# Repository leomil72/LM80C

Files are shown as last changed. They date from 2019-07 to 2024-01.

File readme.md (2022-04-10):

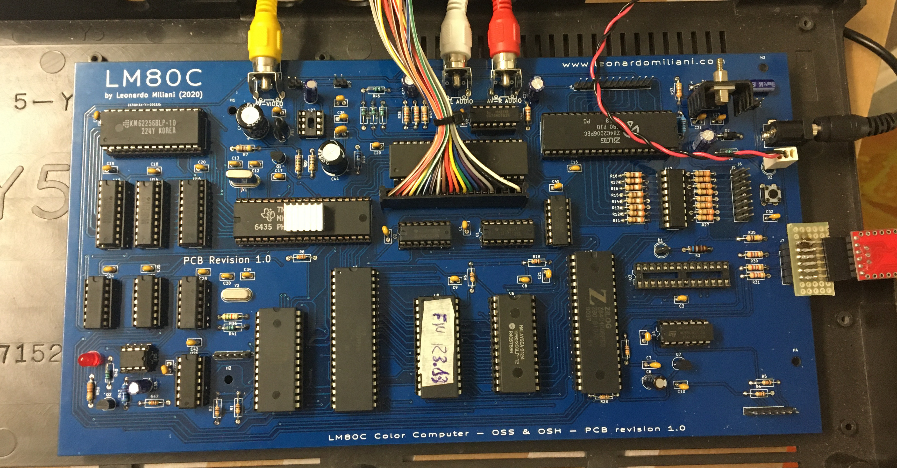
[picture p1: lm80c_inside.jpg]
LM80C, a Z80 -based computer LM80C, a Z80-based computer


# LM80C Color Computer - A Z80-based homebrew computer

> This is the official repo of the **LM80C Color Computer**, an 8-bit home computer based on the Z80 CPU entirely developed since 2019 by **Leonardo Miliani**. Here you can find schematics, code and other stuff that you can use to replicate this project and build your own homebrew computer as a sort of "back to the old, good, days of 8-bit systems".
>
> Project main page: [LM80C](https://www.leonardomiliani.com/?page_id=1534&lang=en)
>
> Tags: z80, zilog, homebrew, 8-bits, computer, lm80c, ctc, pio, sio, tms9918a, ay-3-8910, ym2149f

---

## Getting started

- [Overview](#overview)
- [What you need](#what-you-need)
- [Folder organization](#folder-organization)
- [Compilation](#compilation)
- [Emulation](#emulation)
- [Z88DK Support](#Z88DK-Support)
- [FAQ](#faq)
- [Support](#support)
- [Donations](#donations)
- [License](#license)

---

## Overview

The **LM80C** is an 8-bit home-computer built around the Zilog Z80 CPU with video and audio capabilities. It's a stand-alone system thanks to its integrated keyboard that permits to use it without the necessity of host computers, usually used as input/output devices in other similar projects. With the LM80C BASIC you can write your own games, programs, and much more.

### Models
Actually, there is only one model of the computer: the **LM80C 64K Color Computer**. Originally, there was also the **LM80C Color Computer** but it has been considered as DEPRECATED and its developmente and/or supporto has been cheased. There were a couple of differences between the two: the former only had 32KB of SRAM and an interface to SD cards based on an Atmega328P as a mass storage (never developed, my fault), while the latter has 64KB of SRAM and a new mass storage interface based on Compat Flash cards, perfectly supported.

### Main features

  **LM80C 64K Color Computer**

- CPU: Zilog Z80B@3.68 MHz
- Memory:
  - ROM: 32KB (with built-in firmware & BASIC)
  - RAM: 64KB SRAM
- Video:
  - TMS9918A with 32KB of dedicated VRAM (2x 16K banks)
  - composite output
  - 256x192 pixels, 15 colors, 32 sprites
- Audio:
  - Yamaha YM2149F (or GI AY-3-8910)
  - 3 analog channels with tone&noise generation
  - envelope control
  - 2x8-bit I/O ports
- I/O capabilities:
  - Z80 PIO:
    - parallel input/output periphery
    - 2x8-bit ports
    - 4 operatin modes
  - Z80 SIO:
    - serial input/output periphery
    - 2 serial ports
    - higly configurable
    - software-adjustable baude rates
  - Z80 CTC:
    - timer/counter with 4 channels
   - generate system ticks and baud rates
- Keyboard:
  - external keyboard with 64 keys (I used a Commodore 16 keyboard, that has 66 keys but only 64 unique keys due to double connections for SHIFT and SHIFT/LOCK)
- Mass storage:
  - support for Compact Flash memory cards
    - disk formatting/renaming
    - load/save/erase of BASIC, binary, and sequential files;

Thanks to the bank switching mechanism implemented into the computer, the machine can use the whole amount of 64KB of SRAM. The same mechanism is used to provide 2x 16K banks of VRAM to the VDP so that 2 entire video framebuffers can be loaded and stored into the VRAM.

**LM80C Color Computer** (DEPRECATED)

- CPU: Zilog Z80B@3.68 MHz
- Memory:
  - ROM: 32KB (with built-in firmware & BASIC)
  - RAM: 32KB SRAM
- Video:
  - TMS9918A with 16KB of dedicated VRAM
  - composite output
  - 256x192 pixels, 15 colors, 32 sprites
- Audio:
  - Yamaha YM2149F (or GI AY-3-8910)
  - 3 analog channels with tone&noise generation
  - envelope control
  - 2x8-bit I/O ports
- I/O capabilities:
  - Z80 PIO:
    - parallel input/output periphery
    - 2x8-bit ports
    - 4 operatin modes
  - Z80 SIO:
    - serial input/output periphery
    - 2 serial ports
    - higly configurable
    - software-adjustable baude rates
  - Z80 CTC:
    - timer/counter with 4 channels
   - generate system ticks and baud rates
- Keyboard:
  - external keyboard with 64 keys (I used a Commodore 16 keyboard, that has 66 keys but only 64 unique keys due to double connections for SHIFT and SHIFT/LOCK)
- More to come:
  - support for SD memory cards

*IMPORTANT NOTE*: due to the release of the LM80C 64K model, the development of the LM80C has been halted. At the moment, only software improvements for the LM80C BASIC are still developed and ported from the bigger brother. Since this downgrade to a minor model, the support for SD cards is not developed anymore. The PCB is basically still printable but please don't populate the SD interface portion with any of the components since none of them will be used.

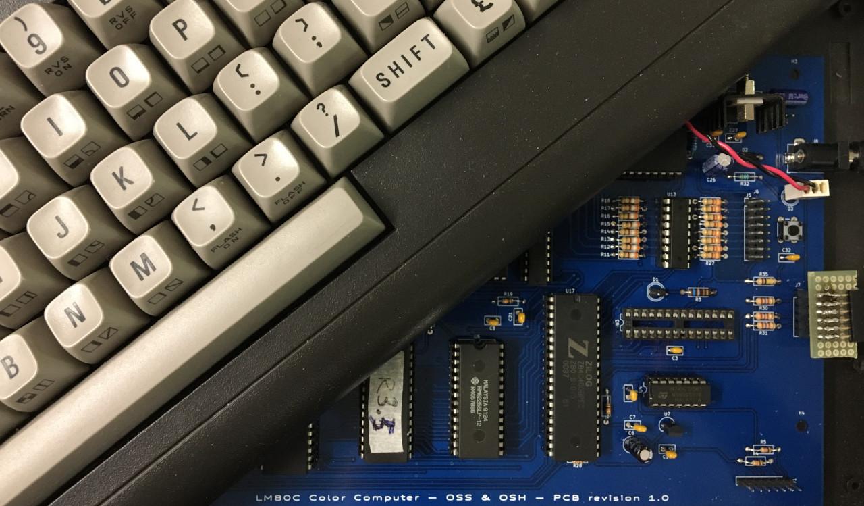
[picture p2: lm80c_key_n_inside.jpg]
LM80C motherboard inside its case


### BASIC

The **LM80C BASIC** is a dialect of the BASIC, a versatile and user-friendly programming language, the de-facto standard of the '80s since it was integrated into almost every 8-bit home computer. It derives from Nascom BASIC, that in turn derives from Microsoft Z80 BASIC 4.7. The LM80C BASIC is more than just a derivative language: in fact, it has its own set of commands and functions to take advantage of the specific LM80C hardware, like statements to draw point, lines, and circles, change foreground and background colors, move the cursor, play a tone or a noise, open/close the serial port, etc. It lets you to write good BASIC games, like "Lunar Lander", see below:
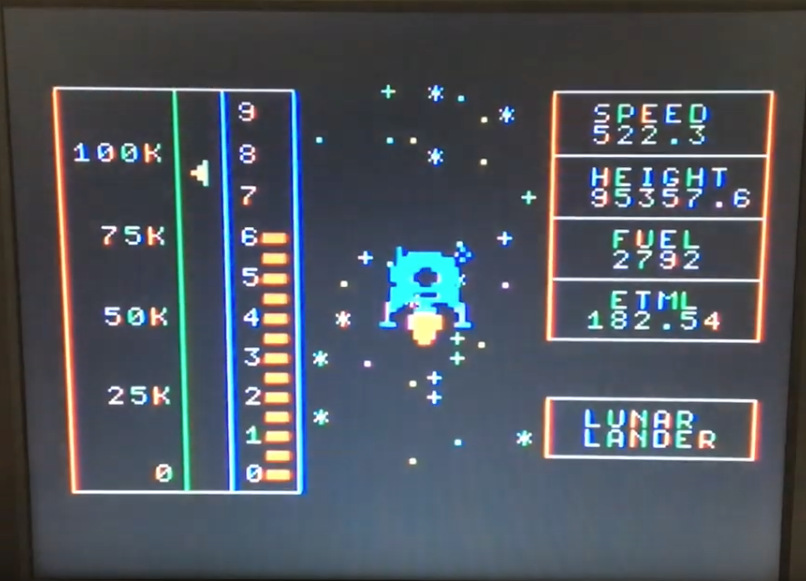
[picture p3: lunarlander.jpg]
Lunar Lander on LM80C


---

## What you need

Before to start building your own LM80C computer you need several things:
- of course, you need some hardware (electronic components, solder, breadboards, chips, etc.);
- some software (code editor & assembler);
- a CAD (to open schematics files and to generate Gerber files to make the PCB).
- some skills (you may be able to assemble a prototype, program it, burn a ROM file, etc.).

### Electronic parts
Passive electronic components can be grabbed anywhere: there are a lot of difference sources, like auction sites, big resellers, and local shops, too. The main chips, the Z80 family chips, are also widely available since the manufacturer, Zilogs, still continue to produce and commercialize them. More effort is needed to find the video and audio chips. The VDP and PSG are still available from China but, while the video chip is very common (in the past there has been over-production so a lot of spare components are still available), the audio chip is more rare and it is easy to find counterfit parts that doesn't work.

### Software
Personally I'm using [Visual Studio Code](https://code.visualstudio.com/) to write the ASM files: it's free, based on an open source project, and multi-platform (do not confuse with Visual Studio IDE). The extension to highlight the assembly code is [Z80 ASM](https://github.com/Imanolea/z80asm-vscode). Visual Code is a very complete editor and you can use for every language you use. Another good editor is [ATOM editor](https://atom.io) to edit the code, with [Language-assembler-SJASMPLUS](https://atom.io/packages/language-assembler-sjasmplus) package to highlight the Z80 assembly code. I prefer the former because it's lighter. 

To compile binaries I actually use [SJASMPlus](https://github.com/z00m128/sjasmplus), because it's multi-platform (MacOS/Linux/Windows) and has a lot of features, like macros, support for in-source LUA scripting, and much more. But you may use the assembler you want. However, for your commodity, the latest precompiled binary file, ready to be burned into an EEPROM, is always available.

To open/modify schematics you need a CAD: I use [KiCad](https://www.kicad.org/), that (IMHO) is the best choice, since it's free and doesn't have the limitations of the freeware version of [EagleCAD](https://www.autodesk.com/products/eagle/overview), that can't let you create a board bigger than 80 square cms., and the LM80C PCB is much bigger. However, I've also added PDF files if you just want to look at the schematics but don't want/need any additional software to open the schematics.

### Hardware
To burn the binaries on the (E)EPROM chips I used a modified version of [TommyPROM](https://github.com/leomil72/TommyPROM) so that I can use 74HCT595 shift registers, but you can use any (E)EPROM programmer you have. If you want to replicate my programmer, you need an [Arduino/Genuino Uno](https://www.arduino.cc) board. Please buy a *genuine board*, not a counterfit one, to help the open-source project. 

### Prototyping
I strongly recommend you to assemble a prototype on breadboards to be sure that everything is working right. The pictures below represent the LM80C during its development:
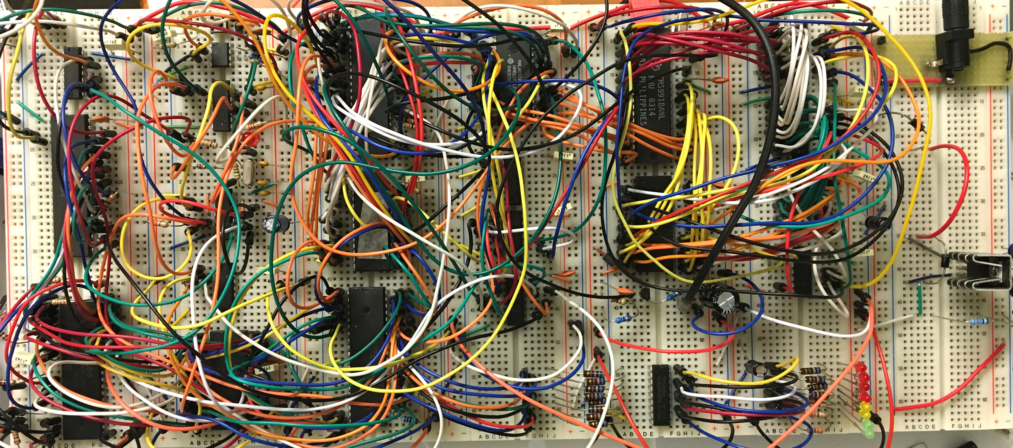
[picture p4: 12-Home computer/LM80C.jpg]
LM80C prototype, built upon breadboards


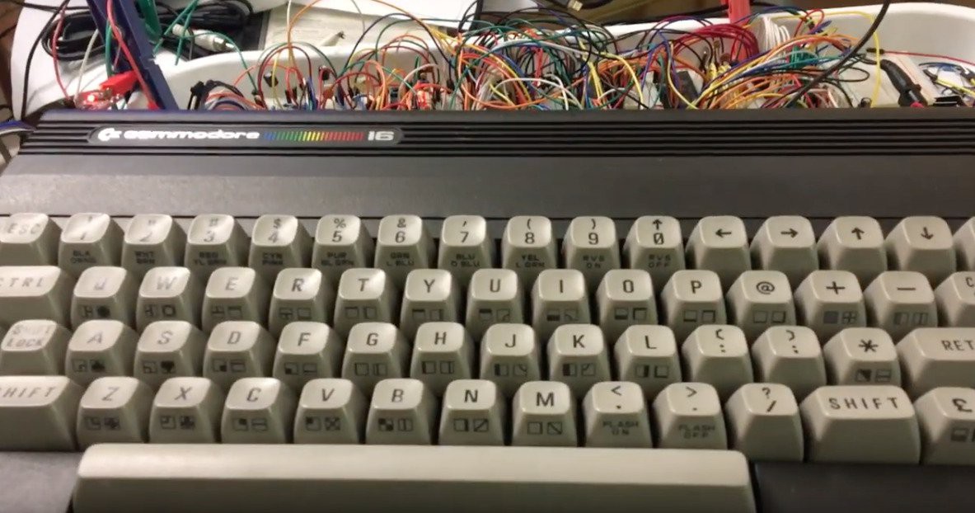
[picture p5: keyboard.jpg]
LM80C keyboard over the breaboards


---

## Folder organization
The files in this repo are organized in folders:
- "12-Home Computer": this folder contains the main ASM file to compile the latest firmwares of the LM80C/LM80C 64K Color Computer.
- "BASIC examples": this folder contains BASIC programs that can be loaded and executed with the integrated LM80C BASIC interpreter. If the name contains a release version (i.e. R20), it means it's the minimum firmware release required to run such program, because it makes use of some statements not present in previous releases.
-  "Legacy": old firmware are stored into this folder. Folders whose names start with "01-" through "09-" contain the first tests I made with the computer without the video section, that you can replicate to work solely through the serial line. Folders whose names start with "10-" and "11-" contain the releases that had preliminary support for video output. "Legacy cores" contains the old firmwares of the latest hardware version of the computer. Every release adds some functionality to the original BASIC. The greater the release number is, the newer the firmware is.
- "Rom": this folder contains pre-compiled binary files, ready to be burned into the EEPROM chip, and ".lst" files.
- "Schematics": this folder contains the KiCad files of the current hardware revision of the computer, plus some PDF files including the complete schematics of the computer.
- "include": this folder contains the sub-folders with the files needed to compile the firmware. They are: "basic", "bootloader","psg", and "vdp". Each sub-folder contains the file of the corresponding module.
- "manuals": this folder contains useful manuals for the CPU, the peripheral chips, the video and audio chips, and a couple of  files that illustrate the main features of the LM80C and the reference manual of the LM80C BASIC language.

---

## Compilation
To compile the firmware, first download or clone the repo on your computer, than go into the "12-Home computer" folder, copy inside it the executable of SJAsmPlus specific for your OS, open a terminal in it, then give this command:
`./sjasmplus --lst --lstlab LM80-firmware-rx.yy.asm`

`./sjasmplus --lst --lstlab LM80C_64K-firmware-rx.yy.asm`

where "X.YY" is the release you want to compile. After the compilation has finished, you'll find a file with extension `.bin` that you can burn into the EEPROM. Another file with extension `.lst` is created: this is useful to get addresses of entry point functions and memory registers.

---

## Emulation
There is an [LM80C online emulator](https://github.com/nippur72/lm80c-emu), written in Javascript by Antonino Porcino, that can be used to see how the real machine acts and works: you can test directly in your browser by opening [this link](https://nippur72.github.io/lm80c-emu/). 
These are the latest releases that can be launched:

[LM80C with Z88DK support](https://nippur72.github.io/lm80c-emu/?rom=314)

[LM80C 3.19 (latest firmware for 32K model)](https://nippur72.github.io/lm80c-emu/?rom=319)

[LM80C 64K (with integrated DOS)](https://nippur72.github.io/lm80c-emu/?rom=64K119)

---

## Z88DK Support
The latest releases of [Z88DK](https://github.com/z88dk/z88dk) support the compilation of C programs for LM80C Color Computer. You need to grab one of the nightly build. After the compilation, a file with extesion `.prg` is basically a big file composed by a BASIC file that is just a simple loader that start the execution of a bigger machine language program. At the moment the compiled files only support the version R3.14 of the LM80C Color Computer and can be launched in the emulator by simply draggind them into the emulator window once launched it and then by typing RUN.

## FAQ

- **How can I clone this repo?**
  - On your desktop computer, by using a GUI frontend like SmartGit, or via a terminal by typing the following command ```git clone https://github.com/leomil72/LM80C```
  - Online, by clicking on the "Fork" button
- **How can I download the files?**
  - By clicking the green top-right "Clone or Download" and then by clicking on "Download ZIP"
- **How do I write and compile an ASM source file?**
  - You need an editor to write the source code and then an 'assembler' to compile the binary file. Please look at the "Software" section above.
- **How do I burn the binary file into the EEPROM?**
  - You need an (E)EPROM programmer, a device that can be connected to your computer and that can write the data into the memory chip. You can buy a programmer from internet or build your own device like me.
- **Where can I find the chips you're using in the LM80C computer?**
  - Zilog still manufactures the Z80 family chips, so you can get them from almost any good reseller, or, alternatively, new/used parts can be catched from online auctions sites. The 74HCTxx integrated are very common, so you shouldn't have any problem to grab them. The VDP and PSG chips are only available as used parts from several eastern resellers. Pay attention that you can easily buy a counterfit chip so if it won't work, before to think that your computer is badly assembled, try another part.
- **The software seems not to be working/the hardware I built following your schematics doesn't work: where can I find help? Can I write to you?**
  - The project is released "as is", without any warranty/responsability: despite I've tested it and I'm currently using it, I can not guarantee that it is completely error-free, nor that it can run with no issues for a relitively long time, nor that there are no errors in the code/schematic files that are online. So, please do NOT write me to complain about something's not working. Open an "issue" or a "pull request". Thank you.

---

## Support

You can find more about me on my website at <a href="https://www.leonardomiliani.com/?lang=en" target="_blank">www.leonardomiliani.com</a>.

---

## Donations

- If you want to help me maintain my site, my projects, and keep me rolling on, you may consider to make a small donation with <a href="https://www.paypal.me/LeonardoMiliani" target="_blank">Paypal</a>.

---

## License

- Some portions of code are copyright <a href="http://searle.hostei.com/grant/" target="_blank">Grant Searle</a>
- Some portions of code are copyright <a href="http://www.train­z.de" target="_blank">Mario Blunk</a>
- BASIC code is copyright <a href="http://www.microsoft.com" target="_blank">Microsoft</a>
- Some commercial names (like KiCAD, EagleCAD, Visual Studio Code) lead to the corresponding owners.
- The rest of the stuff is my own work and is distribuited under the [Gnu GPL Licence 3.0](https://opensource.org/licenses/GPL-3.0).

The names "LM80C", "LM80C 64K", "LM80C Color Computer", "LM80C 64K Color Computer", and "LM80C BASIC", the "rainbow LM80C" logo, the LM80C schematics, the LM80C sources, and this work belong to Leonardo Miliani. 

The "rainbow LM80C" logo and the "LM80C/LM80C Color Computer/LM80C 64K/LM80C 64K Color Computer" names can not be used in any work without my explicit permission. You are allowed to use the "LM80C" and "LM80C 64K" names only in reference to or to describe the LM80C/LM80C 64K Color Computers.

The LM80C/LM80C 64K schematics and source codes are released under the GNU GPL License 3.0 and in the form of "as is", without any kind of warranty: you can use them at your own risk. You are free to use them for any non-commercial use: you are only asked to maintain the copyright notices, to include this advice and, if you intend to re-distribute them, the note to the attribution of the original works to Leonardo Miliani. For any other use, please contact me by opening an issue.

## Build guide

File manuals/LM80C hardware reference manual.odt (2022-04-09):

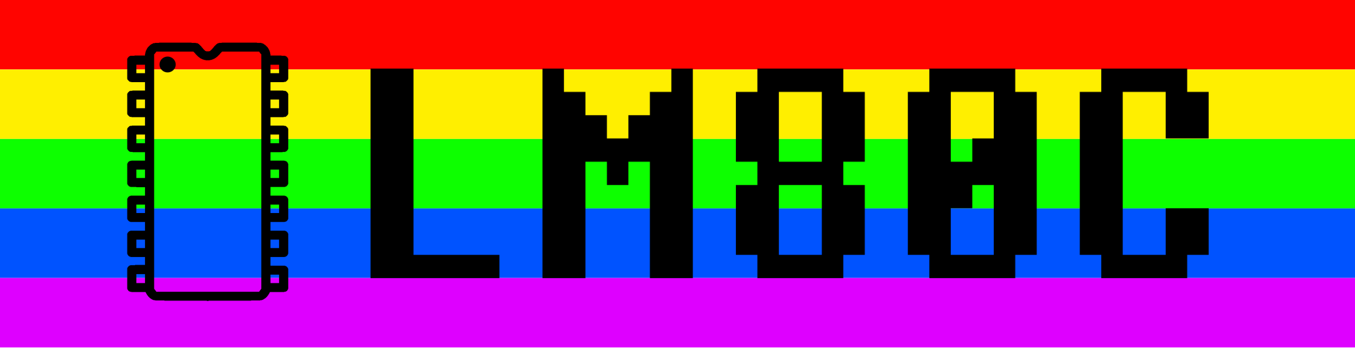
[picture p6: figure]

HARDWARE

REFERENCE MANUAL

LM80C COLOR COMPUTER &

LM80C 64K COLOR COMPUTER

HARDWARE REFERENCE MANUAL

This release covers the

LM80C Color Computer

and

LM80C 64K Color Computer

Latest revision on 09/04/2022

### Copyright notices:

The names “LM80C”, “LM80C Color Computer”, “LM80C BASIC”, and “LM80C DOS”, the “rainbow LM80C” logo, the LM80C schematics, the LM80C sources, and this work belong to Leonardo Miliani, from here on the “owner”.

The “rainbow LM80C” logo and the “LM80C/LM80C Color Computer/LM80C 64K Color Computer” names can not be used in any work without explicit permission of the owner. You are allowed to use the “LM80C” name only in reference to or to describe the LM80C/LM80C 64K Color Computer.

The LM80C and LM80C 64K schematics and source codes are released under the GNU GPL License 3.0 and in the form of "as is", without any kind of warranty: you can use them at your own risk. You are free to use them for any non-commercial use: you are only asked to maintain the copyright notices, to include this advice and the note to the attribution of the original works to Leonardo Miliani, if you intend to re-distribute them. For any other use, please contact the owner.

# 1. THE LM80C COLOR COMPUTER

## 1.1 Why this computer

The LM80C Color Computer is an home-brew computer designed and programmed by me, Leonardo Miliani, an Italian retro-computer enthusiast, in an effort to have my own, old-stile, 80s' computer. It is built upon the Z80, an 8-bit CPU developed in the '70s by Zilog. The name LM80C stands for "L"eonardo "M"iliani (Z)"80" "C"olor. The “80” has the double meaning of “Z80”, to recall the CPU it is built on, and “80s”, to recall the years of my youth, when the 8-bit computers dominated the home computer market.

## 1.2 LM80C: main features

The LM80C might have been a good computer at that time. In fact, its features are as follow:

- CPU: Zilog Z80B@3.68 MHz
- RAM: 32 KB SRAM
- ROM: 32 KB EEPROM with built-in LM80C BASIC
- Video: TMS9918A with 16 KB VRAM, 256×192 pixels, 15 colors, and 32 sprites
- Audio: Yamaha YM2149F (or General Instruments AY-3-8910) with 3 analog channels, 2×8-bit I/O ports (used to read the external keyboard)
- Serial I/O: 1×Z80 SIO, with serial line up to 57,600 bps
- Parallel I/O: 1×Z80 PIO
- Timer: 1×Z80 CTC
- Compact Flash adapter for CF cards

IMPORTANT NOTE: due to the better technical specifications & performances of the LM80C 64K, the LM80C Color Computer has been DISCONTINUED and it won’t be developed anymore. New users should start using the LM80C 64K model while for current users of LM80C it is recommended to switch to the bigger model to get advantage of its features.

## 1.3 LM80C 64K: main features

The LM80C 64K Color Computer is almost identical to its little brother. The main difference, as its name reveals, is the amount of RAM, expanded to 64 KB. Another difference is the ability to use 2x 16K banks for VRAM, allowing the VDP to keep 2 different video pages into memory:

- CPU: Zilog Z80B@3.68 MHz
- RAM: 64 KB SRAM
- ROM: 32 KB EEPROM with built-in LM80C BASIC
- Video: TMS9918A with 32 KB VRAM (splitted into 2×16 KB banks), 256×192 pixels, 15 colors and 32 sprites
- Audio: Yamaha YM2149F (or General Instrument AY-3-8910) with 3 analog channels, 2×8-bit I/O ports (used to read the external keyboard)
- Serial I/O: 1×Z80 SIO, with serial line up to 57,600 bps
- Parallel I/O: 1×Z80 PIO
- Timer: 1×Z80 CTC
- Compact Flash adapter for CF cards

## 1.4 The 64K version: bank switching

The LM80C 64K Color Computer has 64 KB of RAM and 32 KB of (EEP)ROM. Due to the 16-bit address bus limitations of the CPU, only 64 KB can be directly addressed. To go around this limit a sort of bank switching has been implemented.

ROM occupies the first 32 KB of the address space, from $0000 to $7FFF. The RAM is formed by 2×16 KB banks, lower and upper bank, or simply bank #0 and bank #1: bank #1 occupies the address space from $8000 to $FFFF while bank #0 occupies the same address space of the non-volatile memory but it’s not enabled by default. When you power up the system or after a reset, the Z80 jumps to address $0000, so the CPU have to find ROM memory at bank #0. Now comes in action the bank switching technique implemented: after the start, the CPU executes a little portion of code called the “switcher”, that copies the whole firmware from ROM bank #0 to RAM bank #1. Then, it disables the ROM in bank #0 and enables the underlying RAM chip, switching to a real 64 KB RAM memory. After this, it copies back the BASIC firmware from RAM bank #1 to RAM bank #0, so that the firmware goes back to occupy its original location. Only the DOS remains in the higher portion of RAM, because it can be enabled/disabled at startup (see ch. 1.5).

Obviously, the entire RAM is available for user programs since he/she can overwrite the built-in firmware since it runs in a re-writeble memory.

## 1.5 System start-up

At startup the Z80 loads the address $0000 into the PC (Program Counter) and start initializing the HW of the computer. After each peripheral has been set up, the control passes to the bank switcher, which moves the BASIC interpreter and the whole firmware from RAM to ROM, After this, the BASIC interpreter checks if this is a cold start (i.e. after a power-up): if this isn't such case, it asks the user if he/she wants to perform a cold or warm start: the first one initializes the working space like at boot, deleting every possible program still resident in RAM and clearing every variable, while the latter preserves both these data.

If, while the logo has been showed at video, the user presses the RUN/STOP key, the firmware re-boot the system again and re-copy the firmware from the ROM into the RAM. This is useful if, some reason (“playing” with some POKEs around the system memory), the computer has began unstable.

Another key that can be pressed while the logo is on video is CTRL: by pressing it, the LM80C DOS will be disabled and the RAM occupied by its buffers will be freed up, recovering about 4.5 KB of memory. Pay attention that when disabled, the DOS will remain disabled until a hard-reset or a power off will take place.

At the end of the startup process, the control is passed to the BASIC interpreter in direct mode: this means that the computer is able to execute commands as soon as they are entered.

## 1.6 Hard reset, mild reset, and soft reset

The computer is provided with 2 different reset systems. The hard reset is called by pressing the reset button: this corresponds to a complete reset of any of the integrated circuits on the mother board of the computer since all of them receive the reset signal on their reset pins: this signal forces them to revert to their initial state. The BASIC environment is reset to its default status, too.

The mild reset is called by executing the RESET statement. This command forces the CPU to jump to execute the firmware code from its initial location. This doesn’t correspond to a hard reset because the integrated circuits don’t receive the reset signal on their corresponding pins: instead, it completely resets the BASIC environment to its default state.

The soft reset is called by pressing the C= and CTRL keys together. This shortcut is intercepted by the firmware and forces the system to: reset the BASIC environment, clear the variables and the system stack, set the screen to graphic mode 1, re-initialize the PSG, close any seq. file still opened, reset the serial lines, and return to the BASIC prompt. Furthermore, the program into memory is NOT deleted.

# 2. I/O PORTS

Peripheral I/O chips have their I/O channels mapped at the following logical ports:

PIO:

- PIO data channel A: $00
- PIO data channel B: $01
- PIO control channel A: $02
- PIO control channel B: $03

CTC:

- CTC channel 0: $10
- CTC channel 1: $11
- CTC channel 2: $12
- CTC channel 3: $13

SIO:

- SIO data channel A: $20
- SIO data channel B: $21
- SIO control channel A: $22
- SIO control channel B: $23

VDP:

- VDP data port: $30
- VDP control port:
  - 32K version: $32
  - 64K version: $31

PSG:

- PSG register port: $40
- PSG data port: $41

CF card:

- CF data (reg. #0): $50 (R/W)
- CF error (reg. #1): $51 (R)
- CF features (reg. #1): $51 (W)
- CF sector count reg. (reg. #2): $52 (R/W)
- CF LBA reg. 0 (reg. #3): $53 (bits 0-7) (R/W)
- CF LBA reg. 1 (reg. #4): $54 (bits 8-15) (R/W)
- CF LBA reg. 2 (reg. #5): $55 (bits 16-23) (R/W)
- CF LBA reg. 3 (reg. #6): $56 (bits 24-27) (R/W)
- CF status (reg. #7): $57 (R)
- CF command (reg. #7): $57 (W)

The user can control these chips directly by reading/writing from/to the ports listed above.

# 3. INTERRUPTS & JUMP VECTORS

Several interrupt & jump vectors are stored into ROM:

- $0000 RESET: Z80 jumps here after a reset or at power-up
- $0004 INT vector for SIO RX_CHB_AVAILABLE interrupt signal
- $0006 INT vector for SPEC_RXA_CONDITION (special receive condition) interrupt signal
- $0008 RST8: this restart calls a function that sends a char via serial
- $000C INT vector for SIO RX_CHA_AVAILABLE interrupt signal
- $000E INT vector for SIO SPEC_RX_CONDITION (special receive condition) interrupt signal
- $0010 RST10: this restart jumps to a function that receives a char from the input buffer (serial and/or keyboard)
- $0018 RST18: jumps to function that checks if a char is available in the input buffer
- $0040 CTC CH0: jumps to CTC0IV (see below) - unused
- $0042 CTC CH1: jumps to CTC1IV (see below) - unused
- $0044 CTC CH2: jumps to CTC2IV (see below) - unused
- $0046 CTC CH3: jumps to CTC3IV (see below) - used by system
- $0066 NMI IRQ: jumps to NMIUSR (see below) - unused

# 4. RAM REGISTERS

The LM80C uses some RAM cells to store important information and data.⁽¹⁾ By manually writing into these locations the user can alter the functioning of the system, sometimes leading to crashes and/or non-predictable behaviors.

## 4.1 REGISTERS FOR LM80C AS PER FIRMWARE REVISION 3.23

805E WRKSPC (3) BASIC Work space

8061 NMIUSR (3) NMI exit point routine

8064 USR (3) "USR (x)" jump

8067 OUTSUB (1) "out p,n"

8068 OTPORT (2) Port (p)

806A DIVSUP (1) Division support routine

806B DIV1 (4) <- Values

806F DIV2 (4) <- to

8073 DIV3 (3) <- be

8076 DIV4 (2) <-inserted

8078 SEED (35) Random number seed

809B LSTRND (4) Last random number

809F INPSUB (1) INP A,(x) Routine

80A0 INPORT (2) PORT (x)

80A2 LWIDTH (1) Terminal width

80A3 COMMAN (1) Width for commas

80A4 NULFLG (1) Null after input byte flag

80A5 CTLOFG (1) Control "O" flag

80A6 CHKSUM (2) Array load/save check sum

80A8 NMIFLG (1) Flag for NMI break routine

80A9 BRKFLG (1) Break flag

80AA RINPUT (3) Input reflection

80AD STRSPC (2) Pointer to bottom (start) of string space

80AF LINEAT (2) Current line number

80B1 HLPLN (2) Current line with errors

80B3 KEYDEL (1) delay before key auto-repeat starts

80B4 AUTOKE (1) Delay for key auto-repeat

80B5 FNKEYS (128) default text of FN keys

8135 BASTXT (3) Pointer to start of BASIC program in memory

8138 BUFFER (5) Input buffer

813D STACK (85) Initial stack

8192 CURPOS (1) Character position on line

8193 LCRFLG (1) Locate/Create flag for DIM statement

8194 TYPE (1) Data type flag

8195 DATFLG (1) Literal statement flag

8196 LSTRAM (2) Last available RAM location usable by BASIC

8198 DOSBFR (2) Pointer to start of temp. DOS buffer

819A IOBUFF (2) Pointer to start of I/O buffer used by DOS

819C DOSER (1) DOS error

819D TMPDBF (36) Secondary buffer for DOS

81C0 TMSTPT (2) Temporary string pointer

81C2 TMSTPL (12) Temporary string pool

81CE TMPSTR (4) Temporary string

81D2 STRBOT (2) Bottom of string space

81D4 CUROPR (2) Current operator in EVAL

81D6 LOOPST (2) First statement of loop

81D8 DATLIN (2) Line of current DATA item

81DA FORFLG (1) "FOR" loop flag

81DB LSTBIN (1) Last byte entered

81DC READFG (1) Read/Input flag

81DD BRKLIN (2) Line of break

81DF NXTOPR (2) Next operator in EVAL

81E1 ERRLIN (2) Line of error

81E3 CONTAD (2) Where to CONTinue

81E5 TMRCNT (4) TMR counter for 1/100 seconds

81E9 CTC0IV (3) CTC0 interrupt vector

81EC CTC1IV (3) CTC1 interrupt vector

81EF CTC2IV (3) CTC2 interrupt vector

81F2 CTC3IV (3) CTC3 interrupt vector

81F5 SCR_SIZE_W (1) screen width

81F6 SCR_SIZE_H (1) screen height

81F7 SCR_MODE (1) screen mode

81F8 SCR_NAM_TB (2) video name table address

81FA SCR_CURS_X (1) cursor X

81FB SCR_CURS_Y (1) cursor Y

81FC SCR_CUR_NX (1) new cursor X position

81FD SCR_CUR_NY (1) new cursor Y position

81FE SCR_ORG_CHR(1) original char positioned under the cursor

81FF CRSR_STATE (1) state of cursor

8200 LSTCSRSTA (1) last cursor state

8201 PRNTVIDEO (1) print on video buffer

8202 CHR4VID (1) char for video buffer

8203 FRGNDCLR (1) foreground color

8204 BKGNDCLR (1) background color

8205 TMPBFR1 (2) word for general purposes use

8207 TMPBFR2 (2) word for general purposes use

8209 TMPBFR3 (2) word for general purposes use

820B TMPBFR4 (2) word for general purposes use

820D VIDEOBUFF (40) temp. video buffer

8235 VIDTMP1 (2) additional temp. video buffer

8237 VIDTMP2 (2) additional temp. video buffer

8239 CHASNDDTN (2) sound Ch.A duration

823B CHBSNDDTN (2) sound Ch.B duration

823D CHCSNDDTN (2) sound Ch.C duration

823F KBDNPT (1) temp. location for keyboard inputs

8240 KBTMP (1) temp. location used by keyboard scanner

8241 TMPKEYBFR (1) temp. location used for last key pressed

8242 LASTKEYPRSD(1) code of last key pressed

8243 STATUSKEY (1) status key, used for auto-repeat

8244 KEYTMR (2) timer used for auto-repeat key

8246 CONTROLKEYS(1) flags for control keys

8247 SERIALS_EN (1) serial ports status

8248 SERABITS (1) serial port A data bits

8249 SERBBITS (1) serial port B data bits

824A DOS_EN (1) DOS enable/disable (1/0)

824B PROGND (2) End of program

824D VAREND (2) End of variables

824F ARREND (2) End of arrays

8251 NXTDAT (2) Next data item

8253 FNRGNM (2) Name of FN argument

8255 FNARG (4) FN argument value

8259 FPREG (3) Floating point register

825C FPEXP (1) Floating point exponent

825D SGNRES (1) Sign of result

825E PBUFF (13) Number print buffer

826B MULVAL (3) Multiplier

826E PROGST (100) Start of program text area

82D2 STLOOK Start of memory test

## 4.2 REGISTERS FOR LM80C 64K AS PER FIRMWARE REVISION 1.19

5401 | WRKSPC | (3) BASIC Work space
5404 | NMIUSR | (3) NMI exit point routine
5407 | USR | (3) "USR (x)" jump
540A | OUTSUB | (1) "out p,n"
540B | OTPORT | (2) Port (p)
540D | DIVSUP | (1) Division support routine
540E | DIV1 | (4) <- Values
5412 | DIV2 | (4) <- to
5416 | DIV3 | (3) <- be
5419 | DIV4 | (2) <-inserted
541B | SEED | (35) Random number seed
543E | LSTRND | (4) Last random number
5442 | INPSUB | (1) #INP (x)" Routine
5443 | INPORT | (2) PORT (x)
5445 | LWIDTH | (1) Terminal width
5446 | COMMAN | (1) Width for commas
5447 | NULFLG | (1) Null after input byte flag
5448 | CTLOFG | (1) Control "O" flag
5449 | CHKSUM | (2) Array load/save check sum
544B | NMIFLG | (1) Flag for NMI break routine
544C | BRKFLG | (1) Break flag
544D | RINPUT | (3) Input reflection
5450 | STRSPC | (2) Pointer to bottom (start) of string space
5452 | LINEAT | (2) Current line number
5454 | HLPLN | (2) Current line with errors
5456 | KEYDEL | (1) delay before key auto-repeat starts
5457 | AUTOKE | (1) Delay for key auto-repeat
5458 | FNKEYS | (128) default text of FN keys
54D8 | BASTXT | (3) Pointer to start of BASIC program in memory
54DB | BUFFER | (5) Input buffer
54E0 | STACK | (85) Initial stack
5535 | CURPOS | (1) Character position on line
5536 | LCRFLG | (1) Locate/Create flag for DIM statement
5537 | TYPE | (1) Data type flag
5538 | DATFLG | (1) Literal statement flag
5539 | LSTRAM | (2) Last available RAM location usable by BASIC
553B | DOSER | (1) DOS error
553C | TMPDBF | (36) Secondary buffer for DOS
5560 | TMSTPT | (2) Temporary string pointer
5562 | TMSTPL | (12) Temporary string pool
556E | TMPSTR | (4) Temporary string
5572 | STRBOT | (2) Bottom of string space
5574 | CUROPR | (2) Current operator in EVAL
5576 | LOOPST | (2) First statement of loop
5578 | DATLIN | (2) Line of current DATA item
557A | FORFLG | (1) "FOR" loop flag
557B | LSTBIN | (1) Last byte entered
557C | READFG | (1) Read/Input flag
557D | BRKLIN | (2) Line of break
557F | NXTOPR | (2) Next operator in EVAL
5581 | ERRLIN | (2) Line of error
5583 | CONTAD | (2) Where to CONTinue
5585 | TMRCNT | (4) TMR counter for 1/100 seconds
5589 | CTC0IV | (3) CTC0 interrupt vector
558C | CTC1IV | (3) CTC1 interrupt vector
558F | CTC2IV | (3) CTC2 interrupt vector
5592 | CTC3IV | (3) CTC3 interrupt vector
5595 | SCR_SIZE_W | (1) screen width
5596 | SCR_SIZE_H | (1) screen height
5597 | SCR_MODE | (1) screen mode
5598 | SCR_NAM_TB | (2) video name table address
559A | SCR_CURS_X | (1) cursor X
559B | SCR_CURS_Y | (1) cursor Y
559C | SCR_CUR_NX | (1) new cursor X position
559D | SCR_CUR_NY | (1) new cursor Y position
559E | SCR_ORG_CHR | (1) original char under the cursor
559F | CRSR_STATE | (1) state of cursor (1=on, 0=off)
55A0 | LSTCSRSTA | (1) last cursor state
55A1 | PRNTVIDEO | (1) print on video buffer
55A2 | CHR4VID | (1) char for video buffer
55A3 | FRGNDCLR | (1) foreground color
55A4 | BKGNDCLR | (1) background color
55A5 | TMPBFR1 | (2) word for general purposes use
55A7 | TMPBFR2 | (2) word for general purposes use
55A9 | TMPBFR3 | (2) word for general purposes use
55AB | TMPBFR4 | (2) word for general purposes use
55AD | VIDEOBUFF | (40) temp. video buffer
55D5 | VIDTMP1 | (2) temporary video word
55D7 | VIDTMP2 | (2) temporary video word
55D9 | CHASNDDTN | (2) sound Ch.A duration (in 1/100s)
55DB | CHBSNDDTN | (2) sound Ch.B duration (in 1/100s)
55DD | CHCSNDDTN | (2) sound Ch.C duration (in 1/100s)
55DF | KBDNPT | (1) temp. location for keyboard inputs
55E0 | KBTMP | (1) temp. location used by keyboard scanner
55E1 | TMPKEYBFR | (1) temp buffer for last key pressed
55E2 | LASTKEYPRSD | (1) last key code pressed
55E3 | STATUSKEY | (1) status key, used for auto-repeat
55E4 | KEYTMR | (2) timer used for auto-repeat key
55E6 | CONTROLKEYS | (1) flags for control keys
55E7 | SERIALS_EN | (1) serial ports status
55E8 | SERABITS | (1) serial port A data bits
55E9 | SERBBITS | (1) serial port B data bits
55EA | DOS_EN | (1) DOS enable/disable (1/0)
55EB | PROGND | (2) End of program
55ED | VAREND | (2) End of variables
55EF | ARREND | (2) End of arrays
55F1 | NXTDAT | (2) Next data item
55F3 | FNRGNM | (2) Name of FN argument
55F5 | FNARG | (4) FN argument value
55F9 | FPREG | (3) Floating point register
55FC | FPEXP | (1) Floating point exponent
55FD | SGNRES | (1) Sign of result
55FE | PBUFF | (13) Number print buffer
560B | MULVAL | (3) Multiplier
560E | PROGST | (100) Start of program text area
5672 | STLOOK | Start of memory test

WRKSPC: workspace. This is a jump to “Warm start” routine

USR: user-defined function USR(X). Before to call it, locations USR+$01 and USR+$02 must be filled up with the address of the user routine. At startup, the default is a call to an “Illegal function call” error.

OUTSUB: out sub-routine. Since the i8080 didn’t have the “OUT(c),r” instruction, this was a skeleton for such statement. Now it’s a sub-routine to write to a specific output port.

OTPORT: output port “c” for the above routine.

DIVSUP: skeleton routine used for division. Since there aren’t enough register to store dividend, divisor and quotient, the divisor is loaded into this routine, to leave registers free for dividend and quotient.

SEED: seed for random number generator and table for floating point values used by RND function.

LSTRND: last random number is stored (available by RND(0)).

INPSUB: input sub-routine. Since the i8080 didn’t have the “IN r,(c)” instruction, this was a routine that read from an input port. Actually, just a sub-routine for “IN” statement.

INPORT: input port “c” for the above routine.

NULLS: nulls. Number of null chars printed after a carriage return. The original NASCOM BASIC had the command “NULL” to change this value, but now it can only be changed with a “POKE”.

LWIDTH: terminal width, set by “WIDTH”.

COMMAN: width of terminal for printing with commas. Since “WIDTH” does set LWIDTH but does NOT set COMMAN, the only way to get commas spacing work correctly is just using a POKE.

NULFLG: null after input flag. Reminiscence of old terminal computers, where this command was used to set the number of null chars to send to teletype before printing any char.

CTLOFH: flag for Control+”O”. When this flag is set, no output will be sent to the terminal.

LINESC: lines counter. Initially loaded with the value of LINESM, it is decremented after every line. When it reaches zero, the BASIC interpreter stops waiting for a char from the keyboard.

LINESN: lines number. Used for LINESC. It can be changed with a POKE.

CHKSUM: checksum used for array load/save (NASCOM BASIC legacy).

NMIFLG: Non-Maskable Interrupt flag. This is used to inform the BASIC that is has been interrupted by an NMI.

BRKFLG: break flag, to let BASIC know that the break key was pressed.

RINPUT: Reflection for “INPUT” routine. When an “INPUT” instruction is encountered, BASIC jumps to the input routine pointed by this jump. Default is jump to “TTYLIN”, aka get a line by character. This can be changed to “CRLIN” (outpur CR/LF and get a line), or “GETLIN” (no CR/LF, get a line).

STRSPC: start of string space pointer, the area where BASIC stores strings. By default, it is set 100 bytes below the end of memory but this value can be changed by the “CLEAR n” statement.

LINEAT: current line number. This pair of bytes contains the value of the current line being executed. A value is -1 means that BASIC is executing a statement in direct mode. A value of -2 means that the computer has been reset and it’s executing the routine to calculate the memory size or, in case it can not determine the amount of RAM, the “Memory size?” routine. If the user doesn’t input a number, -2 instructs the error routine that an error has occurred and that a cold start must be executed.

HLPLN: help line. Current line that has raised an error during the execution of a BASIC program. This value is read by “HELP” statement, and reset after a program restart (“RUN”) or by another error in direct mode.

KEYDEL: delay before the key auto-repeat starts repeating the pressed key.

AUTOKE: Delay for key auto-repeat between two prints.

FNKEYS: function keys. This area stores the text of function keys. 8 function keys are present and can be individually programmed with user defined statements, whose length can be up to 16 chars. Please refer to LM80C BASIC Reference Manaul” to know the pre-configured texts.

BASTXT: BASIC program text. Pointer to where the BASIC is stored in memory. Usually this reflects the contents of PROGST and both point to the BASIC program area, but it can be changed by the user is a program is loaded elsewhere into RAM.

BUFFER: input buffer. 88 char buffer where the system stores all the input from the keyboard or the serial line.

STACK: temporary stack used during boot of system.

CURPOS: cursor position. This value keeps the cursor position through the current line and ir is incremented every time a new char has been inserted. It is the value returned by “POS(x)” statement . A press on the “RETURN” key resets this value.

LCRFLG: Locate/Create flag. Value used by the variable search routine to see if it’s in a “DIM” statement or not, so that it can determine if it has to locate or create the specified array.

TYPE: type of data of the current expression. A zero value stands for a numeric type, while a non-zero value for a string.

DATFLG: literal statement flag. It’s used by the BASIC to know if it’s pointing at a literal statement such as a quoted string, a “REM” or a “DATA” statement.

LSTRAM: last available RAM pointer. Address of last location available to BASIC. It can be changed by “CLEAR n” statement.

DOSBFR: pointer to beginning of a 32-byte temporary buffer used by DOS in disk input/output operations. The DOS buffer is stored just below the I/O buffer.

IOBUFF: pointer to beginning of a 512-byte buffer used by DOS to store a sector loaded by disk or to assemble data to save into a sector. The I/O is stored in the highest portion of RAM (from $FFFF downwards).

DOSER: error returned by DOS functions.

TMPDBF: secondary 36-byte buffer used by DOS to execute statements.

TMSTPT: temporary string pointer used to point a string into the temporary string pool.

TMSTPL: temporary string pool. This pool contains 4 temporary strings that are created by string statements like “LEFT$” and others.

TMPSTR: temporary string. This is a temporary area where BASIC stores blocks of bytes that reference to the strings being constructed. Every string block consists of 4 bytes: the first byte stores the length of string; the second byte is not used; the last two bytes form the pointer to the location in memory where the string is stored.

STRBOT: bottom of string space. This value points to the bottom of the string being used. Each time a new string is being formed, it is moved into the string area below this pointer that the pointer is decremented and moved below the new string. If there is not enough space for the new string, than a “garbage collector” is called to remove unused strings from the string space. If, after this cleaning, there is still not enough room, then an “Out of string space error” is raised.

CUROPR: current operator address. Pointer to the current operator being evaluated in EVAL. This pointer is used to free the CPU register used to point to the current operator being analyzed and to avoid to store it into the stack, so that both can be used to simplify the evaluation of the operator.

LOOPST: loop start address. Pointer to the first statement in the FOR loop being constructed. This address is later moved into the FOR block on the stack .

DATLIN: data statement line number. This register contains the line number of the current DATA statement pointer. It’s used by DATSNR to report to the user the line where a DATA error has occurred.

FORFLG: “FOR”/”FN” flag. Flag to tell what GETVAR is expected to find:

$00: a variable or array element

$01: an array name

$64: a variable only

$80: an FN function

LSTBIN: last byte entered. Flag being set whenever any input is made into the BUFFER. The RETURN routine first checks this byte to see if a GOSUB was entered into direct mode, and if so checks this flag. If the flag is set, then this means that an INPUT statement has been encountered, and so after RETURN is executed, BUFFER contains garbage and the system returns into direct mode.

READFG: read/input flag. This flag tells the READ/INPUT routine what’s the source of the data being read. If the flag is zero, then an INPUT is being executed, otherwise it’s a READ reading from a DATA statement.

BRKLIN: break line pointer. Address of the line where a break occurred. This value is used by CONT to know where to continue the execution of the program.

NXTOPR: next operator address. Pointer into the expression being evaluated by EVAL to know where the execution is in the string.

ERRLIN: line number of break. This register contains the line number where a break occurred. Used by CONT to know the line number where to continue from.

CONTAD: continue address. Address of the statement where CONT will continue.

TMRCNT: timer counter. This is a 32-bit hundredths of a second counter used as a sys-tick timer to temporize events such as sound duration, pauses and other. Its value is incremented every 1/100 s and can be read by the TMR statement.

CTCxIV: CTC interrupt vectors. Interrupt vectors that can be changed to point the CTC interrupts to specifics interrupt service routines. CTC3IV is used be the kernel of the computer to temporize some jobs (see TMRCNT above).

SCR_SIZE_W: screen width. This register stores the screen width of the current screen mode. See chap. 8 for more details.

SCR_SIZE_H: screen height. This register stores the screen height of the current screen mode. See chap. 8 for more details.

SCR_MODE: screen mode. Current screen mode. This value reflects the mode set by SCREEN statement.

SCR_NAM_TB: screen name table address. VRAM address of the name table being used by the current screen mode. See chap. 8 for more details.

SCR_CURS_X: current cursor X coordinate. Keeps the current horizontal coordinate of the cursor in a text mode (screen 0, 1, & 4).

SCR_CURS_Y: current cursor Y coordinate. Keeps the current vertical coordinate of the cursor in a text mode (screen 0, 1, & 4).

SCR_CUR_NX: new cursor X coordinate. Keeps the horizontal coordinate of the video cell that the cursor is going to occupy when being moved.

SCR_CUR_NY: new cursor Y coordinate. Keeps the vertical coordinate of the video cell that the cursor is going to occupy when being moved.

SCR_ORG_CHR: original char under the cursor. Register used to store the original char present in the video cell currently occupied by the cursor. It is used to restore the char during cursor flashing or when the cursor is moved into another location.

CRSR_STATE: cursor state. Flag used to tell BASIC is the cursor is visible (1) or not (0).

LSTCSRSTA: last cursor state. Flag used to store the current cursor state, i.e. when executing PRINT statements or when the cursor is moved around the screen.

PRNTVIDEO: print on video buffer flag. Used to tell the BASIC if keys being pressed can be echoed on the screen or not. Usually, printing on video is off when in indirect mode (i.e. when a program is being executed).

CHR4VID: char for video buffer. Temporary buffer that stores a char that must be printed on the screen.

FRGNDCLR: foreground color. Foreground color set by SCREEN statement. The default value can also be changed with COLOR statement. Used to print chars on screen or to draw/plot figures/pixels on the graphic screen when no color is being specified.

BKGNDCLR: background color. Background color set by SCREEN statement. The default value can also be changed with COLOR statement. Used for the background of the chars being printed on screen or to color the empty area of the graphic screen

TMPBFRx: temporary buffer. 4 words used by the kernel and BASIC as temporary buffers.

VIDEOBUFF: temporary video buffer. 40 RAM cells used by the kernel and BASIC for video scrolling in text modes and as temporary buffer.

VIDTMPx: temporary video buffer. 2 additional buffers used by the firmware and BASIC.

CHASNDDTN: channel A sound duration. Duration of the sound being generated by ch. A of the PSG, in hundredths of a second. This value is set by the SOUND statement and decremented by the kernel.

CHBSNDDTN: channel B sound duration. Same as above, but for ch. B.

CHCSNDDTN: channel C sound duration. Same as above, but for ch. C.

KBDNPT: keyboard input. Temporary buffer to store the char being input through the keyboard.

KBTMP: temporary keyboard scanner. Register used by the keyboard scanner routine to store the key row of the key matrix when a key is being pressed.

TMPKEYBFR: last key pressed buffer. Temporary buffer used to store the code of the last key being pressed.

LASTKEYPRSD: code of the last key pressed. Code of the last key being pressed.

STATUSKEY: used by the key auto-repeat function. Stores the current state of the repeating (0 if no key is pressed, 1 if a key is being pressed for the first time, 2 if the key still continues to be pressed)

KEYTMR: timer used by the key auto-repeat function to activate the auto-repeat function and the delay between 2 key prints.

CONTROLKEYS: flag for control keys. Flag used by the keyboard scanner to keep track of the control keys being pressed.

SERIALS_EN: serial lines enabled. Status of the serial lines. Bit 0 reflects the status of serial line 0, while bit 1 reflects the status of serial line 1: 0 means line OFF, 1 means line ON.

SERABITS: serial port A data bits. Register used to store the data configuration bits used to set the serial port A, used by the kernel.

SERBBITS: serial port B data bits. Register used to store the data configuration bits used to set the serial port B, used by the kernel.

DOS_EN: I/O DOS enabled/disabled (1/0). When the computer’s logo is shown at boot, by pressing the SHIFT key the user can disable the I/O buffer used for DOS operations, to recover 512 bytes of free RAM.

PROGND: program end. Address of the byte after the end of the BASIC program text stored in RAM.

VAREND: variables end. Address of the byte after the last variable stored in RAM.

ARREND: arrays end. Address of the byte after the last array stored in RAM.

NXTDAT: next data item. Address of the next DATA item to be read by READ.

FNRGNM: FN argument name. Name of the argument of the current FN function. If an FN function calls another FN function, then this value is stored on the stack.

FNARG: FN function argument. Floating point value of the argument of the current FN function. If an FN function calls another FN function, then this value is stored on the stack together with its name.

FPREG: floating point register. Floating point value for the current value. These 3 bytes contains the mantissa.

FPEXP: floating point exponent. Floating point value for the current value. This byte contains the exponent. See chap. 5 for floating point representation in memory.

SGNRES: sign of the result. This register contains the sign of the result for multiplication. Both multiplicand and multiplier are tested and if their signs are different, then the product will be negative, otherwise il will be positive.

PBUFF: number print buffer. Temporary buffer used by NUMASC to store a floating point that has to be converted into ASCII for PRINT or STR$ statements

MULVAL: multiplier. This 24-bit register contains the multiplier of a multiplication because there are not enough registers to store the multipier, the multiplicand, and product at the same time.

PROGST: program start. This is the byte before the first line of a program and it MUST be zero to tell the execution driver that the next line is to be executed. See chap. 6 to see how a BASIC program is stored into RAM.

STLOOK: start of memory test. Address from which the memory test executed after a reset or when the system is powered up, start to look for the top of the RAM. This address is 100 bytes above the program text area so that the kernel can have at least some bytes to create the stack and store a very little program.

# 5. STORING DATA INTO MEMORY

## 5.1 FLOATING POINT REPRESENTATION

Floating point numbers are represented in memory using the Microsoft Binary Format (MBF), introduced by Microsoft in 1975 with its first Microsoft BASIC. It uses a 24-bit mantissa, of which 23 bits are used for the mantissa itself and 1 bit for its sign, and an 8-bit base-2 exponent, for a total of 32 bits (4 bytes). There is always a “1” bit implied to the left of the mantissa so that the exponent is encoded with a bias of 128, so that exponents from -127 to -1 are represented by values in the range $01~$7F (1~127), while exponents in the range 0~127 are represented by values in the range $80~$FF (128~255). Exponent set to zero is a special case, representing the whole number being zero.⁽¹⁾⁽²⁾

MBF representation:

m= mantissa bits

s=mantissa sign

x=exponent

Byte 1 Byte 2 Byte 3 Byte 4

smmmmmmm mmmmmmmm mmmmmmmm xxxxxxxx

Let’s try to represent the 35.25 in MBF. Firstly, the number must be converted in the binary format. To convert the integer part, we divide the number repeatedly by 2, writing the remainder to the right, until the quotient becomes 0:

Div. Quot. Rem.

35/2 = 17 1

17/2 = 8 1

8/2 = 4 0

4/2 = 2 0

2/2 = 1 0

1/2 = 0 1

Now we write the remainders from bottom to top. The results is the binary representation of the integer part of the number. So, 35 in base-2 representation is:

100011

To convert the fractional part, we multiply it repeatedly by 2 until it becomes 0, or we stop after a number of steps if the fractional part does not become zero. Each step we get the integer part as the result and the fractional part as the value for the next multiplication. Let’s see the case of 35.25. We have 0.25 to start with:

0.25 x 2 = 0.50 → 0

0.50 x 2 = 1.00 → 1 ← stop here, as the fractional part is now 0.

From top to bottom, we write the integer parts of the results to the fractional part of the base-2 number. So 0.2510 becomes 0.012. Finally, the complete number is:

35.25 → 100011.01

Just to understand this step, for a more complex case like 1.5708 we start with 0.5708:

0.5708 x 2 = 1.1416 → 1 & 0.1416

0.1416 x 2 = 0.2832 → 0 & 0.2832

0.2832 x 2 = 0.5664 → 0 & 0.5664

0.5664 x 2 = 1.1328 → 1 & 0.1328

0.1328 x 2 = 0.2656 → 0 & 0.2656

0.2656 x 2 = 0.5312 → 0 & 0.5312

0.5312 x 2 = 1.0624 → 1 ← we can stop here as we have enough digits

In this case, the results is 0.1001001, that gives a binary value of 1.10010010.

Now, let’s go back to our example, 35.25. We consider the base-2 exponent, so that the number we found in the previous step is the same as:

100011.01 * 2^00000000

The binary point has been moved to the leftmost position, so that it now precedes the first “1”.

This is the actual situation:

.10001101

Since the point has been moved to left 6 times, dividing the number by 2^6, we must add 6 to the exponent and re-multiply by 2^6:

.10001101 * 2^00000110

Since the bit to the right of the point is always 1, we can use this bit to store the sign of the number: 0 for a positive number, and 1 for a negative number. So +35.25 is stored as:

.00001101 * 2^00000110

Using 24 bits the above number is represented as follow:

.000011010000000000000000 * 2^00000110

Now, we add 128 to the exponent so that overflows and underflows can be detected easily. The number actually is stored as follow:

00001101 00000000 00000000 10000110 binary

0 D 0 0 0 0 8 6 hex

The bytes of the mantissa are stored in memory reverse order. So, this gives the following situation:

Hex. Values

Decimal Binary in memory

+35.25 00001101 00000000 00000000 10000110 00 00 0D 86

-32.25 10001101 00000000 00000000 10000110 00 00 8D 86

---M1--- ---M2--- ---M3--- ---EX--- M3 M2 M1 EX

Other examples:

Hex. Values

Decimal Binary in memory

0 00000000 00000000 00000000 00000000 00 00 00 00

1 00000000 00000000 00000000 10000001 00 00 00 81

10 00100000 00000000 00000000 10000100 00 00 20 84

PI/2 (1.5708) 01001001 00001111 11011011 10000001 DB 0F 49 81

---M1--- ---M2--- ---M3--- ---EX--- M3 M2 M1 EX

## 5.2 How variables and arrays are stored in memory

Variables such as AB, AB$, and FN AB are all stored in the variable area of memory. The start address of such area is held in ($PROGND) while the end address is held in ($VAREND).

Let make some examples. Let’s assume that AB=10, AB$=”HELLO”, and FN AB(XY) have been defined by the user. The memory would then look like this:

AB

$42 $41 Name of AB in reverse ($42 $41 = “B” “A”)

$00 $00 $20 $84 Floating point value for 10

AB$

$C2 $41 Name for AB$ in reverse ($C2 is “B” with bit 7 set)

$04 Length f string (4 chars)

?? This byte is unused fro strings

LL HH Address where “HELLO” is to be found (in Little Endian fomat)

FN AB

$42 $C1 Name of FN AB in reverse ($C1 is “A” with bit 7 set)

LL HH Address of function (the portion after “=”)

$59 $58 Argument name in reverse ($59 $58 = “Y” “X”)

Arrays such as AB(1,3) are stored in the array area. The start address of this area is held in ($VAREND) while the end address is held in ($ARREND). Arrays are stored by memorizing the size of the array itself and the number of dimensions. Apart this, numeric and string arrays are stored differently. For numeric arrays, values follow the geometry of the array, while for string arrays we find addresses of portion of memory where strings are stored. Let’s assume that DIM AB(1,3),AB$(3,1) had been encountered. Then, the numeric array looks like this in memory:

AB(1,3)

$42 $41 Name of array “AB” in reverse (see above)

$25 $00 Bytes used for array in Little Endian ($0025 = 37)

$02 2 dimensions

$04 $00 Size of 2nd dimension, including the zero element

$02 $00 Size of 1st dimension, including the zero element

$00 $00 $00 $00 value of AB(0,0)

$00 $00 $00 $00 value of AB(1,0)

$00 $00 $00 $00 value of AB(0,1)

$00 $00 $00 $00 value of AB(1,1)

$00 $00 $00 $00 value of AB(0,2)

$00 $00 $00 $00 value of AB(1,2)

$00 $00 $00 $00 value of AB(0,3)

$00 $00 $00 $00 value of AB(1,3)

This is the memory map of the string array (pointers are set to $0000 because no array cell has been initialized yet):

AB$(1,3)

$C2 $41 Name of FN AB in reverse ($C1 is “A” with bit 7 set)

$25 $00 Bytes used for array ($0025 = 37)

$02 2 dimensions

$04 $00 Size of 2nd dimension, including zero element

$02 $00 Size of 1st dimension, including zero element

$00 $00 $00 $00 pointer to contents of AB$(0,0)

$00 $00 $00 $00 pointer to contents of AB$(1,0)

$00 $00 $00 $00 pointer to contents of AB$(2,0)

$00 $00 $00 $00 pointer to contents of AB$(3,0)

$00 $00 $00 $00 pointer to contents of AB$(0,1)

$00 $00 $00 $00 pointer to contents of AB$(0,2)

$00 $00 $00 $00 pointer to contents of AB$(0,3)

$00 $00 $00 $00 pointer to contents of AB$(0,4)

## 5.3 GOSUB and RETURN usage of the stack

When a GOSUB statement is executed the BASIC interpreter push into the CPU stack the address of where to RETURN and the number of the line to RETURN as follows (from top of stack downwards):

LL HH Address of where to RETURN to

LL HH Line number to RETURN to

$8C GOSUB token as marker

This block remains into the stack until a RETURN is executed, at whichi point the BASIC looks back through the stack until it finds a GOSUB block. Then it sets the stack there, recovers the line number and the address of the statement after the GOSUB and continues the execution of the program from such point.

When a GOSUB block is stored into the stack, it deactivates all active FOR loops which were sut up inside the subroutine.

## 5.4 FOR and NEXT usage of the stack

Same behavior for a FOR statement. When it is executed, the address of the first statement of the loop, the line number of the loop statement, the TO value, the STEP value, and the sign of the STEP are stored into the stack as follows (from top of stack downwards):

LL HH Address of 1st statement in loop

LL HH Line number of loop statements

XX XX XX XX TO value in floating point (f.p.)

YY YY YY YY STEP value in f.p.

SS Signf of STEP

LL HH Address of index variable

$81 FOR token as marker

This FOR block remains into the stack until a matching NEXT is executed. When NEXT is executed, BASIC looks back through the stack to find the value of the index variable and the result is compared to the TO value. With the use of the TO value and the sign of the step, the interpreter knows if the loop has been completed or not. If it has not been completed, then the FOR block remains into the stack until the loop has been completed. The stack is set to point to this FOR block and effectively kills all FORs nested within this loop. When the completed, the FOR block is removed from the stack and the execution continues from after the NEXT instruction.

# 6. HOW A BASIC PROGRAM IS STORED IN MEMORY

A BASIC program is stored in memory following a specific scheme. The BASIC text area starts at the location $PROGST (in the actual firmware revision this corresponds to address $55E5). This location must contains $00. This is a special marker used by the interpreter to mark the beginning of the BASIC space. From the following 2 locations over, the BASIC program is stored line by line: each program line begins with a 2-byte address to the address of the next line in memory, followed by a word (2 bytes) containing the current line number, then the program line itself, and finally a zeros to mark the end of line. The text of the line is stored in a mixed format: BASIC statements are stored using their tokenized form (a particular form that uses a 1-byte code from $80 to $FF to represent each single statement) while the rest of the line is stored using ASCII codes. A couple of zeros used as pointers to the next line identify the end of the program.

An example is shown below. The following single line program:

10 FOR A=1 TO 10

it’s stored as:

ADRS TK NOTE

5346 00 Marker for beginning of BASIC space

5347 56 Pointer to...

5348 53 ...next line ($5356 in little endian format (LSB/MSB))

5349 0A Line...

534A 00 ...number ($000A = 10 in little endian format (LSB/MSB))

534B 81 Token for “FOR”

534C 20 ASCII code for “space” ($20 = 32)

534D 41 ASCII code for “A” ($41 = 65)

534E C8 Token for “=” (“=” is interpreted as a STATEMENT)

534F 31 ASCII code for “1” ($31 = 49)

5350 20 ASCII code for “space ($20 = 32)

5351 B7 Token for “TO”

5352 20 ASCII code for “space ($20 = 32)

5353 31 ASCII code for “1” ($31 = 49)

5354 30 ASCII code for “0” ($30 = 48)

5355 00 End of line

5356 00 Pointer to...

5357 00 ...next line ($0000 = end of program)

# 7. SERIAL CONFIGURATION

If you intend to connect the LM80C to a host computer through the serial port A, you have to use an FT232 module to adapt the RS232 serial lines of the LM80C to the USB port of moderm systems. Moreover, to avoid serial issues during sending data to the LM80C, please configure the terminal emulator you are using (i.e. CoolTerm or TeraTherm) with these params:

PORT: choose the port your system has mounted the FT232 module to

BAUDRATE: 19,200/38,400 bps

DATA BITS: 8

PARITY: none (0)

STOP BITS: 1

FLOW CONTROL: CTS (optional, combine with TX delay)

SOFTWARE SUPPORT FOR FLOW CONTROL: yes

RTS AT STARTUP: on

HANDLE BS AND DEL CHARS: yes

HANDLE FF (FormFeed) CHAR: yes

USE TX DELAY: min. 5ms (increment it if you experience issues)

# 8. VDP SETTINGS

The VDP, aka Video Display Processor, is the video chip of the LM80C computer. It is a TMS9918A from Texas Instruments. It can visualize a video image of 256x192 pixels with 15 colors and 32 sprites. It has several graphics modes, each of them configured to store video data in particular areas of the VRAM. These are the main settings for the modes supported by LM80C. Before to proceed, a little explanation of the meaning of different areas:

- pattern table: it's the area where the patterns that compose the chars are stored;
- name table: this is a sort of look-up table. This area maps what's is shown by the VDP in each cell of the video. The VDP reads the byte stored into a particular cell and then looks into the pattern table to find the data needed to draw the corresponding char;
- color table: some graphics modes store the color of a particular cell into this table.
- sprite pattern table: similarly to the pattern table, this area stores the data needed to draw the sprites;
- sprite attribute table: this area contains the info needed by the VDP to locate and color the sprites.

SCREEN MODE | SCREEN WIDTH | SCREEN HEIGHT | PATTERN TABLE | NAME TABLE | COLOR TABLE | SPRITE ATTRIBUTE TABLE | SPRITE PATTERN TABLE
Screen 0 | 40 cols. | 24 rows | $0000- $07FF | $0800- $0BBF | - - - - | - - - - | - - - -
Screen 1 | 32 cols. | 24 rows | $0000- $07FF | $1800- $1AFF | $2000- $201F | $1B00- $1B7F | $3800- $3FFF
Screen 2 | 256 px. | 192 px. | $0000- $17FF | $1800- $1AFF | $2000- $37FF | $1B00- $1B7F | $3800- $3FFF
Screen 3 | 64 blks. | 48 blks. | $0000- $07FF | $0800- $0AFF | - - - - | $1B00- $1B7F | $3800- $3FFF
Screen 4 | 32 cols. | 24 rows | $0000- $07FF | $1800- $1FFF | $3800- $3AFF | $1800- $1FFF | $3B00- $3B7F

N.B: the addresses above are referred to Video RAM, so you must use the VPOKE and VPEEK statements to access it.

# 9. Z80 DAISY CHAIN INTERRUPT PRIORITY

Since the LM80C is set up to work in interrupt mode 2 (IM2), the Z80 CPU serves the interrupt signals following a priority schematic that is hard-wired in the computer itself. In IM2 interrupt signals with higher priority are served before others with lower priority. In LM80C computer:

- the highest priority periphery is the Z80 SIO, since data incoming over the serial must be collected as soon as they are available;
- then the Z80 CTC, also used for the system tick counter;
- lastly, the Z80 PIO that, at the moment, it's just used as on output periphery.

# 10. STATUS LEDs

Status LEDs are used by the operating system to communicate special conditions to the users. Their meaning is as follow:

0: Bank 0 selector: 0=RAM, 1=ROM | 4: Serial 1 buffer overrun
1: VRAM bank # selector: 0=def., 1=alt. | 5: Serial 2 buffer overrun
2: N.C. | 7: Serial 1 line open
3: N.C. | 8: Serial 2 line open

Please remember that LEDs #1 and #2 drive the bank switching mechanisms to switch between ROM and RAM in bank #0 of the main memory and between the two VRAM banks for the VDP, respectively. So, consider that you could get some unwanted side effects if you change them unintentionally.

# 11. REFERENCES

1. NASCOM ROM BASIC DIS-ASSEMBLED – PART I – BY CARL LLOYD-PARKER
2. https://en.wikipedia.org/wiki/Microsoft_Binary_Format

# 12. USEFUL LINKS

Project home page:

https://www.leonardomiliani.com/en/lm80c/

Github repository for source codes and schematics:

https://github.com/leomil72/LM80C

Hackaday page:

https://hackaday.io/project/165246-lm80c-color-computer

LM80C

Color Computer

Enjoy home-brewing computers

Leonardo Miliani

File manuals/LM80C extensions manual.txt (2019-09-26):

************************************************************************
*                                                                      *
*                      N A S C O M     B A S I C                       *
*             Additional commands added to take advantage              *
*             of the features of the LM80C Color Computer              *
*           and changes made to the original Microsoft BASIC           *
*                                                                      *
************************************************************************
*                                                                      *
*                             Version  1.2                             *
*                             (2019/09/26)                             *
*              This release covers the LM80C BASIC R2.2                *                
*                                                                      *
************************************************************************

                        1. SIGNIFICANT CHANGES
                        ----------------------

1.1 Video VS Console
--------------------
The most significant difference between the original Microsoft BASIC
released for NASCOM computers is the usage of the screen instead of the
terminal or console devices. The main output device is the video:
the console output is at the moment left for compatibility reasons.
When writing a program of your own or running one such of those found
anywhere on internet, keep in mind that the LM80C computer will always
and primarily print output on the screen, so please adapt/modify the
source to take care of such behaviour.

1.2 Memory
----------
NASCOM Basic was originally released for machines that had a limited
amount of RAM, i.e. 4/8 KB. Surely, they could be expanded and several
users reached 16/24/32 KB of memory and more but this wasn't the
standard. The LM80C Color Computer actually comes with 32 KB od SRAM so
don't hesitate to use all of this room. Just keep in mind that the
original limit on the lenght of a inputted line is still fixed at 72
chars. But, apart from that, you can enter bigger programs.
------------------------------------------------------------------------

                       2. REMOVED STATEMENTS
                       ---------------------

Some statements have been removed from the interpreter due to the fact
that they laid over the original NASCOM machines. They are:
CLOAD/CSAVE: they loaded/stored data from/to an external mass storage
device
PSET: it set a video pixel on
POINT: it returned the state of a video pixel
------------------------------------------------------------------------

                3. STATEMENTS WITH DIFFERENT BEHAVIOUR
                --------------------------------------

Some statements have been changed from their original behaviour. They
are:
SCREEN: changes the video mode
RESET: resets the system
------------------------------------------------------------------------

                        4. NEW STATEMENTS
                        -----------------

There are a lot of new statements, used to take advantage of the
different (and much powerful) hardware of the LM80C.
But, firstly let's start with a big thanks to Grant Searle, from whose
BASIC comes the LM80C version, that added some useful statements (they
are marked with a "*GS*").

4.1 New number representations
------------------------------
The same number can be represented in several different bases. The
usual base is the decimal one, where every single can only be the
usual numerical digits from 0 to 9. LM80C BASIC supports other bases
for numbers:
&Hxxxx: hexadecimal base. *GS*
&Bnnnn: binary base. *GS*

4.2 New functions
-----------------
A function is a statement that gets an input paramether and returns
another data, that depends on the way it processed the input.
HEX$: returns the hexadecimal representation of a number. *GS*
BIN$: returns the binary representation of a number. *GS*
TMR: returns the value of the system timer
VPEEK: reads from VRAM
VSTAT: returns the value of status register of the VDP
SSTAT: reads the registers of the PSG

4.3 New commands
----------------
Commands are statements that tell the system to perfom a specific
operation. Commands can get some paramethers but usually don't return
any value. Here are the new commands:
VPOKE: writes into VRAM
LOCATE: position the cursor onto the screen
SOUND: plays a sound tone
VOLUME: sets the volume of the PSG audio channels
PAUSE: pauses the execution of the code for a certain bit of time
------------------------------------------------------------------------

                        5. LANGUAGE REFERENCE
                        ---------------------

&B
--
Format: &Bnnnn

Binary base. It interprets the "nnnn" value as a binary value (signed
int). "n" can be made only by "0" or "1" numbers.
- - - - - - - - - - - - - - - - - - - - - - - - - - - - - - - - - - - -

&H
--
Format: &Hxxxx

Hexadecimal base. It interprets the "xxxx" value as an hexadecimal value
(signed int). Each "x" can be any number between 0 and 9 and any char
between A (10) and F (15).
- - - - - - - - - - - - - - - - - - - - - - - - - - - - - - - - - - - -

ABS
------
Format: ABS(X)

Returns the absolute value (i.e. with no sign) of the expression "X".
Example:
ABS(12.4) => 12.4

ABS(-75) => 75
- - - - - - - - - - - - - - - - - - - - - - - - - - - - - - - - - - - -

AND
---
Format: A AND B

Logic operator used in boolean expressions. AND performs a logical
conjuntion. The interpreter supports 3 boolean operators: AND, OR, and
NOT, each of them work with 16-bit signed integers. They convert their
inputs in 16-bit integers and return a value in such format.
The result of an AND operation follows the truth table below (T=true,
F=false):
F AND F = F
F AND T = F
T AND F = F
T AND T = T
This means that the result is true only if both expressions A & B are
true.
Example:
1 AND 1 => 1
0 AND 1 => 0

A=0, B=1
A AND B = 0
- - - - - - - - - - - - - - - - - - - - - - - - - - - - - - - - - - - -

ASC
---
Format: ASC(X$)

Returns the ASCII code of the first character of the string "X".
Example:
ASC("A") => 65
ASC("AB") => 65
- - - - - - - - - - - - - - - - - - - - - - - - - - - - - - - - - - - -

ATN
---
Format: ATN(X)

Returns the arctangent of "X". The result is in RADIUS in range
-pi/2 to pi/2
- - - - - - - - - - - - - - - - - - - - - - - - - - - - - - - - - - - -

BIN$
----
Format: BIN$(X)
Converts an expression into a string containing the binary value.
Example:
BIN$(12) => "1010"
- - - - - - - - - - - - - - - - - - - - - - - - - - - - - - - - - - - -

CHR$
----
Format: CHR$(X)

Returns a string containing the character whose ASCII code is
represented by expression X.
Example:
CHR$(65) => "A"
- - - - - - - - - - - - - - - - - - - - - - - - - - - - - - - - - - - -

CLEAR
-----
Format: CLEAR
        CLEAR X

The call of CLEAR with no paramethers set the contents of all the
variables stored in memory to 0.
If called with a numeric expression, it sets the string space to the
value of expression X. At startup, the string space is set to 100 by
default. See the string chapter for more info.
Example:
CLEAR => clears every variable
CLEAR 200 => sets the string space to 200 chars
- - - - - - - - - - - - - - - - - - - - - - - - - - - - - - - - - - - -

CLS
---
Format: CLS

Clears the current screen, intializes the pattern cells. The filling
value is graphic mode dependant: in modes 0 & 1 the video buffer is
filled up with ASCII value 32 (the "space" character) while in modes
2 & 3 is filled up with 0s. Finally, moves the cursor at coordinates 0,0
(the top left corner).
- - - - - - - - - - - - - - - - - - - - - - - - - - - - - - - - - - - -

CONT
----
Format: CONT

Given after an error that halted the execution of a program, forces
the interpreter to continue with the line after the one that raised
the error.
- - - - - - - - - - - - - - - - - - - - - - - - - - - - - - - - - - - -

COS
---
Format: COS(X)

Returns the cosine of "X". The result is in RADIUS in range
-pi/2 to pi/2
- - - - - - - - - - - - - - - - - - - - - - - - - - - - - - - - - - - -

DATA
----
Format: DATA <list>

Introduces a list of informations used by the program itself. "list"
can be a list of numerical or strings separated by commas and read with
the READ statement. See also RESTORE.
Example:
10 DATA 20,30,40  => numericals
20 DATA "HELLO",LM80C => strings
- - - - - - - - - - - - - - - - - - - - - - - - - - - - - - - - - - - -

DEEK
----
Format: DEEK(X)

Reads a word from memory cells given by the expression X and X+1. A word
is a 16-bit value stored in 2 contiguos memory cells: X contains the
low byte while X+1 contains the high byte. 
Example:
A=DEEK(1000) => reads the word at 1000/1000+1 and stores it into A
- - - - - - - - - - - - - - - - - - - - - - - - - - - - - - - - - - - -

DEF
---
Format: DEF FNXXX(Y)=<expression>

Creates an user-defined function that expands the built-in functions of
the interpreter. XXX is the name of the new function and must follow
the FN statement and must be a valid variable name; Y is the paramether
passed, and it must be a valid variable name too; "expression" is the
newly defined function. Limits: everything must reside in 72 chars (the
lenght of a standard line); only one paramether is allowed. To call the
function just use the FNXXX name.
Example:
DEF FNRAD(DEG)=3.14159/180*DEG
FNRAD(100) => 1.74532
- - - - - - - - - - - - - - - - - - - - - - - - - - - - - - - - - - - -

DIM
---
Format DIM <V>(<I>,[J])[,....]

Allocates space for array variables. More than one array can be
dimensioned with one DIM statement. Array can have one ore two
dimensions. If an array is used without being dimensioned, it is
assumed to have a maimum subscript of 10 (i.e., eleven elements from 0
to 10). So, for example A(I,J) is assumed to have 121 elements, unless
otherwise dimensioned.
Example:
DIM A(10) => monodimensional array, elements numbered from 0 to 10
DIM B(5,5) => bidimensional array, indexes fro 0 to 5 (36 elements).
- - - - - - - - - - - - - - - - - - - - - - - - - - - - - - - - - - - -

DOKE
----
Format: DOKE X,Y

Writes a word value (a 16-bit number) into a couple of contiguos memory
cells. X and Y must be valid numericals, in any supported format. The
low byte of Y will be written into location X while the high byte of Y
will be written into location X+1.
Example:
DOKE &H8100,&HAABB => cell $8100 will contain $00, cell $8101 will
contain $81
- - - - - - - - - - - - - - - - - - - - - - - - - - - - - - - - - - - -

END
---
Format: END

Terminates the execution of a program. Any statements and/or program
lines after END will be ignored and control will return to the editor.
- - - - - - - - - - - - - - - - - - - - - - - - - - - - - - - - - - - -

EXP
---
Format: EXP(X)

Returns e to the power X. X must be lesser or equal to 87.3365.
Example:
EXP(2) => 7.38905
- - - - - - - - - - - - - - - - - - - - - - - - - - - - - - - - - - - -

FN
--

See "DEF"
- - - - - - - - - - - - - - - - - - - - - - - - - - - - - - - - - - - -

FOR
---
Format: FOR <var> = <X> TO <Y> [STEP <Z>] /instructions/ NEXT <X>[,...]

The FOR..NEXT statements are used to create loops, i.e. a sequence of
instructions that have to be repeated for a certain number of times.
<var> is a valid name of a variable that will contain the value
incremented during the loop and used for the ending test. X, Y, and Z
are expression. X is the starting value and it is assigned to <var> at
the beginning of the loop. Then, the instructions between FOR and NEXT
statements are executed. When the NEXT is reached, if X is lesser
than Y, the value of Z if present, is added to <var> and tested against
Y: if <var> is greater then Y the loop is terminated and the execution
continues from the first instruction after the NEXT statement; otherwise
the loop is repeated.
If Z is not present, the increment is assumed to be 1. If Z is negative,
the loop decrements the value of <var> from X to Y.
FOR..NEXT loops can be nested: the only limit is the amount of memory.

One or more loop variables can follow the NEXT statement, altough the
first variable must refer to the recent loop, the second of the most
recent one and so on. If no variable is present, the NEXT statement 
refers to the most recent FOR statement.
Example:
FOR I=1 to 10:PRINT I:NEXT I => repeats the loop 10 times (from 1 to 10)

FOR I=1 to 10
FOR J=1 TO 20
PRINT A(I,J)
NEXT J,I => repeat 2 loops, J is the first because is the most recent
- - - - - - - - - - - - - - - - - - - - - - - - - - - - - - - - - - - -

FRE
---
Format: FRE(X)

If X is a numerical expression, FRE returns the memory available for
BASIC environments. If the expression is a string, it returns the
available space in the string space. See CLEAR for more details. 
Example:
FRE(0) => returns the memory available for BASIC (programs and vars)
FRE("") => returns the free space in the string space
- - - - - - - - - - - - - - - - - - - - - - - - - - - - - - - - - - - -

GOSUB
-----
Format: GOSUB <line>

Jumps at <line> to execute a portion of code. When the interpreter
will encounter the RETURN statement, it will resume the execution at
the instruction following the GOSUB statement. See also RETURN.
Example:
10 GOSUB 30 => jumps to 30
20 END => resumes from here
30 PRINT "HELLO" 
40 RETURN => return to caller
- - - - - - - - - - - - - - - - - - - - - - - - - - - - - - - - - - - -

GOTO
----
Format: GOTO <line>

Makes an unconditional jump to another point of the program indicated
by <line>. 

10 GOTO 100
- - - - - - - - - - - - - - - - - - - - - - - - - - - - - - - - - - - -

HEX$
----
Format: HEX$(X)

Converts the numerical expression X into a string containing the
hexadecimal representation of the value of X. X must be a signed integer
with value in range -32,768/+32,767.
Example:
HEX$(1000) => "3E8"
- - - - - - - - - - - - - - - - - - - - - - - - - - - - - - - - - - - -

IF
--
Format: IF X THEN [...]
        IF X GOTO <line>

IF is a conditional branch. It serves to change the order of the
execution of the instructions of a programs instead of the ordinary
sequential flow. X can be any valid arithmetic, relational, or logical
expression: if it is evaulated true (i.e. non-zero), the statements
after IF are executed. There are some formats of the statement.
If the expression is true, anything that follows THEN will be executed:
10 IF A=1 THEN PRINT "A IS EQUAL TO 1":GOTO 100

If there is only a GOTO instruction after the expressio to be evaluated,
the THEN statement can be omitted:
10 IF A=1 GOTO 100
- - - - - - - - - - - - - - - - - - - - - - - - - - - - - - - - - - - -

INP
---
Format: INP(X)

Reads a byte (an 8-bit value) from the I/O port specified by the
expression X. X must be in range 0-255.
Example:
A=INP(1) => read a byte from port 1 and assign it to A
- - - - - - - - - - - - - - - - - - - - - - - - - - - - - - - - - - - -

INPUT
-----
Format: INPUT [<prompt text>;]<list of variables>

Reads one or more data from the standard input and assign it to the
same number of variables. The interpreter prompts the user with a 
question mark, then he/she must insert some data and press the ENTER
key. If more than one data is requested, each one must be separated
by a comma, and the user must be enter the exact amount of values with
the correct type, separated by commas. If the data is invalid, i.e. a
string when a number was expected, the interpreter will print a "REDO
FROM START?" error and the user will be asked to re-enter the data; if
more data was requested than entered, a "??" will be printed and the
interpreter will ask for the missing ones; if more data was entered
than requested, an "EXTRA IGNORED" advice will be printed and the
execution will continue discarding the extra values. If a prompt text
is passed, it will be printed on screen before the question mark. The
prompt text must be enclosed in double quotation marks and followed by a
semicolon. 
Example:
INPUT "WHAT'S YOUR NAME";NAME$ => waits for a string
INPUT "NAME,AGE";NAME$,AGE => waits for 2 data (a string and a number)
INPUT A => wait for a number with just a "?"
- - - - - - - - - - - - - - - - - - - - - - - - - - - - - - - - - - - -

INT
---
Format: INT(X)

Returns the integer part of X. X must be a numerical expression. The
result is obtainded by truncating X to the decimal point. If X is
negative, the round is made to the first integer greater than X.
Example:
INT(3.14) => 3
INT(-3.14) => -4
- - - - - - - - - - - - - - - - - - - - - - - - - - - - - - - - - - - -

LEFT$
-----
Format: LEFT$(X,I)

Returns a string that contains the I characters to the left of the
string X. See also RIGHT$ and MID$
Example:
LEFT$("HELLO",2) => "HE"
- - - - - - - - - - - - - - - - - - - - - - - - - - - - - - - - - - - -

LEN
---
Format: LEN(X)

Returns the lenght of the string X.
Example:
LEN("HELLO") => 5
- - - - - - - - - - - - - - - - - - - - - - - - - - - - - - - - - - - -

LET
---
Format: LET <var>=<val>

Assigns the value <val> to the variable with name <var>. The use of LET
is optional and this statement can be omitted.
Example:
LET A=10   is equal to     A=10
- - - - - - - - - - - - - - - - - - - - - - - - - - - - - - - - - - - -

LINES
-----
Format: LINES <num>

Sets the number of lines to print before to pause the listing of a
program made with LIST. See below.
- - - - - - - - - - - - - - - - - - - - - - - - - - - - - - - - - - - -

LIST
----
Format: LIST [start]

Lists a program stored in memory. If <start> is passed, the list will
start at the line set by <start>, otherwise from the first line of the
program. LIST will print the number of lines set with LINES (see above)
then will pausing, waiting for the pressing of a key.
Example:
LIST  => list the whole program
LIST 100  => list from 100 to the end of the program
- - - - - - - - - - - - - - - - - - - - - - - - - - - - - - - - - - - -

LOCATE
------
Format: LOCATE X,Y

Places the cursor on the screen at coordinates X,Y. LOCATE works only
in graphic modes 0 & 1. Y is in range 0~23 while X is in range 0~31/39,
depending on which mode is active at the moment: graphic 1 is 32 chars
wide while graphic 1 is 40 chars wide. Coordinates 0,0 point to the top
left corner. The usage of this command makes no sense in screen modes
2 & 3 since they don't have any cursor support.
Example:
LOCATE 0,0 => place the cursor in the top left corner
LOCATE 0,9 => place the cursor at the first cell of the 10th row
- - - - - - - - - - - - - - - - - - - - - - - - - - - - - - - - - - - -

LOG
---
Format: LOG(X)

Returns the natural logarithm of X. X must be greater than 0.
Example:
LOG(10) => 2.30259
- - - - - - - - - - - - - - - - - - - - - - - - - - - - - - - - - - - -

MID$
----
Format: MIDS$(X,I[,J])

Returns a portion of string X. If J is omitted, it returns the I right-
most characters of X; if J is passed, it returns the chars between the
Ith and the Jth.
Example:
MID$("HELLO",3) => "LLO"
MID$("HELLO",3,2 = > "LL"
- - - - - - - - - - - - - - - - - - - - - - - - - - - - - - - - - - - -

MONITOR
-------
Format: MONITOR

Used to activate the terminal of the Nascom computers, at the moment
it resets the system. It will be removed in future releases.
- - - - - - - - - - - - - - - - - - - - - - - - - - - - - - - - - - - -

NEW
---
Format: NEW

Deletes the current program in memory and clears every variable. Used
before to enter a new program without the need to reset the system.
Example:
NEW
- - - - - - - - - - - - - - - - - - - - - - - - - - - - - - - - - - - -

NEXT
----
Format: NEXT <list of variables>

Used in FOR loops. See FOR for details.
- - - - - - - - - - - - - - - - - - - - - - - - - - - - - - - - - - - -

NOT
---
Format: NOT X

Returns the bit complement of X. The truth table is below:
NOT 1 => 0
NOT 0 => 1
Since the interpreter works with 16-bit signed numbers, one could think
that it works in a strange manner:
NOT 1 => -2
NOT 0 => -1
Indeed, the results are OK. NOT 0 should return 1 but, since the two's
complement of sixteen zeros is sixteen ones, which is the two's
complement representation of -1. Similarly, NOT 1 should be 0 but since
the 16-bit value of 1 is the binary 0000000000000001, the bit complement
of it is 1111111111111110 that is the two's complement of -2.
Eventually, NOT X is equal to -(X+1).
See also AND for details.
- - - - - - - - - - - - - - - - - - - - - - - - - - - - - - - - - - - -

NULL
----
Format: NULL X

Sets the null characters to be printed at the end of a printed row.
The default value is 0. X must be a numeric expression.
NULL had a meaning when teletypes were used to print text but it is
obsolet at the moment and will be removed in future releases.
- - - - - - - - - - - - - - - - - - - - - - - - - - - - - - - - - - - -

ON
--
Format: ON X GOTO <list of lines>
        ON X GOSUB <list of lines>

Used in conjunction with GOTO and GOSUB to introduce a series of
unconditional jumps (GOTO) or calls to subroutines (GOSUB). X must be
a numerical expression: the jump is executed by calling the line whose
position corresponds to the value of X. The lines must be separated by
columns.
Example:
ON A GOTO 100,200,300
ON B GOSUB 1000,2000,3000
- - - - - - - - - - - - - - - - - - - - - - - - - - - - - - - - - - - -

OR
--
Format: X OR Y

Boolean operator used for logical disjunction operations. It returns a
true value when one or both the expressions are true.  Its truth
table is the following:
0 OR 0 = 0
0 OR 1 = 1
1 OR 0 = 1
1 OR 1 = 1
See also AND and NOT.
Example:
4 OR 2 => 6 (4 is 100b, 2 is 10b, so 100b or 010b is equal to 110b, 
that is 6 in decimal representation)
- - - - - - - - - - - - - - - - - - - - - - - - - - - - - - - - - - - -

OUT
---
Format: OUT X,Y

Sends Y to the peripherical device connected to output port X. X and Y
must be expressions with values in range 0~255.
Example:
OUT 1,100
- - - - - - - - - - - - - - - - - - - - - - - - - - - - - - - - - - - -

PAUSE
-----
Format: PAUSE X

Forces the system to halt and wait for a specific interval of time set
by X. X must be a numerical expression in range 0~65,535 that represents
the number of 100ths of a second to wait.
Example:
PAUSE 1000 => wait for 10 seconds (1,000 x 0.01s)
PAUSE 0 => no wait. this is similar to the assembly instruction NOP
- - - - - - - - - - - - - - - - - - - - - - - - - - - - - - - - - - - -

PEEK
----
Format: PEEK(X)

Returns the byte stored in RAM at location X. X must be a numerical
expression in range -32,768 to 32,767 (i.e. a 16-bit signed integer).
Example:
PRINT PEEK(8000) => prints the contents of address 8000.
- - - - - - - - - - - - - - - - - - - - - - - - - - - - - - - - - - - -

POKE
----
Format: POKE X,Y
Writes the byte Y into the location of RAM whose address is X. X must be
a numerical expression in range -32,768 to 32,767 (i.e. a 16-bit signed
integer), Y an expression whose value is in range 0~255.
Example:
POKE -28672,128 => writes 128 into memory cell located at 36,864 (just
remember that numbers are 16-bit signed so everything greater than 
32,767 must be provided in two's complement)
- - - - - - - - - - - - - - - - - - - - - - - - - - - - - - - - - - - -

POS
---
Format: POS(X)

Returns the current position of the terminal's printer head. Note:
obsolete, it will be removed in future releases.
- - - - - - - - - - - - - - - - - - - - - - - - - - - - - - - - - - - -

PRINT
-----
Format: PRINT [data|variables|text|operations]

The PRINT statement prints something on screen. It supports different
types of expressions: it can print the contents of variables, text
included between double quotation marks, the results of numerical
expressions, numerical literals. The interpreters considers the printing
line divided in zones of 14 spaces each: if expressions are separated by
commas the interpreter prints each expression at the beginning of such
spaces. If a semicolon is used (;) the expressions are printed one after
another. If neither of them are present, then the interpreter will
go to the next line after the ending of the print statement.
Example:
PRINT => just go to next line
PRINT "HELLO" => prints HELLO and then a carriage return is inserted
PRINT A => prints the value of variable A
PRINT "LENGHT:";LN;" METERS" => prints LENGHT followed by the contents
                                of LN and then by METERS
PRINT A,B => prints the contents of A and B with tabulation
- - - - - - - - - - - - - - - - - - - - - - - - - - - - - - - - - - - -

READ
----
Format: READ <list of variables>

Reads the informations stored into the program with DATA statement.
<list of variables> is a set of variables names separated by commas. The
The effect of READ statement is to read the value introduced by DATA and
store it into the variables following READ, from left to right. If the
informations to be read are less than the variables names an error will
be raised. If there are more values stored in DATA than are read from
a READ, the next READ will continue to read from the next unread data.
Types of variables and informations must be coherents (i.e. a string
can not be assigned to a numerical variable). See also RESTORE.
Example:
10 DATA 10,20,"HELLO"
20 READ A,B,C$ => 10 will be written into A, 20 into B, and "HELLO" in C
- - - - - - - - - - - - - - - - - - - - - - - - - - - - - - - - - - - -

REM
---
Format: REM <comment>

Used to enter a comment into the program. Everything that follow the REM
statement will be ignored.
Example:
10 X=10:REM SETS HERE THE STARTING VALUE
- - - - - - - - - - - - - - - - - - - - - - - - - - - - - - - - - - - -

RESET
-----
Format: RESET

Originally used to reset (set to off) a video pixel, now (without any
additional paramether) performs a system reset.
- - - - - - - - - - - - - - - - - - - - - - - - - - - - - - - - - - - -

RESTORE
-------
Format: RESTORE

After a RESTORE statement the next information read with a READ state-
ment will be the first value of the first DATA into the program. See
also DATA and READ.
Example:
10 DATA 10,20,30
20 READ A => A will contain 10
30 RESTORE: READ B => B will also contain 10
- - - - - - - - - - - - - - - - - - - - - - - - - - - - - - - - - - - -

RETURN
------
Format: RETURN

Used to leave a sub-routine called by GOSUB. After the RETURN statement,
the execution of the program will continue with the instruction
following the GOSUB statement.
Example:
10 GOSUB 100
20 PRINT "FINISH":END
100 PRINT "START"
110 RETURN  => the execution will continue from line 20
- - - - - - - - - - - - - - - - - - - - - - - - - - - - - - - - - - - -

RIGHT$
------
Format: RIGHT$(X,I)

Returns a string that contains the I characters to the right of the
string X. See also LEFT$ and MID$
Example:
RIGHT$("HELLO",2) => "LO"
- - - - - - - - - - - - - - - - - - - - - - - - - - - - - - - - - - - -

RND
---
Format: RND(I)

Returns a random number between 0 and 1. A negative value of I will
start a new sequence; if I is greater than zero the function will return
the next value in the random sequence; a vaue of zero will return the
last number returned. The same negative number will generate the same
random sequence. 
Example:
A=RND(1) => returns a random number
A=INT(RND(1)*6)+1 => rolls a dice: will return a number between 1 and 6.
- - - - - - - - - - - - - - - - - - - - - - - - - - - - - - - - - - - -

RUN
---
Format: RUN [numline]

Start the execution of the program currently stored in memory. If
[numline] is passed, the execution will start from such line, otherwise
it will start from the first line.
Example:
RUN
- - - - - - - - - - - - - - - - - - - - - - - - - - - - - - - - - - - -

SCREEN
------
Format: SCREEN mode

Originally, it positioned the cursor at a specific location into the
terminal screen. Now it changes the screen mode. "mode" is a number
between 0 and 3 and sets the screen as follow:
0: 40x24 chars text mode (no sprites support)
1: 32x24 chars text mode or 256x192 pixels graphic mode (sprites supp.)
2: 256x192 pixels graphic mode (sprites supported, bitmap mode)
3: 64x48 pixels multicolor graphic mode (sprites supported)

SCREEN initializes the screen with default settings. In modes 0 & 1 it
also loads and configures a charset since these two are also text modes:
the big difference is that mode 0 is a real text mode, with no support
for sprites and graphics. In every mode, SCREEN also performs a screen
clear.
- - - - - - - - - - - - - - - - - - - - - - - - - - - - - - - - - - - -

SGN
---
Format: SGN(X)

Returns the sign of X: it returns -1 if X is negative, 1 if it is 
positive, or 0 if it is zero.
Example:
10 ON SGN(X)+2 GOSUB 100,200,300 => calls 100 for X<0, 200 for X=0, and
                                    300 for X>0
- - - - - - - - - - - - - - - - - - - - - - - - - - - - - - - - - - - -

SIN
---
Format: SIN(X)

Returns the sine of "X". The result is in RADIUS in range -pi/2 to pi/2.
- - - - - - - - - - - - - - - - - - - - - - - - - - - - - - - - - - - -

SOUND
-----
Format: SOUND ch,tone,dur

This command instructs the PSG to emit a sound with a particular tone
for a specific duration on the selected channel. "ch" can be 1,2, or 3,
and corresponds to the same analog channel of the PSG."tone" can vary
between 0 and 4,095 and it is inversely related to the real frequency of
the emitted tone. The formula to get the frequency is below:

Freq = 1,843,200 / 16 / (4,096 - tone)
(where 1,843,200 Hz is the clock of the PSG while "16" is a fixed
internal prescaler)

I.e.: if tone is equal to 4,000, the frequency of the sound generated
by the PSG will be 1,200 Hz. In fact, 1,843,200 / 16 / 96 = 1,200.
The lower frequency will be 28 Hz while the higher frequency will be
115,200 Hz (115 KHz). Obviously, anything over 15/20 KHz won’t be
audible. "dur" is the duration in 100ths of a second and its range is
between 0 and 16,383 (0.0~163.8 seconds). By setting a tone of "tone" 0
we force the audio to quit immediately. By setting a tone with duration
equals to 0, the tone will last forever, unless you quit the volume off
or you set another tone on the same channel.
Example:
SOUND 1,3500,100 => plays a tone of freq. 193 Hz for 1 second.
- - - - - - - - - - - - - - - - - - - - - - - - - - - - - - - - - - - -

SPC
---
Format: SPC(X)

Prints X spaces on video.
- - - - - - - - - - - - - - - - - - - - - - - - - - - - - - - - - - - -
 
SQR
---
Format: SQR(X)

Returns the square root of X X must be greater than zero.
Example:
SQR(9)  => 3
- - - - - - - - - - - - - - - - - - - - - - - - - - - - - - - - - - - -

SREG
----
Format: SREG X,Y

Writes the byte Y into the register X of the PSG. X must be in the range
0-15 while Y in the range 0-255. See SSTA for considerations about the
register numbering.
Example:
SREG 8,15 => set the volume of analog channel 0 to 15
- - - - - - - - - - - - - - - - - - - - - - - - - - - - - - - - - - - -

SSTAT
-----
Format: SSTAT(X)

Reads the PSG (Programmable Sound Generator) register set by X and
returns a byte. X must be in the range 0-15. Some words must be spent
about the register numbering. The PSG datasheet reports that registers
are divided into 2 sets of 8 elements each, numbered from 0 to 7 and
from 10 to 17, resepectively. Despite this, the chip is connected in a
way so that the registers appear consecutive, so the 9th register is
addressed as register 8 instead of 10.
Example:
SSTAT(8) => actually reading the register #10.
- - - - - - - - - - - - - - - - - - - - - - - - - - - - - - - - - - - -

STEP
----
Format: STEP <val>

Used in FOR..NEXT loops to set the increment of the index variable. See
FOR for more details.
- - - - - - - - - - - - - - - - - - - - - - - - - - - - - - - - - - - -

STOP
----
Format: STOP

Halts the execution of a program. See CONT on how to resume running.
- - - - - - - - - - - - - - - - - - - - - - - - - - - - - - - - - - - -

STR$
----
Format: STR$(X)

Converts the string representation of expression X.
Example:
STR$(12) => "12"
- - - - - - - - - - - - - - - - - - - - - - - - - - - - - - - - - - - -

TAB
---
Format: TAB(X)

Spaces the cursor to column X on the terminal. 0 is the leftmost space
while 71 is the rightmost space. X must be in the range 0~255.
- - - - - - - - - - - - - - - - - - - - - - - - - - - - - - - - - - - -

TAN
---
Format: TAN(X)

Returns the tangent of X. The result is in radians.
Example:
TAN(1) => 0.0003
- - - - - - - - - - - - - - - - - - - - - - - - - - - - - - - - - - - -

THEN
----
Format: THEN

Used with IF statement. See IF for more details.
- - - - - - - - - - - - - - - - - - - - - - - - - - - - - - - - - - - -

TMR
---
Format: TMR(X)

Returns the value of the system tick timer. The system timer is a 32-bit
counter that is incremented every hundredth of a second. Since the
BASIC interpreter that only manage 16-bit values, the system timer can
be read by considering it divided into 2 halves: if X is 0 than the
function will return the first two less significant bytes of the
counter. If X is 1, than the two most significant bytes will
be returned instead. The system counter can be used to measure the
passing of time: if you divide by 100 the value returned by TMR(0) you
get the number of seconds since the computer has been powered on.
Example:
TMR(0) => 3456
- - - - - - - - - - - - - - - - - - - - - - - - - - - - - - - - - - - -

TO
--
Format: TO

Used in FOR..NEXT loops to set the range of the index variable. See FOR
for more informations.
- - - - - - - - - - - - - - - - - - - - - - - - - - - - - - - - - - - -

USR
---
Format: USR(X)

Calls an user-defined machine language subroutine with argument X.
The call of the subroutine is made through an entry point in RAM that
must be initialized with the address of the first cell where the
user code is stored in RAM. The entry point is located at locations 
$8049 and 804A: the address must be set using the little-endian order,
meaning that the first byte must be filled up with the less significant
byte while the second one by the most significant byte. Suppose that
a subroutine has been stored in RAM from address $B0A0. Then the byte
$A0 will be stored at $8049 while byte $B0 will be stored at $804A.
Example:
A=USR(0) => call a subrouting with argument 0.
- - - - - - - - - - - - - - - - - - - - - - - - - - - - - - - - - - - -

VAL
---
Format: VAL(X$)

Returns the numerical value of string X$. If the first character of X$
isn't a +,&, or a digit then the result will be 0.
Example:
VAL("12") => 12
A$="a":VAL(A$) => 0, because A$ can not be represented as a number
- - - - - - - - - - - - - - - - - - - - - - - - - - - - - - - - - - - -

VOLUME
------
Format: VOLUME X,Y

Sets the volume of the selected channel X to volue Y. X must be in the
range 0~3: 1,2, and 3 works on the corresponding analog channel,
resepectively. If X is 0, the statement will apply to all the channels.
Y must be a numerical value between 0 (no audio) and 15 (max volume).
Example:
VOLUME 0,0 => quits the volume of all the channels.
- - - - - - - - - - - - - - - - - - - - - - - - - - - - - - - - - - - -

VPEEK
-----
Format: VPEEK(X)

Reads a value from the VRAM (or Video-RAM), the memory that is at
exclusive use of the VDP (Video Dislay Processor). X is a value between
0 ($0000) and 16,383 ($3FFF), since the VRAM is 16 KB wide. It returns
a byte value (0-255).
Example:
VPEEK(0)
- - - - - - - - - - - - - - - - - - - - - - - - - - - - - - - - - - - -

VPOKE
-----
Format: VPOKE X,Y

Like its RAM counterpart, VPOKE writes Y into the cell of VRAM whose
address is X. X must be in the range 0~16,383, while Y is a byte value
(0-255).
Example:
VPOKE 1000,100
- - - - - - - - - - - - - - - - - - - - - - - - - - - - - - - - - - - -

VREG
----
Format: VREG X,Y

Writes Y into the VDP register X. X must be a number in the range 0~7,
while Y is a byte.
Example:
VREG 7,15 = writes 15 into register #7
- - - - - - - - - - - - - - - - - - - - - - - - - - - - - - - - - - - -

VSTAT
-----
Format: VSTAT(X)

Reads the status register of the VDP. X is ignored and it can be any
signed integer (between -32,768 and +32,767). It returns a byte value
(0-255).
Example:
VSTAT(0)
- - - - - - - - - - - - - - - - - - - - - - - - - - - - - - - - - - - -

WAIT
----
Format: WAIT X,Y[,Z]

Reads the I/O port X and performs and OR between the read byte and Y.
If Z is passed, the result of the OR operation is ANDed with Z. The
excution continues with a non-zero result.
Example:
WAIT 0,0,128 => the execution continues only if port 0 returns 128
                because 128 OR 0 = 128 and 128 AND 128 = 128.
- - - - - - - - - - - - - - - - - - - - - - - - - - - - - - - - - - - -

WIDTH
-----
Format: WIDTH X

Sets the lenght of a lines for inputs or outputs. X must be in the range
0~255. Default is 255. 
------------------------------------------------------------------------

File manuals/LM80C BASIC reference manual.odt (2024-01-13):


L M 8 0 C B A S I C

Language Reference Manual

LM80C BASIC

LM80C 64K BASIC

BASIC interpreter derived by NASCOM BASIC

(based on Microsoft BASIC 4.7)

with additional statements to take advantage

of the features of the LM80C Color Computer

and LM80C 64K Color Computers

This release covers the

LM80C BASIC 3.26 (18/04/2021)

and

LM80C DOS 1.07 (12/01/2024)

Latest revision on 13/01/2024

### Copyright notices:

Microsoft BASIC is © 1978 Microsoft Corp.

NASCOM BASIC and the trademark NASCOM are © Lucas Logic, Ltd.

Modifications and additions made for LM80C Color Computer by Leonardo Miliani

The names “LM80C”, “LM80C Color Computer”, “LM80C BASIC”, and “LM80C DOS”, the “rainbow LM80C” logo, the LM80C schematics, the LM80C sources, and this work belong to Leonardo Miliani, from here on the “owner”.

The “rainbow LM80C” logo and the “LM80C/LM80C Color Computer/LM80C 64K/LM80C 64K Color Computer” names can not be used in any work without explicit permission of the owner. You are allowed to use the “LM80C” name only in reference to or to describe the LM80C Color Computer.

The LM80C and LM80C 64K schematics and source codes are released under the GNU GPL License 3.0 and in the form of "as is", without any kind of warranty: you can use them at your own risk. You are free to use them for any non-commercial use: you are only asked to maintain the copyright notices, to include this advice and the note to the attribution of the original works to Leonardo Miliani, if you intend to re-distribute them. For any other use, please contact the owner.

# 1. OVERVIEW

## 1.1 Preface

This manual is the language reference for the LM80C BASIC, a BASIC dialect built into the LM80C Color Computer and LM80C 64K Color Computer (from now on, only LM80C) a couple of home-brew computers designed by Leonardo Miliani. This manual is not intended as a BASIC guide to learn the language: we assume that the reader has already a... basic (sorry for the pun..) knowledge of his/her own of the language so that he/she may be able to read and understand what’s discussed here. This book is just a reference manual to the LM80C BASIC, useful to learn how to use the peculiar statements of the LM80C.

A note on the decimal separator. In this manual we decided to adopt the pratice to use the decimal metric system, so in the text the period is used in digit grouping to group the thousands, while the comma is used to separate the decimals. However, in the code examples the period is used as a decimal separator, because this is the syntax of the BASIC language. So, 1.000 means “one thousand” and 1,000 means “one followed by 3 decimal digits”.

## 1.2 Video VS terminal

The LM80C BASIC derives from the NASCOM BASIC, derived, in turn, from the Microsoft Z80 BASIC: the NASCOM BASIC was developed for the NASCOM terminals. The most significant difference between the original Microsoft Z80 BASIC released for NASCOM computers and the LM80C BASIC is the usage of the screen instead of the terminal or console devices as main output. Everything you digit on the keyboard or it’s printed out by the computer is echoed on the screen: you can open a serial line to communicate with a host computer but the primary device will always be the video screen. When writing a program of your own or running one such of those found anywhere on internet, keep in mind that the LM80C Color Computers basically is like a home-computer of the 8-bit era, so it will always and primarily get input from keyboard and print output on the screen: please adapt/modify the source you are inserting to take care of such behavior.

## 1.3 Memory

NASCOM Basic was originally released for machines that had a limited amount of RAM, commonly 4/8 KB. Surely, they could be expanded and several users did it, reaching 16/24/32 KB of memory and more, but this wasn't the standard. The LM80C 64K actually comes with 64 KB of SRAM, so don't hesitate to use all of this room. Just keep in mind that the original limit on the length of an input line has been changed from 72 to 88 chars, so this facilitates the input of big programs.

## 1.4 System overview

The LM80C 64K is a powerful computer made around the Z80 CPU from Zilog. It runs at 3.68 MHz and it is able to generate a video image of 256×192 pixels at 15 colors with 3 audio channels and serial&parallel I/O. Here are the main technical characteristics:

- CPU: Zilog Z80B at 3.68 MHz
- 64 KB of SRAM
- 32 KB of EEPROM with:
  - firmware to drive video/audio/serial/parallel peripheral chips
  - integrated LM80C BASIC interpreter
  - LM80C DOS to access an external disk (Compact Flash)
- Video: TMS9918A at 10.7 MHz
  - dedicated 16/32 KB of VRAM
  - screen resolution: 256×192 pixel
  - 15 colors + transparent
  - 32 monochrome sprites from 8×8 to 32×32 pixels
  - NTSC output signal ad 60 Hz (can be seen on any modern TV set, even PAL)
  - text mode: 40×24 chars (6×8 pixels per char)
  - text/graphic mode: 32×24 chars (8×8 pixels per char) with tile graphics and sprite support
  - graphics mode: 256×192 pixels with bitmap graphic and sprite support
  - multicolor mode: 64×48 pixels
- Audio: YM2149F (or AY-3-8910):
  - 3 analog outputs
  - 8 octaves
  - white noise on any audio channel
  - envelope support
  - 2×8 bit I/O ports
- Peripherals:
  - Z80 SIO:
    - 2x serial ports with a/synchronous support
    - up to 57600 bps
    - 5/6/7/8/9 pixels per char
    - parity and stop bits supported
  - Z80 PIO:
    - 2×8 bit parallel ports
    - port B is connected to a 8×LEDs matrix for status messages
  - Z80 CTC:
    - 4x channels timer/counter
    - used to generate the 1/100th of a second system tick signal that is used to temporize some internal operations
    - also used to generate the software-select serial clock for the Z80 SIO
- Mass storage:
  - Compact Flash cards, supported as “floppy disks” by LM80C DOS

IMPORTANT NOTE: due to the better tech. Specifications & performances of the LM80C 64K, the LM80C Color Computer has been DISCONTINUED and it won’t be developed anymore. New users should start using the LM80C 64K model while for current users of LM80C it is recommended to switch to the bigger model to get advantage of its features.

## 1.5 Boot

At boot the LM80C visualizes a colorful logo with a little beep: during this short time, the user can interact with the firmware by pressing some keys. If CTRL is being kept pressed, then the computer will disable the DOS, freeing up the memory occupied by the file routines and giving back to the user about 4.4KB of memory. Pay attention that when the DOS is being disabled, this condition will be maintained until an hard-reset or a power-off/power-on will take place: this is to preserve the environment, in case a big program would be present in memory that could occupy the area normally used by DOS.

Instead, pressing RUN STOP will force the firmware to reload the firmware from ROM to RAM (“hard reset”), deleting any change to the firmware code being made by the user.

Finally, the current version of the firmware is shown with the copyright messages of the Z80 BASIC from Microsoft (©1978) and the amount of free RAM for BASIC programs (this value may vary from release to release). The text below is printed by LM80C 64K firmware R1.19:

LM80C 64K Color Computer

by Leonardo Miliani * FW R1.19

LM80C BASIC 3.26 ©2021 L.Miliani

Z80 BASIC 4.7 ©1978 Microsoft

LM80C DOS 1.06 Loaded

38807 Bytes Free

Ok

After a reset the user is asked to choose between a “cold” or a “warm” start. A cold start is just like a power off/power on of the system: every register in memory is re-initialized and the previous contents of the RAM are cleaned, including the current BASIC program. Instead, a warm start preserves the BASIC program in RAM. The choose is made by pressing the C or W keys when prompted for:

<C>old or <W>arm start?

If the cold start is chosen, the system will print the copyright notices with the available free memory; if the warm start is chosen, then only the prompt Ok will be printed.

## 1.6 Version numbering

There are several version numbers for the firmware, the LM80C BASIC, the LM80C DOS, and the source files.

Actually, the version numbering adopts the following scheme:

RX.YY

where “R” stands for “Release” and introduces every software release. “X” is the major number of the release, while “Y” is the minor number, i.e.: R1.03 stands for the third minor release (03) of software version R1; R3.16 stands for the 16th minor release of software version R3.

Firmware and BASIC versions were identical until the release of the LM80C 64K model. From then on, the BASIC version differs from the one of the firmware. Furthermore, since the release of firmware R1.10, there is also the LM80C DOS. So, firmware R1.19 for the LM80C 64K includes the BASIC V3.26 and LM80C DOS 1.06.

# 2. LM80C BASIC

## 2.1 Differences with NASCOM BASIC

The LM80C BASIC is a complete BASIC interpreter written to take advantage of the hardware features of the LM80C Color Computer. Due to the differences between the original NASCOM systems and the LM80C hardware, some statements have been removed from the interpreter because they laid over the original NASCOM machines. They are:

CLOAD/CSAVE: loaded/stored data from/to an external mass storage device

LINES: set number of lines to be printed simultaneously

MONITOR: it launched the MONITOR program

NULL: set the null chars to be printed at the end of a line

PSET: set a video pixel on

Some statements now have a different behavior:

POINT: returns the state of a video pixel

RESET: resets the system

SCREEN: changes the video mode

There are a lot of new statements, used to take advantage of the much powerful hardware of the LM80C. But, firstly let's start with a big thanks to Grant Searle, from whose BASIC comes the LM80C version, that added some useful statements (they are marked with a "*GS*"). The complete list of the statements available in LM80C BASIC is available in chapter 3.

## 2.2 Modes of operation

The LM80C BASIC operates in two different modes. In direct mode it executes the commands as they are entered at the prompt and prints the results of the statements directly on the screen. This mode is useful if you intend to use the computer as a “calculator” but the instructions are lost as soon as they are executed.

In indirect mode the computer executes the instructions from a program stored into the main memory.

Not all the statements can be executed in direct and indirect mode. As an example, the INPUT statement can only be executed inside a program (indirect mode), while the CLS command, that clears the screen, can be executed in both direct and indirect modes.

## 2.3 New numeral systems

The same number can be represented in several different numeral systems. The usual one is the decimal numeral system, where every single digit can only be the usual numerical digits from 0 to 9. LM80C BASIC supports other systems for numbers: binary and hexadecimal numeral systems. The first one uses only 0 & 1 digits and it’s the “language” of the digital signals used inside the computers, while the hexadecimal is a representation used in assembly language which uses a base of 16, so that every digit can be any number from 0 to 9 plus the letters from A to F to represent the values from 10 to 15. A base-2 number is preceded by the prefix &B while a hexadecimal number is introduced by the prefix &H:

&Hxxxx: hexadecimal base. *GS*

&Bnnnn: binary base. *GS*

There is also another way to manage hexadecimal and binary numbers: by using the VAL function, that returns the value of a string expression, you can use the trailing “$” char for hexadecimal values and “%” for the binary values. See VAL for more information.

## 2.4 Functions

A function is a statement that gets an input parameter and returns another data, that depends on the way it processes the input. A function can not be used in direct mode, i.e. this statement is not valid:

INPUT A

and will return an error.

The followings are some of the new functions that weren’t present on the original NASCOM BASIC:

BIN$: return the binary representation of a number. *GS*

HEX$: return the hexadecimal representation of a number. *GS*

INKEY: return the ASCII code of the key being pressed

INSTR: return the position of a string inside another one

SSTAT: read the registers of the PSG

TMR: return the value of the system timer

VPEEK: read from VRAM

VSTAT: return the value of status register of the VDP

## 2.5 Commands

Commands are statements that tell the system to perform a specific operation. Commands can get some parameters but usually don't return any value. Commands can be used in direct or indirect mode. Here are some of the new commands added to manage the features of the hardware of LM80C:

CIRCLE: draws a circle

COLOR: set the foreground, background, and border colors

CLS: clearsthe screen

DISK: format/rename a disk

DRAW: draw a line

ESARE: delete a file on the disk

FILES: list the files stored into a disk

HELP: print the line where an error has occurred

LOAD: load a file from a disk

LOCATE: position the cursor onto the screen

PAUSE: pause the execution of the code for a certain bit of time

PLOT: draw a pixel point

RESET: reset the system

SAVE: save a file on a disk

SCREEN:change the display mode

SERIAL:open a serial communication line

SOUND: plays a sound tone

SREG: writes into a PSG register

SYS: executes an assembly routine

VOLUME:sets the volume of the PSG audio channels

VPOKE: writes into VRAM

VREG: writes into a VDP register

XOR: make a XOR between operators

## 2.6 Line input

Any line starting with a number and followed by one or more statements introduces a program line. Line numbers must be in the range from 0 to 65.529.

Examples:

10 PRINT "HELLO"

When RETURN is pressed, the line is stored into memory. If a line with the same number is already present in memory, then the new one will overwrite the current line into memory. If we digit the following line with the same number of the previous one:

10 PRINT "WORLD"

Then, when running this program, we will get the following result:

WORLD

When a number is typed in with anything following but a RETURN, it will be interpreted as a direction to the BASIC to remove from the program the line number whose number is being entered. The example below will remove the line 10:

10

If such line is not present in memory, then an “Undefined Line Error” will be raised.

## 2.7 Numbers

LM80C BASIC accepts any integer or floating point number as constants. Allowed formats are with or without exponent notation, i.e.:

123

0.456

1.25E+06

They are all acceptable numeric constants. Any number of numerical digits can be input up the maximum allowed number of chars per single line, however only the first 7 digits of a number are significant and the seventh digit is rounded up. So the following instruction:

PRINT 1.234567890123

will produce the following output:

1.23457

A printed number is preceded by the sign “-” if it is negative:

PRINT -1.2

-1.2

If the number is positive, then an empty cell will be printed as leading char:

PRINT 1.2

1.2

LM80C BASIC integers are 16-bit signed integers. When printing integer values, i.e. numbers that can be represented using 16 bits, keep in mind that the most significant bit is used for the sign: this means that they can only go from -32.768 to +32.767. Also, consider that when managing such numbers, if you want to use values bigger than 32.767 you have to subtract the number from 65.536. In the example below we try to write a 16-bit unsigned value into RAM:

DOKE 45056,45056

?Illegal Function Call Error

We get an error because 16-bit integers are managed as signed integers and 45.056 is bigger than the biggest positive signed integer allowed (+32.767).

So, to do such operation we can go through 2 different ways. The first one is to use hex numbers:

DOKE &HB000,&HB000

Ok

The second one is to use 16-bit signed integers, and to do this we must subtract 65.536 from our value and use the results:

?45056-65536

-20480

DOKE -20480,-20480

Ok

To get back the word from memory cells 45.056 & 45.057 we must do something similar and get similar results:

?DEEK(45056)

?Illegal Function Call Error

?DEEK(-20480)

-20480

?DEEK(&HB000)

-20480

In the same manner, to get back the results in 16-bit unsigned integer we must subtract the value from 65.536:

?65536-20480

45056

Pay great attention that this is not an issue since the BASIC interpreter manages numbers correctly when operating arithmetical operations. You should only consider that numbers that can be stored into 16 bits are represented as signed numbers during input/output, so consider this when interact with the user.

If the absolute value of a number is in the range from 0 to 999.999, the number will be printed as an integer:

PRINT 123567

123567

If the absolute value of a number is greater than or equal to 0,01 and less than or equal to 999.999, it will be printed in fixed point notation with no exponent:

PRINT 99000.1

99000.1

If a number doesn’t fall into the previous two categories, it will be printed using the scientific notation, whose format is as follow:

sX.XXXXXEsTT

Where <s> stands for the sign of the mantissa (the part to the left of the decimal point) and the exponent (the part to the right of the decimal point), <X> for the digits of the mantissa and <T> for the digits of the exponent. Non-significant zeroes in the mantissa are suppressed while two digits are always printed in the exponent. The convention rules for the sign seen above are also followed for the mantissa. The exponent is in range from -38 to +38. The largest number that may be represented is 1,70141E+38 while the smallest positive number is 2,9387E-38.

The followings are output examples of how the LM80C BASIC prints some numbers:

+1 1

-1 -1

1000000 1E+06

-12.34567E-10 -1.23456E-09

.01 .01

.000123 1.23E-04

In all formats, an empty char is printed after the last digit.

## 2.8 Variables

A variable is a kind of pointer: it’s a label that refers to a certain portion of the memory of the computer where a specific value is stored. A variable can lead any value, assigned explicitly by the programmer or assigned as the result of some calculations. To assign a value to a variable, an equal sign = is placed between the name and the value being assigned. The name of a variable may be any length but the alphanumeric characters after the first two are ignored: this means that 2 different variable names that have the same two leading chars will refer to the same variable into memory:

WTS (interpreted as WT)

WTP (interpreted as WT, too)

They are interpreted as the same variable and so they will both refer to the same value into memory:

10 WTS=10

20 WTP=20

30 PRINT WTS

RUN

20

Also, the first character of the name must be a letter, and no reserved words may be used as a variable name or appear within a variable name. Here are some examples of valid names:

A

P1

CRO

Here are some names that are NOT valid:

%W first char must be a letter

ON reserved word

RGOTOX it contains a reserved word (GOTO)

### 2.8.1 Numeric variables

A numeric variable is a variable that stores numbers. A numeric variable is represented by a variable name that is assigned a numeric constant by the user or as the results of an expression that returns a numeric value:

A=10

B=A

You can assign both integers and floating-point numbers, although they are always stored in memory as floating point numbers. This means that 10 and 10.0 makes no difference for the BASIC interpreter. Before a value is assigned to a numeric variable, its value is assumed to be zero.

### 2.8.2 Strings

Despite numeric variables, that can only store numbers, a string is a sequence of alphanumeric characters like letters, numbers, punctuation, and other chars. A string must be included between double quotation marks, at the beginning and at the end of the chars that form the string itself. A trailing $ in the variable name identifies a string. The following is an example of a string definition:

A$="TEST"

Strings can be concatenated by using the + operator. The concatenation results in the second string being attached at the end of the first one (“appended”):

10 B$="WORLD"

20 A$="HELLO " : REM NOTE THE SPACE AT THE END OF THE WORD HELLO

30 C$=A$+B$:PRINT C$

Running the program above will result in this message being printed on the screen:

HELLO WORLD

Strings can be evaluated with relational operators. In this case the strings are taken into account of the ASCII value of their characters until a difference is found. So, for example, "a" > "A" is true because ASCII value of a is 97 while A is 65. Spaces are considered, too, so " a" > "a" is False: note the leading space in the first string.

A string can be up to 255 chars. However, at any time string characters must not exceed the space allocated by the system to store strings: the LM80C by default reserves 100 bytes. If the program tries to create a string that exceeds the string space an OUT OF STRING SPACE error will be raised. This amount can be changed with the CLEAR statement.

### 2.8.3 Array variables

An array variable is a series of several variables refered to by the same name. An array is created by using the DIM statement:

DIM VV(<subscript>[,<subscript>,…)

where <VV> is a valid name for a variable (see above) and <subscripts> are the dimensions of the array. An array may have as many dimensions as will fit on a single line and can be accommodated into the memory. A subscript must be an integer value: the smallest subscript is 0, zero. This means that an array always has as many items as the subscript plus 1. See the examples:

DIM A(10,10)

defines an array of 121 elements, because each dimension is formed by 11 elements, from 0 to 10.

DIM A(5)

defines a mono-dimensional array of 6 elements (whose indexes go from 0 to 5).

Each DIM statement can apply to more than 1 array:

DIM A(10,5),B(8,2)

Also, an array can be resized during program execution:

DIM A(I+2)

At runtime, the expression is evaluated and the results truncated to an integer.

If an array has not been dimensioned before it is used in a program, the LM80C BASIC assumes that is has default subscript of 10 (11 items) for each dimension. A SUBSCRIPT OUT OF RANGE error is raised if an attempt is made to access an item outside the limits fixed by a DIM statement:

10 DIM A(10,10)

20 B=A(5,5,5) => error: indexes are outside the assigned space

A REDIMENSIONED ARRAY error is raised if an attempt to re-dimension an array is made in the program:

10 DIM A(10,10)

20 DIM A(20,20) => error: array already dimensioned

A string array can be defined with the DIM statement: each element of the array is a string that may be up to 255 chars:

10 DIM A$(10)

20 A$(1)="HELLO":A$(2)="WORLD"

### 2.8.4 Variable names

Now that we've seen the different types of data that the interpreter can handle, it's important to go back to the variable names again. As said earlier, the name of a variable can only be 2 characters long. Despite this limit, the interpreter is able to recognize between variables with similar names but different types, so AA (a numeric variable) is different from AA$ (a string variable) and AA(..) (an array variable). In the example below, the 3 variables all point to different values:

10 AA=10:AA$=”HELLO”:DIM AA(10):AA(1)=0.56

20 PRINT AA,AA$,AA(1)

10 HELLO .56

The interpreter recognizes the different variables and retrieve the correct values from the corresponding memory cells.

## 2.9 Operators

Let’s get a more accurate overview on the operators supported by LM80C BASIC. Mathematical operators permit to make math calculations like additions, subtractions, and similar:

+ → “plus” operator

Make the sum of two numerical expressions. The results can be assigned to a variable or printed as is. Examples:

A=12+3

PRINT 12.6+7.8

The “plus” operator (+) can also be used to concatenate two strings (see chapter 2.9)

- → “minus” operator

Subtracts the value of the second expression from the first one. The results can be assigned to a variable or printed as is. Examples:

A=12-3

PRINT 12.6-7.8

* → “times” operator

Return the multiplication of two numerical expressions. Examples:

A=12*3

PRINT 12.6*7.8

/ → “division” operator

Return the division between two numerical expressions, the dividend and the divisor. Examples:

A=12/3

PRINT 12.6/7.8

The value of the expression representing the divisor can not be 0 otherwise a DIVISION BY ZERO ERROR will be raised:

PRINT 12/0

? Division by Zero Error

% → “modulo” operator

Return the modulus of a division, namely the remainder of an integer division. Let’s say that we have to compute 12 modulo 5. The result is 2:

12 % 5 = 2

because 12/5 has a quotient of 2 and a remainder of 2. In fact, 12-(5*2)→ 12-10=2

12 % 6 = 0

because 12/6 has a quotient of 2 and a remainder of 0. In fact, 12-(6*2) → 12-12=0

The two expressions must be integer values: if they are floating point numbers, they will be truncated and only their integer parts will be considered:

12.6 % 4.3 = 0

because

INT(12.6)=12

INT(4.3)=4

so the previous operation becomes

12 % 4 = 0

# → “integer division” operand

Return the integer part of the division of two numerical expressions. This is equivalent to call the INT function after a regular division:

12.6 / 2.7 = 4.66667

12.6 # 2.7 = 4

INT (12.6 / 2.7) = 4

^ → “exponent” operand

The exponentiation is a repeated multiplication of the base times the exponent:

3^3 = 27

that is equivalent to 3*3*3. Note: any number to the 0 power is 1; 0 to any power is 0; 0 to a negative power raises a Division by zero error.

123^0 = 1

0^5 = 0

0^-1 = Division by Zero Error

( ) → parentheses

In mathematical expressions the parentheses are used to clarify or change the precedence of operations set by the operands’ precedence. Let’s see the example below:

A = 12 + 3 / 4

By looking at the operators’ precedence table in chapter 2.11, it’s easy to understand that the division will be executed before the addition because it has a greater precedence, so the result will be 12,75. In fact, the formula is interpreted as follow:

A = 12 + (3 / 4)

Now, let’s take a look at this one:

A = 12 * 3 / 4

In the above formula, the precedence of the operators says us that when two or more operators have the same precedence they are executed in the order they appear in the code line, so the result is 9, because the expression is interpreted as follow:

A = (12 * 3 ) / 4 = 9

In fact, if we invert the operations:

A = 12 / 3 * 4

the result changes, and now it is 16, because the formula is seen as follow:

A = (12 / 3) * 4 = 16

If we want to change the order of the operations, we can use the parentheses:

A = 12 / (3 * 4 ) = 1

In the example above, we forced the interpreter to executed first the multiplication and then the division.

Parentheses can be nested, for more complex expressions:

A = 12 / (3 * 4 + (45 – 7) * (12 + (7 / 5 )) + 3) = 0.022892

= → “equal” operator

The equals sign is used to assign a value to a variable:

A = 12 + 4

A will get the results of the addition, 16.

It’s also used as a relational operator to check that 2 expressions have the same value:

10 IF A = B THEN PRINT “OK”

The program will print OK only if variables A and B have the same value.

<> < > <= >= → relational operands

These operands complete the family of relational operands used in boolean expressions to branch in different portion of code, depending the values assumed by expressions. Examples:

10 IF A <> B THEN 100: REM JUMP IF A AND B DIFFER

20 IF A < B THEN 200: REM JUMP IF A IS LESS THAN B

30 IF A > B THEN 300: REM JUMP IF A IS GREATER THEN B

40 IF A <= B THEN 400: REM JUMP IF A IS LESS THAN OR EQUAL TO B

50 IF A >= B THEN 500: REM JUMP IF A IS GREATER THAN OR EQUAL TO B

## 2.10 Operator precedence

LM80C BASIC provides a full range of mathematical and logical operators. The order of execution of the operations in an expression is done in accordance to their precedence, as shown below in decreasing order. Operators on the same line in the table below have the same precedence and are evaluated from left to right in an expression:

- ( ) → parentheses
- ^ → exponentiation
- - → Negation: this is the unary minus operator
- * / % # → multiplication, division, modulo, integer division
- + - → addition, subtraction
- relational operators:
  - = → equal
  - <> >< → not equal
  - < → less than
  - > → greater than
  - <= =< → less than or equal to
  - >= =< → greater than or equal to
- NOT logical, bitwise negation
- AND logical, bitwise disjunction
- XOR logical, bitwise exclusive disjunction
- OR logical, bitwise conjunction

Relational operators may be used in any expressions: relational expressions return a value of -1 (True) or 0 (False).

Logical operators may be used for bit manipulation and boolean algebraic expressions. AND, OR, XOR, and NOT convert their values into 16-bit signed two’s complement integers in the range from -32.768 to +32.767: if the parameters are not in this range an ILLEGAL FUNCTION CALL error is raised. See language references for truth tables of each operator.

## 2.11 Error management

Errors are managed by LM80C BASIC interpreter. In direct mode every time that the user press the RETURN key the interpreter parses the statements entered and execute them. If it finds a non valid statement it raises a message error telling the user what’s gone wrong, i.e.: if a sum between a numerical and a string variable is asked:

PRINT 1+"2"

A Type Mis-match Error will be printed out. Since in direct mode the interpreter doesn’t store the instructions that are being executed, the only way to rectify the error and get the correct result is to re-enter the instruction:

PRINT 1+2

3

If an error occurs while running a program, the interpreter will stop its execution and will print the message that identifies the error with the addition of the line where the error has occurred. For example, if the following program will be run:

10 A=0

20 PRONT A

The error will also report the number of line:

RUN

?Syntax Error in 20

To fix the error, the user must re-enter the line by typing it again or by listing it, move the cursor over the error, type the correct syntax of the statement and then press RETURN. It may help to use the HELP command that immediately lists the line containing the error:

RUN

?Syntax Error in 20

HELP

20 PRONT A

If the RUN STOP key is pressed while a program is being executed, the interpreter will print a message to show that the program has been halted by the user. Let’s consider the following code:

10 A=0

20 FOR I=0 TO 100

30 A=A+I

40 NEXT

If, after the RUN command has been entered, the RUN STOP key is pressed, then the interpreter will return to the prompt (direct mode) and print a message saying in which line the execution has been interrupted:

Break in 30

To resume the execution, the user can use the CONT command: the interpreter will continue from the line following the one where the program was interrupted. However, if a change is made in the program before the CONT, or another error is raised in direct mode, the interpreter won’t be able anymore to resume the execution of the program, raising a Can’t Continue Error.

If, after the program has been halted, the user enters the HELP command, the line of the break will be printed as it was a normal error:

HELP

30 A=A+I

# 3. LM80C BASIC INSTRUCTIONS

## 3.1 In alphabetical order

&B

&H

ABS

AND

ASC

ATN

BIN$

CHR$

CIRCLE

CLEAR

CLOSE

CLS

COLOR

CONT

COS

DATA

DEEK

DEF

DIM

DISK

DOKE

DRAW

END

ELSE

EOF

ERASE

EXIST

FILES

FN

FOR

FRE

GET

GOSUB

GOTO

HELP

HEX$

IF

INKEY

INP

INPUT

INSTR

INT

KEY

LEFT$

LEN

LET

LIST

LOAD

LOCATE

LOG

MID$

NEW

NEXT

NMI

NOT

ON

OPEN

OR

OUT

PAUSE

PEEK

PLOT

POINT

POKE

POS

PRINT

PUT

READ

REM

RESET

RESTORE

RETURN

RIGHT$

RND

RUN

SAVE

SCREEN

SERIAL

SGN

SIN

SOUND

SPC

SQR

SREG

SSTAT

STEP

STOP

STR$

SYS

TAB

TAN

THEN

TMR

TO

USR

VAL

VOLUME

VPEEK

VPOKE

VREG

VSTAT

WAIT

WIDTH

XOR

## 3.2 Per category

### 3.2.1 Arithmetical operators

- Subtraction

+ Addition

/ Division

% Modulo

# Integer Division

* Multiplication

^ Power

### 3.2.2 Call/Return, Jump and Loop

FOR..NEXT

GOSUB

GOTO

RETURN

### 3.2.3 Timing

TMR

PAUSE

### 3.2.4 Conditions

< Checks if the first parameter is less than the second

> Checks if the first parameter is greater than the second

= Checks if the first parameter is equal to the second

<= Checks if the first parameter is less than or equal to the second

>= Checks if the first parameter is greater than or equal to the second

<> Checks if the first parameter is different than the second

IF...GOTO

IF...THEN...ELSE

ON...GOSUB

ON...GOTO

### 3.2.5 Conversion Functions

&B

&H

ASC

BIN$

CHR$

HEX$

STR$

VAL

### 3.2.6 Code flow and programming

CONT

END

HELP

LIST

REM

RUN

STOP

### 3.2.7 Graphics statements

CIRCLE

COLOR

DRAW

GPRINT

PAINT

PLOT

POINT

VPEEK

VPOKE

VREG

VSTAT

### 3.2.8 Display

CLS

LOCATE

POS

PRINT

SCREEN

SPC

TAB

WIDTH

### 3.2.8 System & Input/Output

INP

OUT

RESET

SERIAL

WAIT

### 3.2.9 Keyboard

INKEY

INPUT

KEY

### 3.2.10 Logical operators

AND

NOT

OR

XOR

### 3.2.11 Mathematical functions

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
### 3.2.12 Machine Language Functions

SYS

USR

### 3.2.13 Memory management

CLEAR

DEEK

DOKE

FRE

NEW

PEEK

POKE

### 3.2.14 Sound

SOUND

SREG

SSTAT

VOLUME

### 3.2.15 String Handling

INSTR

LEFT$

LEN

MID$

RIGHT$

### 3.2.16 Variable settings, data management, & user defined functions

CLEAR

DATA

DEF FN

DIM

LET

READ

RESTORE

### 3.2.17 DOS commands

CLOSE

DISK

EOF

ERASE

EXIST

FILES

GET

LOAD

OPEN

PUT

SAVE

# 4. LANGUAGE REFERENCE

### &B

Syntax: &Bnnnn

Binary base. It interprets the parameter <nnnn> as a binary value (signed int.). <nnnn> can be made only by "0" and "1" digits.

Example:

?&B1000 => prints value 8

### &H

Syntax: &Hxxxx

Hexadecimal base. It interprets the parameter <xxxx> value as an hexadecimal value and returns a signed int. Each char of <xxxx> can only be any number between 0 and 9 and any letter between A (10) and F (15).

Example:

?&H0F => prints value 15

### ABS

Syntax: ABS(x)

Returns the absolute value (i.e. with no sign) of the expression <x>.

Examples:

ABS(12.4) => 12.4

ABS(-75) => 75

### AND

Syntax: arg1 AND arg2

Logic operator used in boolean expressions. AND performs a logical conjunction. The interpreter supports 4 boolean operators: AND, OR, XOR, and NOT, each of them work with 16-bit signed integers. They convert their inputs in 16-bit integers and return a value in such format. This means that the result is true only if both expressions <arg1> and <arg2> are true. The result of an AND operation follows the truth table below, where 1=T(rue) and 0=F(alse):

0 AND 0 = 0

0 AND 1 = 0

1 AND 0 = 0

1 AND 1 = 1

Examples:

10 AND 1 => 0 (because 10=1010b so 1010 AND 0001 = 0000)

11 AND 1 => 1 (because 11=1011b so 1011 AND 0001 = 0001)

See also: NOT, OR, and XOR.

### ASC

Syntax: ASC(X$)

Returns the ASCII code of the first character of the string <X$>.

Example:

ASC("A") => 65

ASC("AB") => 65

See the appendix 5.1 to look at the built-in ASCII table.

### ATN

Syntax: ATN(x)

Returns the arc-tangent of <x>. The result is in radius in the range from -pi/2 to pi/2, where “pi” is greek pi, 3,1415927.

Example:

ATN(2) => 1.10715

### BIN$

Syntax: BIN$(x)

Converts an expression into a string containing the binary representation of parameter <x>.

Example:

BIN$(12) => "1010"

### CHR$

Syntax: CHR$(x)

Returns a string containing the character whose ASCII code is represented by expression <x>.

Example:

CHR$(65) => "A"

See the appendix 5.1 to look at the built-in ASCII table.

### CIRCLE

Syntax: CIRCLE x,y,radius[,color]

Draws a circle whose center is at <x>,<y> coordinates. <x> can go from 0 to 255, while <y> can go from 0 to 191. The origin of coordinates (0,0) is set at the top left corner of the screen. <radius> can go from 0 to 255. Points of the circumference that come out of the screen won't be painted. If <color> is passed, the circle will be drawn with the color being specified, otherwise the foreground color set with COLOR will be used. <color> goes from 0 to 15: colors from 1 to 15 correspond to the system colors while 0 is a special value that instructs the BASIC to draw a circle using the background color set with COLOR, i.e. to reset the pixels that are on.

Example:

CIRCLE 128,96,25 => draws a circle centered in the middle of the screen with a diameter of 50 pixels (radius=25) using the predefined foreground color

CIRCLE 128,96,25,0 => erases the circle previously drawn using the background color

See also: COLOR for color codes and foreground/background colors.

### CLEAR

Syntax: CLEAR [xx][,yy]

Calling CLEAR with no parameters erases any variable in memory: this means that it sets the contents of all the numeric variables to 0 and the string variables to "" (empty string). CLEAR is automatically called when a RUN or NEW command is invoked.

If called with a numeric expression, it sets the string space to the value of argument <xx>. After a boot or a reset, the string space is by default set to 100. See the string chapter at 2.9 for more info.

If the second numeric parameter is also present, then CLEAR sets the top of the RAM available to BASIC programs to <yy>.

Both <xx> and <yy> must be capable of being evaluated as a signed integer (in the range from -32.768 to +32.767).

Examples:

CLEAR => clears every variable

?FRE(0) => check free RAM for BASIC

-21213 => 44343 - this value can change for different FW versions

?FRE("") => check string space

100 => default value

CLEAR 200 => sets the string space to 200 chars

?FRE("") => check string space

200

?FRE(0)

-21313 => 44223 - free RAM reduced by 100 bytes

CLEAR 300,-20000 => -20000 = 45536

?FRE("")

300

?FRE(0)

24124 => free RAM reduced by ca. 20,000 bytes

### CLOSE

Syntax: CLOSE x

It closes a sequential file that was opened with OPEN. When writing to a file, CLOSE saves the last data inserted into the buffer and align the info of the file entry into the directory. When reading from a file, CLOSE closes any pending reference to a sequential file so that the DOS can access to another file or to the disk for other operations. <x> must match the file number used to open the file with the OPEN command.

The example below closes the file whose number is 1:

CLOSE 1

See also: EOF, GET, OPEN, PUT.

### CLS

Syntax: CLS

Clears the current screen, initializing the pattern cells to a default value. The default fill value is always $00 but it takes on a different value depending on the graphics mode: in modes 0, 1, and 4 it represents the character $00 (the null character) while in modes 2 and 3 it resets the image pixels. Finally, in text modes, it also moves the cursor at coordinates 0,0 (the top left corner of the screen). CLS clears the screen by using the background color set with COLOR statement. Same behavior can be obtained in text modes by pressing together the SHIFT + CLEAR/HOME keys.

### COLOR

Syntax: COLOR foreground[,background][,border]

Sets the colors of the screen. It can have from 1 to 3 arguments, depending of the current video mode. <foreground> sets the color of the text or of the pixels being printed on screen; <background> sets the color of the background parts, while <border> sets the colors of the borders of the image (the parts over the top, right, bottom, and left of the image screen).

Values go from 1 to 15, as follow:

1: black | ______ | 6: dark red | ______ | 11: light yellow | ______
2: medium green | ______ | 7: cyan (aqua blue) | ______ | 12: dark green | ______
3: light green | ______ | 8: medium red | ______ | 13: magenta (purple) | ______
4: dark blue | ______ | 9: light red | ______ | 14: gray | ______
5: light blue | ______ | 10: dark yellow | ______ | 15: white

Pay attention that:

- in screen 0 (text mode), only the first 2 arguments are allowed since the background and border colors coincide;
- in screen 1 & 4 (text/graphics modes) all 3 arguments must be passed;
- in screen 2 (bitmap graphics mode) all 3 arguments must be passed. Remember that in screen 2 the color of the pixels painted by PLOT, DRAW, and CIRCLE, otherwise not specified, is the foreground color set by COLOR;
- in screen 3 (multicolor mode) only one parameter is accepted and refers to the border color.

Examples:

COLOR 1,15,5 => in SCREEN 1 it sets the text in black, the background in

white, and the border in light blue

COLOR 15,5 => in SCREEN 0 it sets the text to white on light blue

background (this is the default combination)

COLOR 3 => in SCREEN 3 sets the border color to light green

Statements PLOT, DRAW, and CIRCLE can use “0” as a color value. This doesn’t correspond to any of the system colors and it’s just a way to instruct the BASIC interpreter to draw pixels using the background color, i.e. to reset the pixels that are on. “0” can not be used as a value for COLOR, raising a Syntax Error.

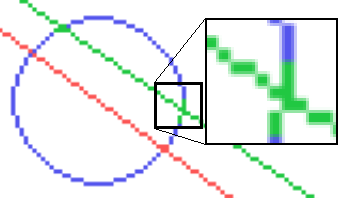
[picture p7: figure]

It is important to know how the VDP works in bitmap graphics mode. For every group of 8 horizontal pixels, corresponding to 8 bits in memory (or 1 byte), only 2 colors are allowed: the foreground and background colors. The former is used to color the pixels that are set (i.e. that are ON, corresponding to bits of value “1”) while the latter is uded to color the pixels that are reset (i.e. that are OFF, corresponding to bits of value “0”). If you try to draw a pixel with another color, i.e. you try to redefine the foreground color, this change will alter the color of all the pixels that are set in such byte. This means that if you draw a line in a part of the screen with a color and then you intersects such line with another one with a different color, the color of the last one will alter the colors of the pixels of the first one. This behavior is shown in the right image. By having a dark blue circle drawn over a white background, a third color may interfere with the pixel already present: in the box it is shown that the green line, by intersecting the blue circle, interfere with the pixels of the latter, changing their color. This artifact is commonly known as “color clash” and “attribute clash”, or “color spill”.

### CONT

Syntax: CONT

Typed after an error that halted the execution of a program, CONT forces the interpreter to continue from the line after the one that raised the error. When in direct mode, if another error occurs the continuation of the main program is not possible anymore.

### COS

Syntax: COS(x)

Returns the cosine of <x>. The result is in radius in the range from -pi/2 to pi/2.

Example:

COS(10) => -0.839072

### DATA

Syntax: DATA <list>

Introduces a list of data used by the program itself. <list> can be a list of numerical or string data, separated by commas and read with the READ statement. A string can be inserted without quotation marks, but, if the string contains any space, their use is mandatory.

Example:

10 DATA 20,30,40 => numerals

20 DATA " HELLO ",LM80C

Note at line 20 the usage of quotation marks to include the leading and trailing spaces in the first string, while in the second one the quotations marks can be omitted.

See also READ and RESTORE.

### DEEK

Syntax: DEEK(nnnn)

Reads a word from a pair of memory cells whose addresses are given by the expression <nnnn> and <nnnn>+1. <nnnn> must be a numerical expression whose value must be in the range from 0 to 65.535. A word is a 16-bit value stored in 2 contiguous memory cells: <xxxx> contains the low byte while <nnnn>+1 contains the high byte (little-endian system).

Example:

A=DEEK(1000) => reads the word at 1000/1000+1 and stores it into A

See also DOKE.

### DEF FN

Syntax: DEF FNname(arg)=<expression>

Creates an user-defined function that expands the built-in functions of the interpreter. <name> is the name of the new function: it must follow the FN statement and must be a valid name of variable; <arg> is the name of the parameter being passed that will be used by the function and it must be a valid name of variable (see chapter 2.8 for valid name of variables); <expression> is the newly defined function. Limits: everything must reside inside the length of a standard line, and only one parameter is allowed.

To call the function, just use FNname with the needed argument.

Example:

10 DEF FNRAD(DEG)=3.14159/180*DEG:REM DEFINE THE FUNCTION

20 PRINT FNRAD(100):REM FUNCTION CALL - PRINTS 1.74532

### DIM

Syntax DIM <name>(<dim1>,[dim2])[,....]

Allocates space for array variables. More than one array can be sized with one DIM statement. Arrays can have one ore more dimensions. If an array is used without being sized, it is assumed to have a maximum subscript of 10: this means that it will contain eleven elements, from 0 to 10. So, for example, the array A(I,J) is assumed to have 121 elements, unless otherwise sized.

Examples:

DIM A(10) => mono-dimensional array, elements numbered from 0 to 10

DIM B(5,5) => bi-dimensional array, indexes from 0 to 5 (36 elements).

See also array chapter at 2.10.

### DISK

Syntax: DISK "cmd"[,"diskname"]

This is the main command to pilot the disk interface. With DISK it is possible to execute several operations from which the user can choose via the argument <cmd>: format (initialize) a disk, creating a fresh new file system; rewrite the Master sector; rename the disk; undelete deleted files.

DISK FORMATTING

The argument F instructs DISK to format a disk, setting its name to “diskname”. Before to execute the job, a confirmation from the user is required: by pressing y or Y the operation will be executed, while any other key will abort it. When formatting a disk, a progress bar will show how far away is the end. After the job has been executed, a little recap will be printed on screen with the new name of the disk, the number of total sectors and the amount of allowed files. The available space is related to the size of the Compact Flash used.

The example below formats a new disk with name “DISK1”:

DISK "F","DISK1"

WARNING!! Format disk? (Y)

--------- ← progress bar

Operation completed
Disk name: DISK1

Sectors: 501760/0

Allowed files: 3920
Ok

MASTER SECTOR REWRITING

The argument W tells DISK that the LM80C DOS has to rewrite the Master Sector (sector #0) of the disk. This operation may be necessary if such sector has been altered for some reason, i.e. a routine that did a wrong writing operation over it. Keep in mind that to rewrite such sector, a new disk name is mandatory. Don’t worry, no other data will be altered, so the directory won’t be lost nor the files stored onto the disk. This example rewrites the Master Sector onto the disk:

DISK "W","DISK1"

Rewrite Master Sector? (N)

Aborted
Ok

DISK RENAMING

Sometimes changing the disk name may be needed: this operation is invoked with argument R. Unlike the previous operations, changing the disk name doesn’t alter any other data in the Master Sector nor other sections of the disk:

DISK "R","MYDISK"

Rename disk? (Y)

Ok

Pay attention that disk names can only contain char letters from “A” to “Z”, char numbers from “0” to “9”, a “space” or the “-” (minus symbol). Other chars are not allowed and raise an error. This is also valid for file names, too.

FILE UNDELETING

When a file has been deleted using the quick mode of the ERASE command, it is possible to recover it easily by using the undelete feature of the DISK command, invoked with argument U:

DISK "U"

XAC-MAN undeleted

The command above will scan the directory looking for deleted files and recover them by undeleting their entries. The entire directory will be scanned so more than one file may be recovered. Since the quick erase just marks the file as deleted by setting the 8th bit (the most significant bit) of the first char of the file name, it will easily recover the file name by resetting such bit. When a file is undeleted, a message with its new name is printed on screen. Keep in mind that it is possible to undelete a file if its entry hasn’t been re-used for another file. This is due to the fact that the LM80C DOS re-uses entries of deleted files when looking for a spot for a new file. So, it is recommended to perform this operation as soon as the file has been accidentally erased and, in any case, before writing back to the disk.

See also: ERASE, FILES, LOAD, SAVE.

### DOKE

Syntax: DOKE nnnn,val

Writes a word value (a 16-bit number) into a pair of contiguous memory cells. <nnnn> and <val> must be valid numerical values, in any supported format. The low byte of <val> will be written into location <nnnn> while the high byte of <val> will be written into location <nnnn>+1 (little-endian system). <nnnn> and <val> must be numerical expressions whose values must be into the range from 0 to 65.535.

Example:

DOKE &H8100,&HAABB => cell $8100 will contain $BB and

cell $8101 will contain $AA

See also DEEK.

### DRAW

Syntax: DRAW x1,y1,x2,y2[,color]

Draws a line starting from the point at coordinates <x1>,<y1> to the point at coordinates <x2>,<y2>. If <color> is specified, then the line will be drawn with that color, otherwise the foreground color will be used. <x1> and <x2> must be in the range from 0 to 255, while <y1> and <y2> must be in the range from 0 to 191. The origin of the coordinates (0,0) is set to the top-left corner while 255,191 is the bottom-right corner. Due to hardware limitations of the Video Display Processor (VDP), for every single byte of the memory screen (8x1 pixels) there can be only 1 primary color: if a line of one color intersects a line of another color, the pixels already present into the crossing byte will get the last color used. The direction of drawing is always from <x1>,<y1> to <x2>,<y2>, regardless the position on the screen of each pair of coordinates. <color> goes from 0 to 15: colors from 1 to 15 correspond to the system colors while 0 is a special value that instructs the BASIC to draw a line using the background color set with COLOR, i.e. to reset the pixels that are on.

Example:

DRAW0,0,255,191,7 => draw a diagonal line from top left to bottom right,

using the color "cyan"

See also: COLOR, for color codes and foreground/background colors.

### END

Syntax: END

Terminates the execution of a program. Any statement/s and/or program line/s following the END statement will be ignored and control will return to the editor. There is another instruction that halts the execution of the program, STOP: the difference is that the latter interrupts the code flow with a Break message (as if the RUN STOP key would have been pressed) while END behaves has the interpreter would have reached the last line of the program. Example:

10 A=1

20 PRINT A

30 END:A=A+1:REM THIS ADDITION WILL NEVER BE DONE

40 PRINT A:REM THIS LINE WILL NEVER BE EXECUTED, TOO

See also: STOP.

### EOF

Syntax: EOF(x)

EOF (End-Of-File) is a DOS function that returns a value depending of whether the end of a sequential file has been reached. <x> is the file number used with the OPEN statement to open a file for read/write operations. If <x> doesn’t match the file number currently opened, an error will be raised. The function returns 0 if the end of file has not been reached, 1 otherwise.

?EOF(1)

0

When <x> is set to 0, the function returns the size of the file currently opened:

?EOF(0)

510

The usage of this function is recommended in conjunction with the GET statement to avoid to read data over the end of the file and get an error:

10 OPEN "FILE",1,0

20 PRINT GET(1)

30 IF EOF(1)=0 THEN 20

40 CLOSE 1

See also: CLOSE, GET, OPEN, PUT.

### ERASE

Syntax: ERASE "filename"[,1]

Deletes a file. <filename> is the name of the file being deleted. If such file doesn’t exist into the directory, a File not found Error is returned. A confirmation is required to perform the action if the command is called in direct mode, while it isn’t if called by a program . If <1> is used as optional argument, then the DOS not only removes the entry from the directory but also erases (wipes out) the sectors that were used to store the data of files (secure deleting).

Example of file deleting with confirm:

ERASE "ADDEXAMPLE"

Delete file? (Y)

File deleted

Trying to delete a non-existing file:

ERASE "TEST"

Delete file? (Y)

File not found

Operation aborted by pressing a key different than Y:

ERASE "TEST1"

Delete file? (N)

Aborted

A little deepening on the erase process. ERASE operates in two different ways: a “quick erase” and a “full & secure erase”. When a file is being deleted, in realty it’s only marked as “deleted” unless a full erase is performed. The quick erase is done by setting the 8th bit (the most significant bit) of the first char of the file name: in this way, the user can make a try to recover it with DISK command (given the entry hasn’t been previously overwritten by another file). Data on its blocks will be left on disk until that space will be overwritten by saving another file. Instead, if a full erase is requested, not only the data will be wiped out but the entry in the directory will be entirely cleaned, avoiding any possibility of undeleting it.

See also: DISK, FILES, LOAD, SAVE.

### EXIST

Syntax: EXIST("filename")

This function returns 1 if the file named <filename> exists, 0 otherwise. <filename> must be an argument of type string.

Example:

?EXIST("MYPROG")

1

Note: this function can not be called when a sequential file is opened, since it uses the same buffers of other DOS statements.

See also: FILES.
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

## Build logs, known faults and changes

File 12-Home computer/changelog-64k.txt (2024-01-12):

---------------------------------------------------------------------------------------------

                                LM80C 64K - Changelog

---------------------------------------------------------------------------------------------

The following file reports the changelog of the firmware developed by Leonardo Miliani
for the LM80C 64K Color Computer. More info at www DOT leonardomiliani DOT com

P.S.: for the changelog of the LM80C Color Computer see the corresponding changelog file

---------------------------------------------------------------------------------------------
1.20    - 20240112

- Revised ERASE command: now, it recovers the original file name, by simply setting/unsetting
  the MSBit of the file name when deleting/undeleting the file.

---------------------------------------------------------------------------------------------
1.19    - 20210418

- New function EXIST() to check if a file is already present into the directory;
- introduction of GET(0) to roll back the internal pointer of a sequential file opened for
  reading;
- fixed a bug into the new keyboard shortcut CTRL+C=;
- fixed a bug into file undelete function.

---------------------------------------------------------------------------------------------
1.18    - 20210409

- New keyboard shortcut: when pressing "C=" (ALT) and "CTRL" keys together, the system resets
  the BASIC environment, clears the variables, clears the system stack, set the screen to
  graphic mode 1, re-initialize the PSG, close any seq. file still open, reset serial lines,
  and returns to the BASIC prompt; the program into memory is NOT deleted.

---------------------------------------------------------------------------------------------
1.17    - 20210408

- Fixed a bug into the code that [en|dis]ables the DOS code at boot: now the state being set
  is preserved over successive resets until a hard reset or a power-off takes place.

---------------------------------------------------------------------------------------------
1.16    - 20210327

- New DOS 1.05 with support for sequential files;
- new BASIC statements OPEN, CLOSE, PUT, GET, EOF to manage sequential files.

---------------------------------------------------------------------------------------------
1.15    - 20210319

- New boot mechanism to position DOS into the high-RAM of the system;
- when disabling the DOS at boot, this frees up the RAM it occupied, too.

---------------------------------------------------------------------------------------------
1.14    - 20210317

- Now LOAD & SAVE accept 4 arguments, to be able to load every sector in LBA mode;
- changed the behaviour of DISK command: new option "W" to rewrite the Master Sector.

---------------------------------------------------------------------------------------------
1.13    - 20210316

- SAVE now can be used to change the name to a file, too;
- disk access speeded up by using OTIR & INIR statements;
- code size optimization.

---------------------------------------------------------------------------------------------
1.12    - 20210310

- New LM80C DOS 1.02: code size optimization; new "undelete file" feature for DISK

---------------------------------------------------------------------------------------------
1.11    - 20210309

- New LM80C DOS 1.01;
- Better error managemenet for LM80C DOS routines;
- new behaviour of ERASE command (now in full erase, il also wipes out the file entry);
- code cleaning and optimization for LM80C DOS;
- code cleaning and optimization for some LM80C DOS commands.

---------------------------------------------------------------------------------------------
1.10    - 20210307

- New LM80C DOS 1.0 introduced, with new BASIC commands DISK, FILES, LOAD, SAVE, ERASE.
- New cold reset: by pressing the RUN/STOP key during the boot sequence, the computer
  restarts again and re-copy the firmware from ROM to RAM, to restore the original code
  and fix FW modifications made with POKEs w/o the need to power off the computer;

---------------------------------------------------------------------------------------------
1.05    - 20210119

- Better serial management with RTS-driven chars receiveing
- Fixed a bug introduced in the previous releases that lead to chars that disappearing 
  during text printing/scrolling

---------------------------------------------------------------------------------------------
1.04    - 20210105

- New behaviour for backspace (DEL) key: now chars that follow the cursor are moved 1 position
  to the left while deleting the char immediately before the current cursor position
- New behaviour for INSERT key: now it inserts a SPACE char (ASCII 32) so that the space 
  inserted is seen as part of the current line (in the past, the NULL char [ASCII 0] was used)

---------------------------------------------------------------------------------------------
1.03    - 20210104

- >> Important HW modification <<: MODE pin of VDP is now connected to A0, to simplify the
  coding for the video chip (just a "DEC reg" to change the VDP port)
- The change above also lead to a size reduction of the binary file
- Fixed again the cursor management routine so that the cursor is visible when being moved
- Changed the special key to disable the I/O DOS buffer, now it's CTRL
- Unified the source files between 32K and 64K versions thanks to the support for compiler's
  directives of the SJASMPlus assembler

---------------------------------------------------------------------------------------------
1.02    - 20201231

- Fixed a bug into the serial code: the incoming chars were print on screen even if the
  cursor was off (i.e., in indirect mode)

---------------------------------------------------------------------------------------------
1.01    - 20201231

- Code revision to comply with the assembler SJASMPLUS
- Moved equates for BASIC workspace area into a separated file

---------------------------------------------------------------------------------------------
1.00    - 20201229 - The 64K edition

- Hardware revision for memory expansion to 64K of RAM and bank switching mechanism to
  start in ROM, then switch to full 64K of RAM with copy of BASIC into the volatile memory
- Hardware revision to get the same bank switching mechanism for the VRAM to let the use
  of 2 portions of 16K each
- Serial buffer overrun revision
- Added key auto-repeat
- Added support for INSERT key to insert a space between text by moving the chars after the
  cursor position
- LIST now manage ending line number correctly, so that it won't list the line after the
  one passed as argument anymore
- BASIC support for serial channel B
- Code revision to comply with Z88DK assembler requirements
- Preliminary support for external mass storage (stubs for ERASE, FILES, LOAD, SAVE commands)
- Mechanism to enable/disable the 512-byte buffer for mass storage I/O operations (by
  pressing SHIFT while logo is shown on startup)

---------------------------------------------------------------------------------------------

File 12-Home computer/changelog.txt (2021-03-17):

---------------------------------------------------------------------------------------------

                                    LM80C - Changelog

---------------------------------------------------------------------------------------------

The following file reports the changelog of the LM80C firmware developed by Leonardo Miliani
for the LM80C Color Computer. More info at www DOT leonardomiliani DOT com

P.S.: for the changelog of the LM80C 64K Color Computer see the corresponding changelog file

---------------------------------------------------------------------------------------------
3.24    - 20210317

- Now LOAD & SAVE accept 4 arguments, to be able to load every sector in LBA mode;
- changed the behaviour of DISK command: new option "W" to rewrite the Master Sector.
---------------------------------------------------------------------------------------------
3.23    - 20210316

- New LM80C DOS 1.03;
- SAVE now can be used to change the name to a file, too;
- disk access speeded up by using OTIR & INIR statements;
- code size optimization.

---------------------------------------------------------------------------------------------
3.22    - 20210310

- New LM80C DOS 1.02: code size optimization; new "undelete file" feature for DISK

---------------------------------------------------------------------------------------------
3.21    - 20210309

- New LM80C DOS 1.01;
- Better error managemenet for LM80C DOS routines;
- new behaviour of ERASE command (now in full erase, il also wipes out the file entry);
- code cleaning and optimization for some LM80C DOS commands.

---------------------------------------------------------------------------------------------
3.20    - 20210307

- New cold reset: by pressing the RUN/STOP key during the boot sequence, the computer
  restarts again and re-copy the firmware from ROM to RAM, to restore the original code
  and fix FW modifications made with POKEs w/o the need to power off the computer;
- Added support for LM80C DOS 1.0 and new commands DISK, FILES, LOAD, SAVE, ERASE.

---------------------------------------------------------------------------------------------
3.19    - 20210119

- Better serial management with RTS-driven chars receiveing

---------------------------------------------------------------------------------------------
3.18    - 20210105

- New behaviour for backspace (DEL) key: now chars that follow the cursor are moved 1 position
  to the left while deleting the char immediately before the current cursor position
- New behaviour for INSERT key: now it inserts a SPACE char (ASCII 32) so that the space 
  inserted is seen as part of the current line (in the past, the NULL char [ASCII 0] was used)

---------------------------------------------------------------------------------------------
3.17    - 20210104

- Changed the special key to disable the I/O DOS buffer, now it's CTRL - AT THE MOMENT,
  DISABLED BY DEFAULT INTO CODE
- Unified the source files between 32K and 64K versions thanks to the support for compiler's
  directives of the SJASMPlus assembler

---------------------------------------------------------------------------------------------
3.16    - 20210101

- Code revision to comply with the assembler SJASMPLUS
- Moved equates for BASIC workspace area into a separated file
- Serial buffer overrun revision
- Fixed a bug into the serial code: the incoming chars were print on screen even if the
  cursor was off (i.e., in indirect mode)
- Added key auto-repeat
- Added support for INSERT key to insert a space between text by moving the chars after the
  cursor position
- LIST now manage ending line number correctly, so that it won't list the line after the
  one passed as argument anymore
- BASIC support for serial channel B
- Preliminary support for external mass storage (stubs for ERASE, FILES, LOAD, SAVE commands)
- Mechanism to enable/disable the 512-byte buffer for mass storage I/O operations (by
  pressing SHIFT while logo is shown on startup) - AT THE MOMENT, DISABLED BY DEFAULT INTO CODE

---------------------------------------------------------------------------------------------
3.15    - 20201121

- New title text;
- Added ELSE statement to expand IF..THEN evaluation instruction, to execute one or more
  statements if the condition is false;

---------------------------------------------------------------------------------------------
3.14    - 20201020

- New graphic command PAINT to fill connected areas of the screen with a specific color
- Now POINT returns the color of the pixel being tested

---------------------------------------------------------------------------------------------
3.13.8  - 20201001

- Fixed a little bug in COLOR statement: it didn't store the foreground color set by the
  user
- Now PLOT, CIRCLE, and DRAW statements accept color "0" to draw pixels with background
  color, i.e. reset pixels that are on
- Code cleaning

---------------------------------------------------------------------------------------------
3.13.7  - 20200911

- Fixed a bug into the new cursor management routine: now the cursor won't appear during
  PRINTing anymore
- Fixed a bug into the comma tabulation: now the max. allowed number of columns is 
  calculated dinamically, according to the screen width

---------------------------------------------------------------------------------------------
3.13.6  - 20200910

- Changed the cursor management routine: now the cursor is visible when being moved
- Now when the computer is software reset, the NMI is disabled before restart
- Tab printing with comma now reduced to 10 spaces

---------------------------------------------------------------------------------------------

3.13.5  - 20200829

- Minor code revisions into BASIC interpreter
- Fixed a bug into the comma-separated printing code that lead to wrong alignment of the text

---------------------------------------------------------------------------------------------
3.13.4  - 20200704

- Fixed a bug into the drawing line algorithm that crashed the system when there was a gap
  of 1 pixel between the starting and ending points;
- redefined chars 105,106, and 252 in 6x8

---------------------------------------------------------------------------------------------
3.13.3  - 20200613

- Fixed a bug with function keys that lead to get a syntax error or a non-function behaviour
  when pressed them while system was in direct mode and print-on-screen not active, i.e.
  in a graphics mode 2 & 3.

---------------------------------------------------------------------------------------------
3.13.2  - 20200611

- Revised code of GPRINT command to avoid an error that emerged when the statement was called
  with an arguments line too long.

---------------------------------------------------------------------------------------------
3.13.1  - 20200607

- Fixed a race condition that could lead the interrupt service routine access the PSG reg #7
  (mixer) together with some BASIC statements (i.e., SOUND), resulting in wrong values being
  stored into the mixer.

---------------------------------------------------------------------------------------------
3.13  - 20200530

- New style for "£" char;
- fixed a bug into the automatic shutting down manager of SOUND that didn't de-activate the
  audio channel into the PSG mixer after a tone had finished its period of reproduction;
- new INSTR statement, returning the position of the first occurrence of one string within
  another;
- changed the behavior of INKEY statement: now the minimum delay interval is set to 10
  hundredths of a second. If a shorter interval is being passed, it will be automatically
  set to 10 (this is because values under 10 could lead to faulty readings).

---------------------------------------------------------------------------------------------
3.12  - 20200523

- Fixed a severe bug originated by a wrong design error of the final PCB: ports A & B of the
  PSG were inverted into the schematic, same for the definition of the ports into the code.
- Fixed a bug into the SOUND statement that accepted the third argument when generating a
  noise, even the syntax shouldn't accept it.

---------------------------------------------------------------------------------------------
3.11  - 20200512

- Changed the way TMR() reads the real time counter so that now continue readings won't
  slow down the clock itself anymore;
- Changed the frequency of the keyboard reading. This task is now done every 1/50th of a second
  instead of each time the CTC channel 3 interrupt is raised: this lightens the "weight" of
  the interrupt service routine.

---------------------------------------------------------------------------------------------
3.10  - 20200508

- Added GPRINT command to print text and ASCII chars in screen 2 as they would in text modes;
- fixed a bug that lead to unpredictable behaviors when a line longer than 88 chars was
  received from the serial port: now the interpeter simply drops exceeding chars.

---------------------------------------------------------------------------------------------
3.9   - 20200502

- Added POINT function to get the status of a pixel in G2 mode (set or reset)
- Relocated CTC interrupt vectors to a jump table into RAM so that now the user can configure
  the CTC channel interrupts to jump to custom routines (included the routine attached to
  channel 3 that supervises several critical system routines);
- now SERIAL has default arguments for data, parity, and stop bits if not passed;
- changed FN key 5 function;

---------------------------------------------------------------------------------------------
3.8   - 20200430

- Fixed a bug in FN key codes that lead to the activation of the wrong FN keys;
- introduced support for NMI custom routines (suggested by nippur72) with NMI statement;
- fixed a bug that lead to un-wanted behaviors when graphic chars were parsed in direct mode;

---------------------------------------------------------------------------------------------
3.7   - 20200429

- Added HELP command to automatically list the line where a program error has occurred;
- added modulo operator '%' to make modulus operations between integers (returns the remainder
  of an integer division);
- added integer division operator '#' (return the integer part of a division);
- added support for function keys into firmware;
- added KEY command to manage function keys: it is now possible to print the current functions
  and assign new functions to the keys;
- revised PAUSE code: it is now possible to break the delay with the "RUN STOP" key;
- better error management when in graphic modes: now if an error occurs in G2 and G3
  modes, the BASIC interpreter returns into G1 mode; same behavior if an error occurs in
  direct mode while in graphic modes;
- pressing the "RUN STOP" key while in direct mode and in graphic modes leads the
  interpreter to return to G1 mode 

---------------------------------------------------------------------------------------------
3.6   - 20200419

- Minor improvement in LIST code (no more empty lines after a line that ends at the most right
  side of the video; listing a program from serial when the computer is in graphic 2 mode does
  not lead to a one-row-list anymore)
- fixed a bug in sound management (automatic cutting down of a sound wrongly altered the
  sound mixer);
- added management of noise by PSG;
- fixed some timing issues in VDP access that lead to graphic glitches in graphic mode 2;
- code improvements

---------------------------------------------------------------------------------------------
3.5   - 20200408

- Fixed a bug into the new code of LIST statement;
- serial & BASIC buffers expanded to 88 chars;
- fixed a little bug into editor (pressing RETURN over a multi-line text did not reposition
  the cursor after the end of it)

---------------------------------------------------------------------------------------------
3.4   - 20200329

- Removed POINT and SET statements and their legacies;
- changed default colors for screens 1 & 4;
- enhanced serial communication on port 1, fixed freezing bug and added new function to SERIAL
  statement;
- fixed TAB function

---------------------------------------------------------------------------------------------
3.3   - 20200315

- Code cleaning;
- improved LIST command

---------------------------------------------------------------------------------------------
3.2   - 20200309

- Added sprite size and sprite magnification settings to SCREEN statement;
- fixed a bug in warm/cold reset input routine

---------------------------------------------------------------------------------------------
3.1   - 20200304

- Added XOR statement;
- fixed a bug for SERIAL (chars sent over serial were $01);
- removed NULL statement;
- added compilation date & time into ROM file

---------------------------------------------------------------------------------------------
3.0   - 20200228

- Major changes to kernel, now the computer has a full-screen inline editor:
- it now acts as an old home computer of the '80s, getting statements from anywhere the cursor
  is;
- removed MONITOR statement;
- code cleaning & optimization;
- adopted usual hexadecimal & binary prefixes

---------------------------------------------------------------------------------------------
2.15  - 20200225

- Now the computer starts as a stand-alone system, with serial disabled;
- new SERIAL command

---------------------------------------------------------------------------------------------
2.14  - 20200203

- Better CLS code (no more color flashes in graphics modes);
- added SYS command

---------------------------------------------------------------------------------------------
2.13  - 20200127

- Implemented ALT & CTRL keys to print graphic chars with keyboard;
- code improvements;
- faster cursor flashing

---------------------------------------------------------------------------------------------
2.12  - 20200124

- Code optimizing;
- fixed a bug into the CIRCLE routine;
- new splash screen with a graphic logo

---------------------------------------------------------------------------------------------
2.11  - 20200110

- Set graphics 2 VRAM in a better way;
- fixed TAB() function;
- new SCREEN 4 mode;
- new PLOT, DRAW, and CIRCLE commands

---------------------------------------------------------------------------------------------
2.10  - 20191226

- SIO init code cleaning & improved support for serial RX;
- added extended char codes (128-255) for 6x8 fonts;
- removed double chars in 8x8 fonts

---------------------------------------------------------------------------------------------
2.9   - 20191222

- Code cleaning;
- improved SOUND statement;
- revision of PSG code;
- revision of release notes;
- add support for cursor keys & cursor movements

---------------------------------------------------------------------------------------------
2.8.2 - 20191215

- Fixed a bug introduced with 2.8 that lead to wrong functioning of several BASIC statements
  (system tick counter, Locate, etc..)

---------------------------------------------------------------------------------------------
2.8.1 - 20191208

- Introduced support for SHIFT key for uppercase letters & alternate chars

---------------------------------------------------------------------------------------------
2.8   - 20191207

- Minor bug fixes;
- added support for built-in keyboard;
- revision of some char codes;

---------------------------------------------------------------------------------------------
2.7   - 20191116

- Fixed a bug into the INKEY code

---------------------------------------------------------------------------------------------
2.6   - 20191102

- New function INKEY to read a key without a prompt;
- source code cleaning

---------------------------------------------------------------------------------------------
2.5   - 20191026
- Revision of init PSG code;
- revision of serial buffer exp. code;
- fixed a bug into the video buffer manager

---------------------------------------------------------------------------------------------
2.4a  - 20191015

- More graphic chars

---------------------------------------------------------------------------------------------
2.4   - 20191013

- Added new graphic chars and reorganized previous ones

---------------------------------------------------------------------------------------------
2.3   - 20190930

- Fixed bugs in SOUND command

---------------------------------------------------------------------------------------------
2.2   - 20190920

- Fixed cursor bug within SCREEN statement;
- new command PAUSE

---------------------------------------------------------------------------------------------
2.1a  - 20190908

- Cursor management improvements

---------------------------------------------------------------------------------------------
2.1   - 20190818

- Added SOUND command to play simple tones and VOLUME command

---------------------------------------------------------------------------------------------
2.0   - 20190714

- Added SREG & SSTAT to write to/read from PSG

---------------------------------------------------------------------------------------------
1.9   - 20190620

- Added functions to read/write VDP registers
- Aligned release numbering of module files with firmware version
- Default string space set to 100 bytes
- Added VREG, VSTAT, & LOCATE statements;
- 8x8 fonts completed

---------------------------------------------------------------------------------------------
1.8   - 20190615

- Better cursor integration;
- added VPOKE & VPEEK statements;
- 6x8 & 8x8 fonts

---------------------------------------------------------------------------------------------
1.7   - 20190606

- Show the computer name only at powerup
- Removed messages about wrong HW systems
- Added SCREEN command to change video mode

---------------------------------------------------------------------------------------------
1.6   - 20190601

- Fixed scrolling bugs
- Cursor management integrated into VDP module

---------------------------------------------------------------------------------------------
1.5   - 20190525

- Added backspace functionality
- Initial video management

---------------------------------------------------------------------------------------------
1.4   - 20190524

- Added scrolling capabilities

---------------------------------------------------------------------------------------------
1.3   - 20190521

- Video cursor management - preliminary

---------------------------------------------------------------------------------------------
1.2   - 20190515

---------------------------------------------------------------------------------------------
1.1   - 20190512

---------------------------------------------------------------------------------------------
1.0   - 20190511

- First firmware version

---------------------------------------------------------------------------------------------

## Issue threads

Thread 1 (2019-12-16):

The keyboard

Techokami, 2019-12-16:
This is an interesting project! My only concern is the keyboard module choice. While there were Commodore 16 keyboard modules sold via surplus back in the 80s and 90s, that was... back in the 80s and 90s, and the store that sold them is no longer around (RIP Radio Shack), so getting these modules is very unreliable and can get expensive on eBay. From what I've seen, it's just a matrix of switches, but it would be really nice to have the connector and the matrix documented in this repository, so that someone could develop a keyboard module with modern parts for it...

leomil72, 2019-12-22:
Hello. Since this is a sort of replica of an old 8-bit computer I've tried to used components of that era, like the keyboard. You could try some auction sites around the web, it wouldn't be difficult to find a non working computer from which cannibalize some parts, like the keyboard, for a modest amount of money. Or, if you're lucky, just the keyboard, as I got it.
BTW your suggestion is valid and I will add the keys' matrix so that anyone will be able to do a keyboard module.

Closed 2019-12-22.

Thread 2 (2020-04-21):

character tile crossover in screen 0

nippur72, 2020-04-21:
when in `SCREEN 0` sometimes the characters cross over to the adjacent tile, clearing a row or two of vertical pixels. The bug is evident if you go around with the cursor over a LISTing.

See the attached image:
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

nippur72, 2020-04-21:
this is an emulator issue, closing.

Closed 2020-04-21.

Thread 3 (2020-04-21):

how to read/write from serial in BASIC

nippur72, 2020-04-21:
once you open the `SERIAL` line communication, how do you send/receive data in BASIC ?

leomil72, 2020-04-23:
Despite the SIO supports 2 serial ports, at the moment only port A is supported by the kernel and configured to work as a stream device. In fact, it's been thinked to work with a terminal emulator running on a remote computer, and, when opened, it just sends chars being printed on video to the remote device and prints on video chars that are input on the terminal emulator. In a future release kernel will support port B, too, to act as a block device to exchange data with a mass storage device

Closed 2020-04-23.

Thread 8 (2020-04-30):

RUN STOP doesn't stop a program

nippur72, 2020-04-30:
the `RUN STOP` key doesn't stop a running BASIC program (but `ESC` does it).

It would be nice if you also supported `SHIFT` + `RUN STOP` for "RUN", moving it out of KEY #2.

leomil72, 2020-04-30:
Is it `RUN STOP` key or are you using the `CTRL+C` shortcut?
Because in the real machine, it does stop the program.

leomil72, 2020-04-30:
> It would be nice if you also supported `SHIFT` + `RUN STOP` for "RUN", moving it out of KEY #2.

It was a decision of my own: I prefer to look at that key as "RUN STOP" instead of "RUN/STOP", meaning that I just needed a key to halt the program. And it's like on the real C16, where "RUN" was also present between the FN keys.

nippur72, 2020-04-30:
ok, it was an emulator bug--actually a bug in the browser: I had mapped `RUN STOP` to `Pause` but on Chrome the event for keypress up is fired just after the "down" not giving time to the firmware to catch it. Remapped it to `Tab`.

leomil72, 2020-04-30:
Since I have no memory about the use of SHIFT+RUN/STOP to run a program on my C16, I checked the user's manual and found confirms of this. In fact, on the C16 the SHIFT+RUN/STOP shortcut loaded and ran the first program found on a disk inside the disk drive but since I never had this device I never used this shortcut :-)
I think it's a C64 legacy...

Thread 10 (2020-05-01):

daisy chain priority

nippur72, 2020-05-01:
I can't find any reference on the docs about the daisy chain interrupt priority. From the schematics I deduced `SIO` has the highest priority, then `CTC`, and lastly `PIO`. Is that so (or it's reversed?)

leomil72, 2020-05-01:
The priority is hard-wired. The periphery chip that has its IEI pin connected to +5V is the highest one, then CTC, then PIO, as you pointed out. I decided so because IMHO incoming data through serial must be served as soon as they are available. Then CTC, because it's the system tick counter. Theh the PIO, because at the moment it isn't very useful... just used to turn on some LEDs. I will add some reference in future releases of the docs.

Closed 2020-05-02.

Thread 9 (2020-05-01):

NMI interrupt can't use VDP ?

nippur72, 2020-05-01:
I finally managed to write a program that uses the NMI interrupt with the new firmware. I discovered the hard way that the VDP needs to be acknowledged of the end of the interrupt by the read of the status register; otherwise it won't trigger another interrupt.

Below you'll find the program I wrote, could you please execute it on the real LM80C and send me back a picture of the screen? I need it to verify the accuracy of the emulator.

Anyway there seems to be a big issue with the NMI in general. When I run the above program and scroll the video (e.g. `LIST`), the screen gets scrambled and after a while the LM80C behaves erratically.

I suspect this is due to the NMI interrupting just when the firmware is accessing the VDP; it doesn't matter that all the VDP ops are enclosed in `DI` and `EI`, it's a NMI and you can't stop it. Is that correct?

I tried to remove all VDP writes in the routine (except of course the INT ACK) and indeed it does work normally. So I deduce this means that only one routine can use the VDP: the NMI routine or the outside-NMI.

In this scenario I think that the NMI hook is still useful for games when an hypothetical game loop is all within the NMI routine.  For raster tricks, the NMI could be used as a reference for CTC and make all video updates in the CTC-triggered interrupt which is maskable.

What are your comments?

```
10 FOR T=&H9000 TO &H9037
20 READ B:POKE T,B
30 NEXT
40 SYS &H9000
50 END
1000 DATA 17,6,144,195,23,38,245,213
1010 DATA 229,30,246,62,7,205,19,6
1020 DATA 33,218,2,205,50,144,30,247
1030 DATA 62,7,205,19,6,33,0,5
1040 DATA 205,50,144,30,244,62,7,205
1050 DATA 19,6,205,30,6,225,209,241
1060 DATA 237,69,43,125,180,32,251,201
```

the source:
```
org $9000
INSTALL:
   LD DE, MYROUTINE
   JP $2617   ; NMI basic command

MYROUTINE:
   push af
   push de
   push hl

   ld   e, $F6
   ld   a, $07
   call WRITE_VREG

   ld   hl, $02da
   call wait

   ld   e, $F7
   ld   a, $07
   call WRITE_VREG

   ld   hl, $0500
   call wait

   ld   e, $F4
   ld   a, $07
   call WRITE_VREG

   call READ_VSTAT         ; ACK NMI by reading the VDP status register

   pop hl
   pop de
   pop af

   RETN

wait:
   dec  hl
   ld   a, l
   or   h
   jr   nz, wait
   ret
```

and what you should see:
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

leomil72, 2020-05-01:
Attached the required screenshot.
Let me say that:
1) there are more glitches than in yours, because the real TMS has very mandatory timings to access data that is to/from VRAM so it goes crazy very easily; system is responding very slowly, when I type some RETURNs the screen start going mad. BTW, the interpreter is still responding since I see correct messages from the BASIC over the serial port. If I give a NMI 0 to detouch the NMI, everything returns normal.
2) you're right when you say that NMI is not practical as you thinked about it because TMS is very particular in its way of communicating with the CPU. So, It needs that the double-byte transfer of the command must be done with no breaks: if, after the firts OUT, another operation is sent to the VDP, it losts the point of the previous one that was doing. So, when you point at the fact that during a READ/WRITE, even if operations are between EI/DI, something weird ahppens, you got the problem. LM80C has been developed in a way that didn't use the NMI signal to do its stuff beause I chose to use IM2, to be able to manage INTs from the peripheral chips in an easy way. The only way to change everything is to... change everything and write the interrupt service routine from scratch, a way I don't even want to keep in consideration...
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

nippur72, 2020-05-01:
Ok, thank you for the test image, I checked again the numbers and now I'm able to get a very similar picture as yours.

The actual numbers are:
VDP clock: 10,700,000 Hz (as per your schematic)
Number of dot pixel per image: 342 x 262 x 2 (as per TMS data sheet)
Resulting refresh rate: 59.7071559305 Hz
CPU speed = 7,700,000 / 2 = 3,685,000 Hz (as per your schematic)
CPU clock cycles per line = 235.5644859

Regarding the CPU clock, you once mentioned it to be 3686400, not 3685000, which number is correct?

The aligned image compared with your:
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

I'm also able to get the same glitches as you, which means that the emulation is pretty good :smile:
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

My thought on the NMI is that it can be useful under certain circumstances, we have just to keep in mind the VDP limitation. Perhaps I wouldn't keep the dedicated `NMI` BASIC command, but since it's already there...

A simple useful NMI routine is to have a counter that increments at every interrupt. A game loop then keeps watching the counter until it changes:
```
NMIROUTINE:
   PUSH HL
   LD HL, counter
   INC (HL)
   POP HL
   CALL READ_VSTAT
   RETN

GAME_LOOP:
   ....
   LD HL, counter
   LD A, (HL)
WAIT:
   XOR (HL)
   JR Z, WAIT
   ; screen updates here
   JP GAME_LOOP
```

leomil72, 2020-05-01:
The fact that the TMS emulator your're using is good is by far not in doubt! :-)
>A simple useful NMI routine is to have a counter that increments at every interrupt. A game loop then keeps watching the counter until it changes:

Keep in mind that this is already done by the sys tick counter: registers of TMR are incremented every 1/100th of a sec.

>Regarding the CPU clock, you once mentioned it to be 3686400, not 3685000, which number is correct?

The first one. I used a 7,372,800 Hz crystal, whose frequency is halved to 3,686,400 and used as system clock. Then this clock is halved again to get 1,843,200 Hz that is used as serial clock (and to clock the PSG sound chip, too).

As for the TMS, its clock is 10,738,635 Hz. This value is very mandatory, and referred into the VDP data sheet (because this value is 3 times the color burst clock  of an NTSC signal, 3.579545 MHz), with a very little tolerance.

Forget the roundings in the schematics and please give these values a try.

nippur72, 2020-05-01:
thanks for the correct numbers, the image didn't change much as the error is within a scanline or so.

>
> Keep in mind that this is already done by the sys tick counter: registers of TMR are incremented every 1/100th of a sec.
>

yes of course but the whole point here is to wait where the raster is off-screen to avoid flicker and tearing. A smiliar thing is done in VIC20/C64, you wait til the bottom of the screen by watching the raster line register of the VIC chip. Here we don't have the exact line, but what matters is to know easily when the screen is at the bottom. Hopefully in the future we'll write some game that exploits all that.

Closed 2020-05-02.

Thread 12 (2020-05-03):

implement SAVE and LOAD

nippur72, 2020-05-03:
currently the only way of loading programs is via terminal emulation over serial, this means you can't load or save true binary files, or even BASIC programs in its native tokenized form.

My proposal is to have the commands `SAVE` and `LOAD` to transfer programs over the existing serial line. The protocol could be like as this:
- sync byte (repeated n times)
- 4 bytes header
- 1 byte type of file (binary at fixed address or basic relocatable)
- filename + 0x00
- (word) number of bytes
- (word) address
- actual bytes
- (word) checksum

(note: the `LOAD` command have to set the `PROGND` pointer at the end of the loading).

If slower baudrates are allowed (e.g. 2400), it would be possible to SAVE and LOAD from a cassette tape (or any other audio source) like a real home computer of the '80s 😄. (In such case the header bytes at the start are mandatory to throw away the random characters).

leomil72, 2020-05-03:
The PCB I realized is a little bit different from the online schematics and it has an Atmega328 on the second serial line of the SIO that should act as a driver to read from/write to a micro SD. I chose this way since this isn't really a break of my proposal to not use components out of the Z80 family. In fact in the past many drives or other peripherals had their own CPU/OS on the device that got commands from the CPU and talked with the device

leomil72, 2020-05-03:
PS: I surely wanted to replicate an 8 bit system of the 80s but I also wanted to build something that could be usable with contemporary technology. Today analog music tapes are out of the market for a long time now, SD cards are widely available so I opted for them. Moreover I fly!d use the PIO to access the SD card but I realized that it would have been a very hard task, so I decided for another approach

nippur72, 2020-05-04:
curious to see what is the other approach. I have limited experience with SD cards so can't help much, sorry.

P.S. in case you need to to actually transfer binary files, the emulator has a function named `make_lm()` that automatically creates a BASIC program with DATA for you :-)

From the JavaScript console (F12):
```
> make_lm(0xA000,0xA00F)

10 FOR T=&Ha000 TO &Ha00f
20 READ B:POKE T,B
30 NEXT
40 SYS &Ha000
50 END
1000 DATA 0,0,0,0,0,0,0,0
1010 DATA 0,0,0,0,0,0,0,0
```

Closed 2020-05-04.

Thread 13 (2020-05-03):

implement printing in screen 2

nippur72, 2020-05-03:
BASIC should be able to print in `screen 2` mode, allowing to change foreground and background colors on per-character basis. This way programs could me more "colorful" without the limitations imposed by `screen 1`.

Best would be have the BASIC prompt in `screen 2` and allow full editing, in other words treating `screen 2` like a text mode (perhaps this could be the only text mode supported by the firmware--the others are not very useful).

Advantages:
- more colors!
- reverse characters possible (by inverting colors)
- cursor blinking with reverse or other effect (e.g. a colorful cursor)

Disvantages:
- needs to keep a separate buffer for screen map and color map 40 x 24 x 2 (could these buffers be placed in VRAM ?)
- slow to scroll and to print to

The Amstrad CPC does it this way: it has the prompt and the editing in graphic mode and has a non-blinking reversed cursor.

nippur72, 2020-05-03:
I wrote the assembly subroutine for printing a single character in `screen 2` mode. But I don't know how to connect it to the rest of the firmware.

If you want to merge it it's [here](https://github.com/nippur72/lm80c-emu/blob/master/software/screen2_putc/screen2_putc.asm), it's 62 bytes long.

Hello world:
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

Screen filled
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

leomil72, 2020-05-03:
Good improvement but... a text mode is a text mode and the LM80C was built over the TMS9918 with its limits and its disadvantages. In fact, each home computer of the 80s had its own hardware and acted in a different way. So did the ZX Spectrum, so did my C16 and so did the C64 and the MSX.
My C16 had a command to write characters on a graphic mode but it was just to add some text to a graphic, not just to use the graphics mode as a text screen. Consider that in screen 0, 1, or 4 you just use a single tile to print a char while in screen 2  your system should plot 64 pixels for each char. Not considering the buffers: 960 bytes for the chars and 960 bytes for the colors: I really don't know without looking at the data sheet if I could find 2 kb of empty space in Vram when in G2 but I don't think so.

BTW I can implement a sort of CHAR command to print in G2 , this could be useful for splash screens, static images or program-driven screens, but it could never become the default text mode , actually

nippur72, 2020-05-04:
yes a `CHAR` or `GPRINT` or something similar would be enough to let BASIC programs make use of screen 2. Or perhaps one could just use `SYS` to call a machine language routine as I did. On the Commodores the `SYS` command allowed to pass extra parameters -- not thanks to `SYS` itself, but calling the BASIC parser at the start of ML routine. I wonder if the same trick works on the LM80C as well.

leomil72, 2020-05-04:
I prefer a specific BASIC command instead of calling a ML routine since if the user is using the BASIC interpreter then this means that he/she isn't so skilled to work with LM.
Actually, SYS can get an argument and pass it to the called ML routine into the accumulator (reg. A).

leomil72, 2020-05-06:
It'll be implemented in next R3.10

nippur72, 2020-05-06:
talking of screen modes, can we have `SCREEN 4` as the default/boot mode instead of 1? My understanding is that there are no differences except that in `SCREEN 4` you can set the colors on a tile basis instead of group of tiles.

leomil72, 2020-05-06:
I added G4 after a lot of development in which G1 was the boot mode so at the moment this still continue to be the default mode.

PS: G4 has some little differences with G1. It has less sprites (8 instead of 32),it supports color on tile basis but if you change the color of a tile this change will be reflected to all the same tiles on the screen, because it isn't a real multicolor mode.

Closed 2020-05-08.

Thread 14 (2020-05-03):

emulate CAPS LOCK

nippur72, 2020-05-03:
sometimes BASIC programs require you to input uppercase letters but the LM80C is lowercase by default. Since the `SHIFT LOCK` in the C16 keyboard doesn't work as a true CAPS LOCK I suggest to implement a caps lock state in the firmware.

A simple bit that is toggled by some key combination, e.g. `CTRL`+`SHIFT` or `C=`+`SHIFT`.

leomil72, 2020-05-03:
Since the LM80C Basic didn't discriminate between loser and upper case, I didn't need a real caps lock. Your suggestion isn't bad. I will keep it into account in a future release

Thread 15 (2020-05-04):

question about timing the TMS9918

nippur72, 2020-05-04:
I have a question about the access timings for the VDP. I noticed in your firmware code you put three `NOP`s between VDP accesses. But checking the TMS9918 manual (see below) it talks about a 8μs delay which would be 8 nops.

I derived the number from this calculation:
- Z80 clock period is 1/3.6864 ≈ 0.271 μs
-  8μs / 0.271 ≈ 30 Z80 clock cycles.
- in `NOP` terms, 30 / 4 ≈ 8 nops

Since your code actually works, what am I missing ? :smile: It would be nice to emulate such strict timings in order to check if a program can run on a real LM80C.

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

leomil72, 2020-05-04:
I think you're missing the time required by the CPU to execute the rest of the instructions.
Let me explain you. Let us consider the "READ_VIDEO_LOC" sub into VDP.ASM. If you look at the code you see:
`                out     (C),L           ; low byte then...`
`                out     (C),B           ; high byte`
`                ld      C,VDP_DAT       ; VDP data mode`
`                nop                     ; wait...`
`                nop                     ; ...a while`
`                nop`
`                in      A,(C)           ; read byte at current VRAM location`
The count start after the execution of the second OUT instruction.
Then there are:
LD C + NOP + NOP + NOP + IN
7+4+4+4+12 = 31 T states
Yes, IN shouldn't be considered in its entirety since only in its first part (M1 cycle and maybe a part of M2) the CPU is setting up the address on the address bus and sending the signals to the VDP. BTW, this seems to be enough for the VDP.

nippur72, 2020-05-04:
oh great explanation, thanks! It makes sense now. 👍

Closed 2020-05-04.

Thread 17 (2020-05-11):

TMRCNT timer accuracy

nippur72, 2020-05-11:
I spent the whole morning debugging why `0 PRINT TMR(0)/100:GOTO 0` was not counting seconds as it was supposed to do. I checked almost everything in the emulator -- only many hours later I realized that the act of calling `TMR(0)` does affects the counting itself! That's because of the `DI` and `EI` instructions used in the `TMR` routine. So if you call it repeatedly, counting slows down considerably. Scrolling the video also slows it to a certain extent, I guess for the same reason (VDP accesses are in `DI` mode).

I don't think much can be done to fix this issue, perhaps the only thing would be reducing the 100Hz frequency of the CH3 timer, in order to mitigate the chance of missed increments. With prescaler set to `256` the next good value would be 60 Hz (constant value 240).

leomil72, 2020-05-11:
I introduced EI/DI instructions to atomize the reading of the timer registers, avoiding a race condition (both the interrupt and the user are accessing the same memory cells).
It is not intended to be read repeatedely or for long periods. 100 hz have been chosen to simplify counting, I dislike 50/60 Hz interrupts from old PAL/NTSC video chip interrupts.
Maybe there could be a way to get around the problem: I could change the code and change the double reading of two single bytes from RAM into a single reading of a word from RAM (i.e. LD HL,(nnnn)). In fact, the interrupt is acknowledged and managed at the end of any instruction

nippur72, 2020-05-11:
I agree 60 is an ugly number (unless you are an ancient babilonian 🤣).

When the cursor is idle (no input etc), I counted an average of 2320 T-states starting from the CTC interrupt request to the `RETI` instruction. That means the interrupt routine takes 6.29 % of the total CPU time (2320 x 100 / 3686400). At 60 Hz it would be 3.77% -- a little advantage of lowering the frequency.

BTW, looking at the CTC, I was surprised to discover it can only count up to 256. Or is there a way to make it count for longer periods?

leomil72, 2020-05-11:
> That means the interrupt routine takes 6.29 % of the total CPU time (2320 x 100 / 3686400). At 60 Hz it would be 3.77% -- a little advantage of lowering the frequency.

The heavier portion of code is the keyboard management, I think. I could reduce this % by simply doing a keyboard reading every 2 interrupt calls, getting a 50 Hz frequency without altering the time counting.

> BTW, looking at the CTC, I was surprised to discover it can only count up to 256. Or is there a way to make it count for longer periods?

Because it only has 8-bit registers, the only way is to play with prescalers and time constants (the values reloaded automatically when registers reach 0).

leomil72, 2020-05-11:
Or maybe you could try to daisy-chain the interrupt output pin of a timer with the input pin of a counter. So when the first one reaches zero it raises an interrupt, mirrored on the external pin: this signal will be counted by the counter and, when reached the desired value, this one in turn will raise an interrupt for the CPU. I don't see any other ways without using additional external components.

leomil72, 2020-05-11:
> >  That means the interrupt routine takes 6.29 % of the total CPU time (2320 x 100 / 3686400). At 60 Hz it would be 3.77% -- a little advantage of lowering the frequency.

> The heavier portion of code is the keyboard management, I think. I could reduce this % by simply doing a keyboard reading every 2 interrupt calls, getting a 50 Hz frequency without altering the time counting.

Ok, I did it. A simple check on bit#0 of the lowest byte of the 32-bit system timer at each interrupt call: the keyboard reading is done only if such bit is 0, meaning every 2 interrupt calls (50 Hz).

Closed 2020-05-11.

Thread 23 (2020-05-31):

sound generator occasionally not turned off in BRISCOLA

nippur72, 2020-05-31:
When playing `biscola.bas`, occasionally the sound generator is not turned off (in the emulator you can hear an high-pitched continuous tone that you won't hear on the real machine). The issue manifests once in two or three complete briscola matches.

As the issue occurs and the game goes on, I still can hear the "card shuffle" sound, but after it the voice is never turned off (which is very odd).

I stopped the program and dumped the state of the sound chip, you can see bit 0 of reg7 is 0 instead of 1:
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

Does this gives you a clue?

leomil72, 2020-05-31:
Is it related to the latest firmware releases, after the SOUND statement fixes, or was it already present before? I mean, could it be related to the latest changes in the SOUND management mods?

nippur72, 2020-05-31:
past firmware was buggy, the voices were always turned on, so I can't tell.

leomil72, 2020-05-31:
Wait a moment. Noise mixing is controlled by bits 3~5. Bits 0~2 set the normal analog channels.
So if you get 190 means that you had the channel 1 on, and SOUND 4 doesn't alter such bit.
There's something else earlier. For some reason you had the analog channel #1 on into the mixer. Did you play with SOUND before to execute the game?
PS: I tried several times doing SOUND4,30:PAUSE1:SOUND4,0 and always get 191 from reg #7

nippur72, 2020-05-31:
No, I didn't have any sound running before, I'm just starting fresh with a new instance of the emulator.

I am also unable to replicate the issue by running `SOUND4,30:PAUSE1:SOUND4,0` several times. It happens only in `briscola.bas`, I don't know why.

I've put a watchpoint at the address `0x2989` (sound routine below `NOS3` label) printing the `A` register.  Normally I get the values `183` and `191`, but when the issue occurs get in sequence:
```
a=246
a=254
a=182
a=190
a=182
a=190
a=182
a=190
(last two values repeated for the rest of the game)
```

Could it be that the interrupt keyboard routine is interfering with the read of register 7? E.g. interrupt occurring just in between the selection of reg 7 and the actual `IN A, (C)`. I'm guessing.

nippur72, 2020-05-31:
the debug code to paste in the JavaScript console is the following:
```js
   debugBefore = ()=>  {
      let state = cpu.getState();
      if(state.pc == 0x2982 && (state.a != 191 && state.a !=183)) console.log(`a=${state.a}`);
   }
```

leomil72, 2020-05-31:
There could be a race condition between the interrupt service routine and the SOUND code.
But this is strange since the keyboard routine happens with or without a program is running...
Moreover, I don't understand it's happening only in that game.
To be honest, I played Briscola several times on the real machine but never noticed this issue.

I could try to atomize the SOUND code in the part that reads & sets the PSG disabling interrupts before such point.

leomil72, 2020-06-02:
I played several games of Briscola and never experienced such issue. Unless more detailed info to replicate it on the real machine, I classify it as an emulator bug and, at the moment, close this issue.

nippur72, 2020-06-02:
I am now able to replicate it. If you run the following program, the value `183` will be printed once in a while.

```basic
10 volume 1,15
20 sound 4,10:sound 4,0
30 if sstat(7)<>191 then print sstat(7)
40 goto 20
```
I guess it's the keyboard interrupt routine, because if I decrease the `$90` CTC constant (at `0x031c`) the issue occurs more frequently.

leomil72, 2020-06-02:
I must apologize. You were right. When the firmware is executing the CH3 interrupt service routine, during the keyboard reading the code loads adn save the reg #7 (the mixer) for setting the keyboard lines for proper input/output states, in case the user would have "played" with regs #14 & #15. If the interrupt service routine is calling while the BASIC is executing the SOUND statement, with leads to unwanted behaviors since there is a real race condition between to points of the firmware that are accessing the same PSG register.
To solve it, I atomized the portions of code of the BASIC interpreter that could access the PSG registers (SOUND and SSTAT/SREG), and now I only get 191 when executing the test program above.

Closed 2020-06-07.

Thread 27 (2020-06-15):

set cursor ON after keystroke

nippur72, 2020-06-15:
When you navigate with the cursor keys across the screen, the cursor "vanishes" due to flashing; this makes it difficult to locate where the cursor is landing.

I suggest to set the cursor to "ON" just after a key has been typed (C64 and others does it this way).

I tried to implement this feature myself but I found it difficult due to flashing based on timer rather than a counter.

leomil72, 2020-06-16:
I discarded the usage of a separate counter for the cursor flashing because the interrupt routine is already doing a lot of stuff and it was easier to use a check on the system tick counter instead of overloading it with something more to do.
I agree that a flashing cursor while you're moving it isnt the best thing to see but it's simpler than other systems. Moreover, if you just set the cursor to ON after a key is being pressed, this does not mean that you'll have the cursor on for a long time since you could have pressed the key while the change of cursor status was about to happen.

nippur72, 2020-09-11:
closing as it improved with v3.13.6

Closed 2020-09-11.

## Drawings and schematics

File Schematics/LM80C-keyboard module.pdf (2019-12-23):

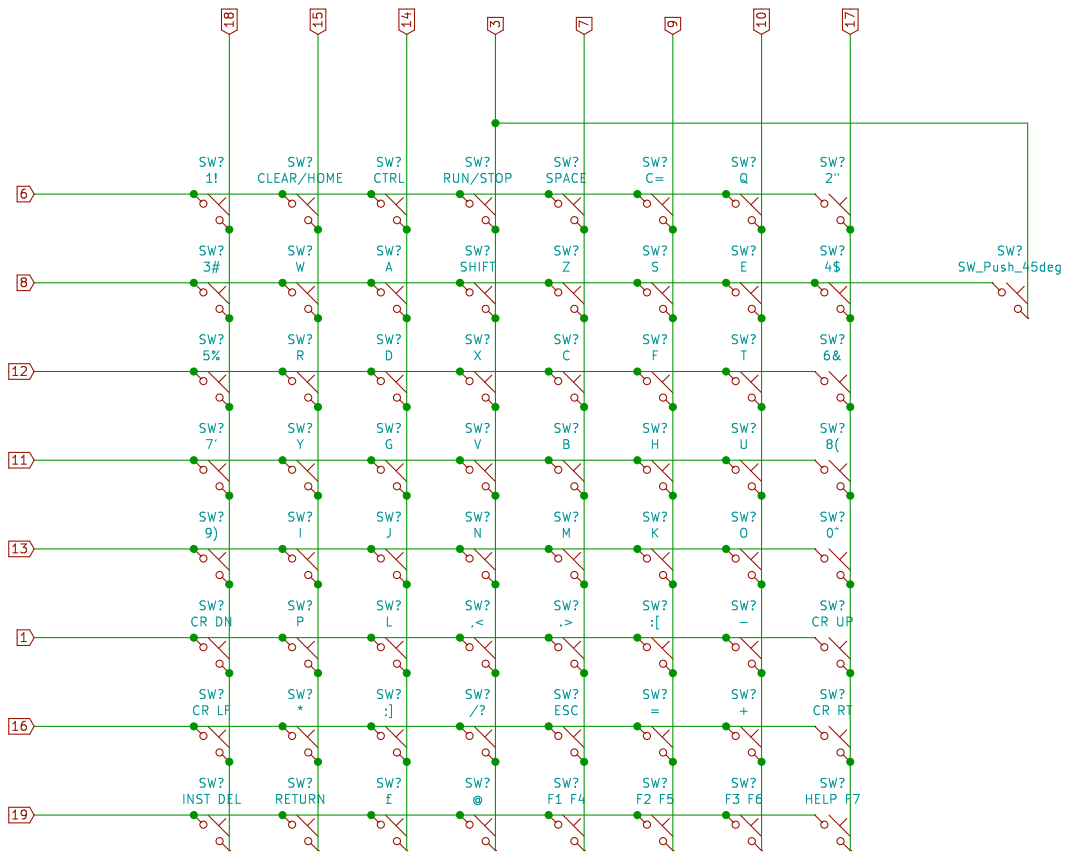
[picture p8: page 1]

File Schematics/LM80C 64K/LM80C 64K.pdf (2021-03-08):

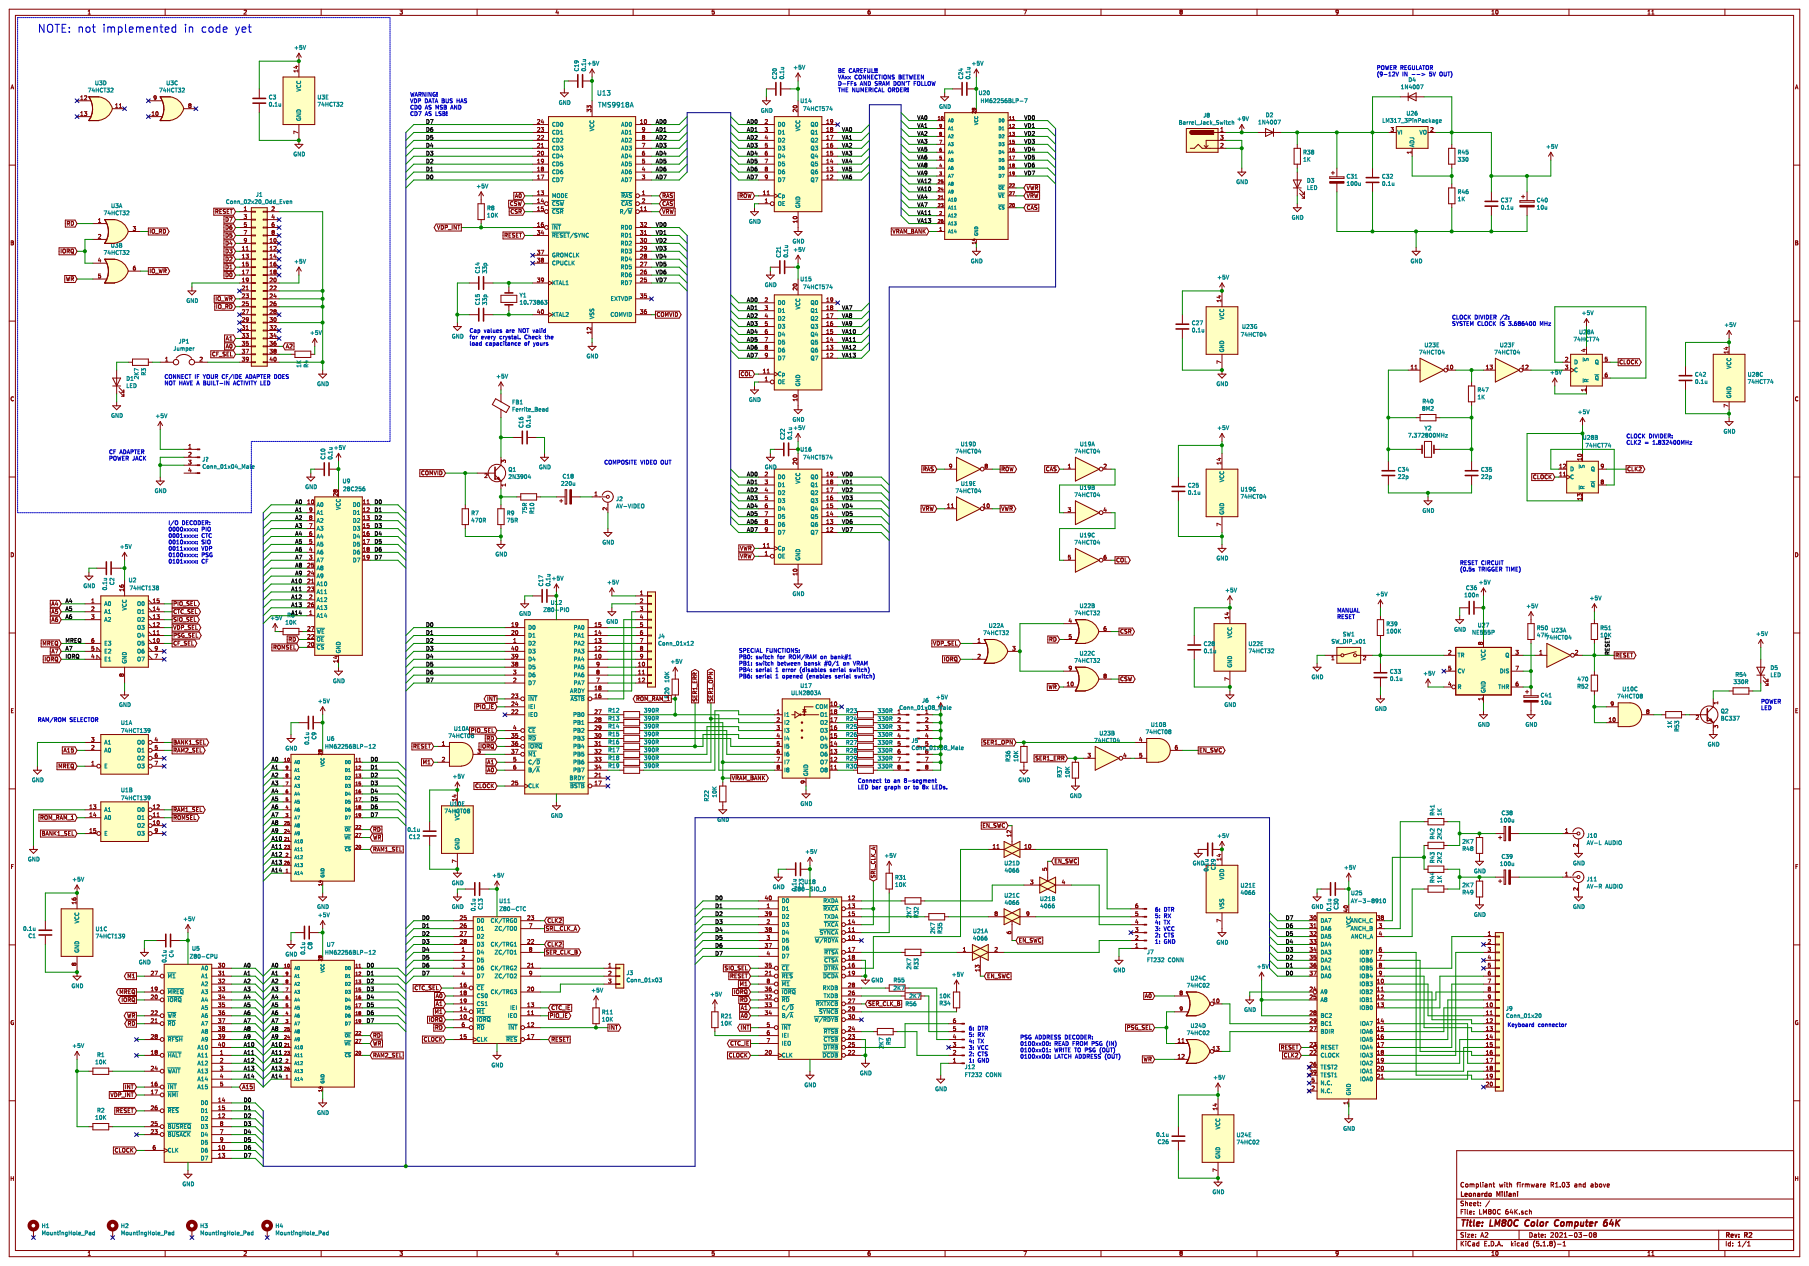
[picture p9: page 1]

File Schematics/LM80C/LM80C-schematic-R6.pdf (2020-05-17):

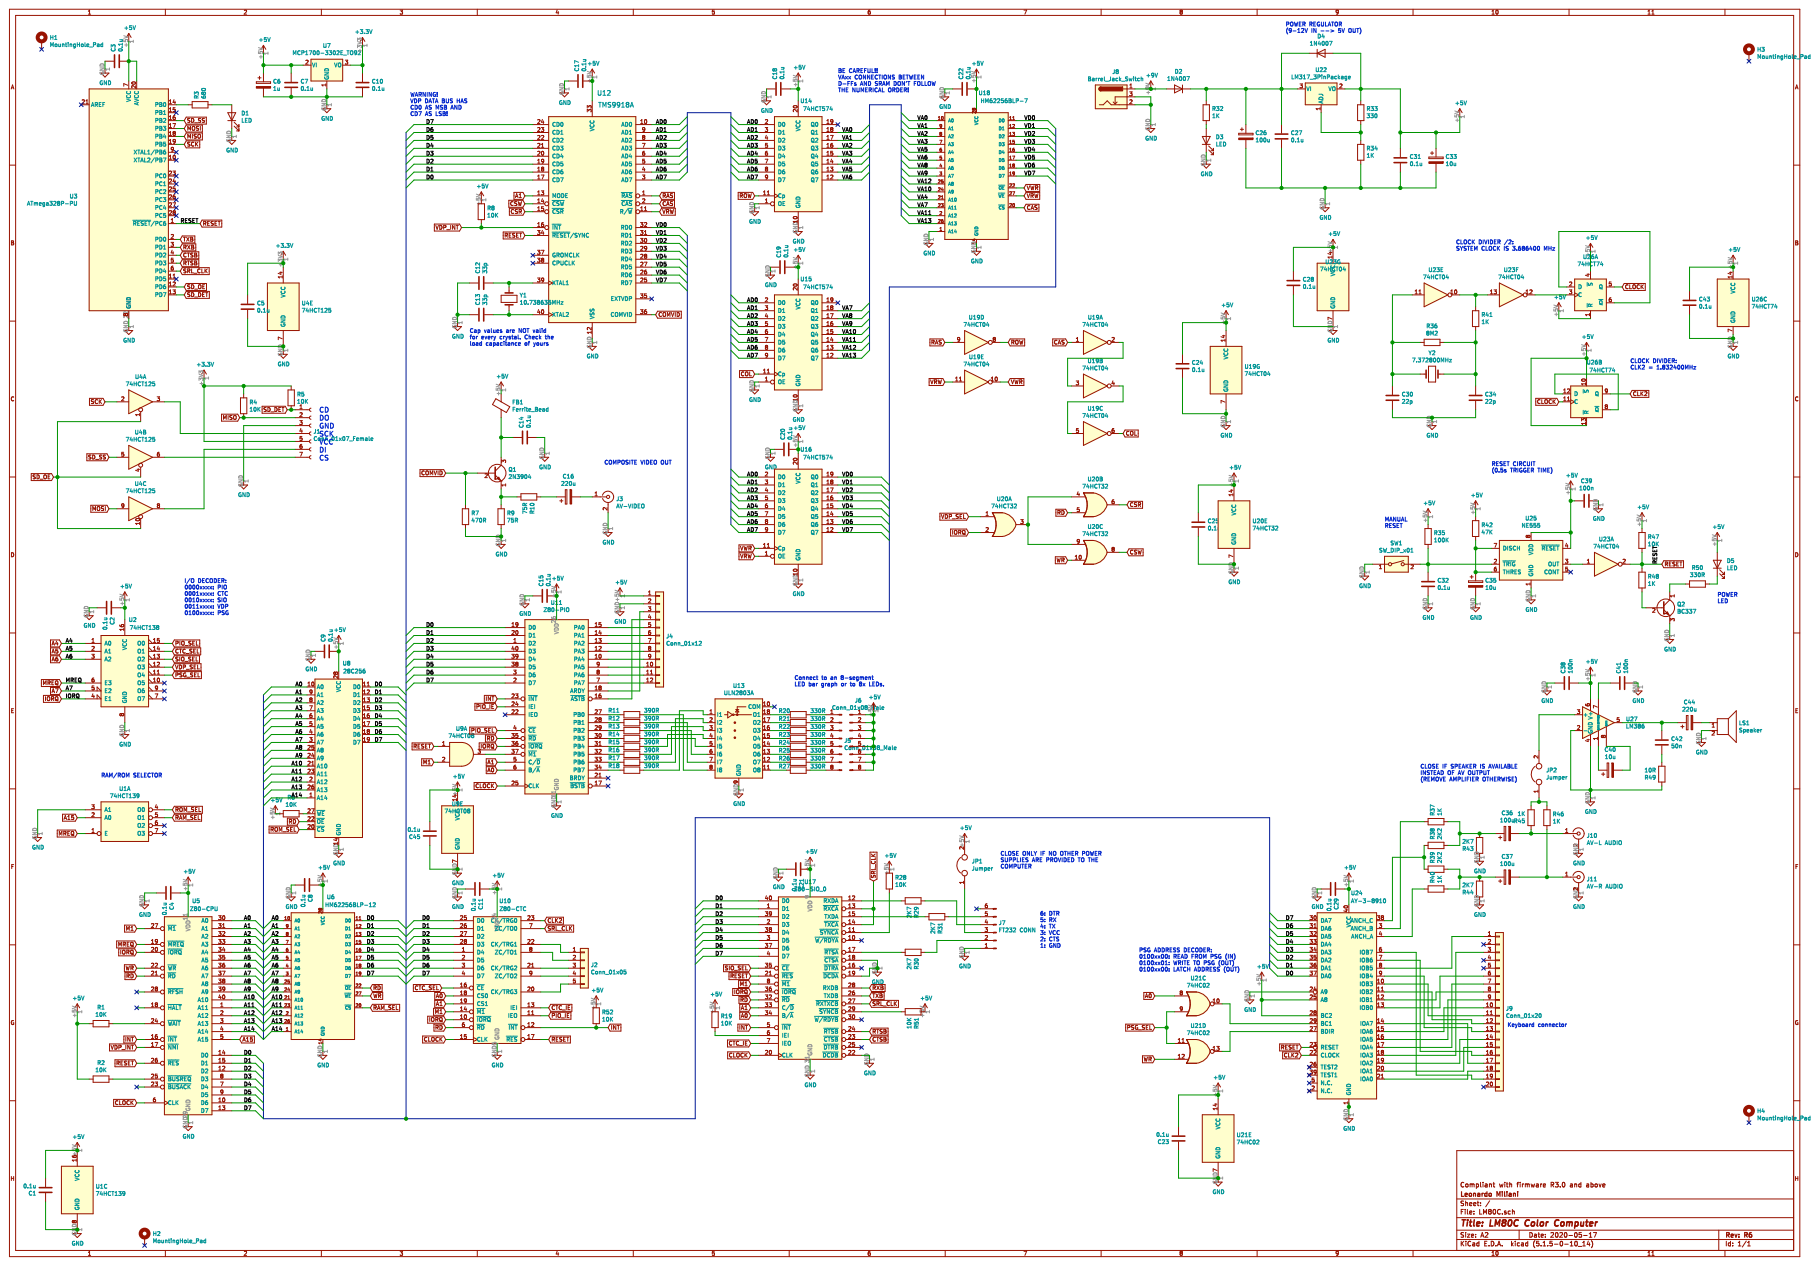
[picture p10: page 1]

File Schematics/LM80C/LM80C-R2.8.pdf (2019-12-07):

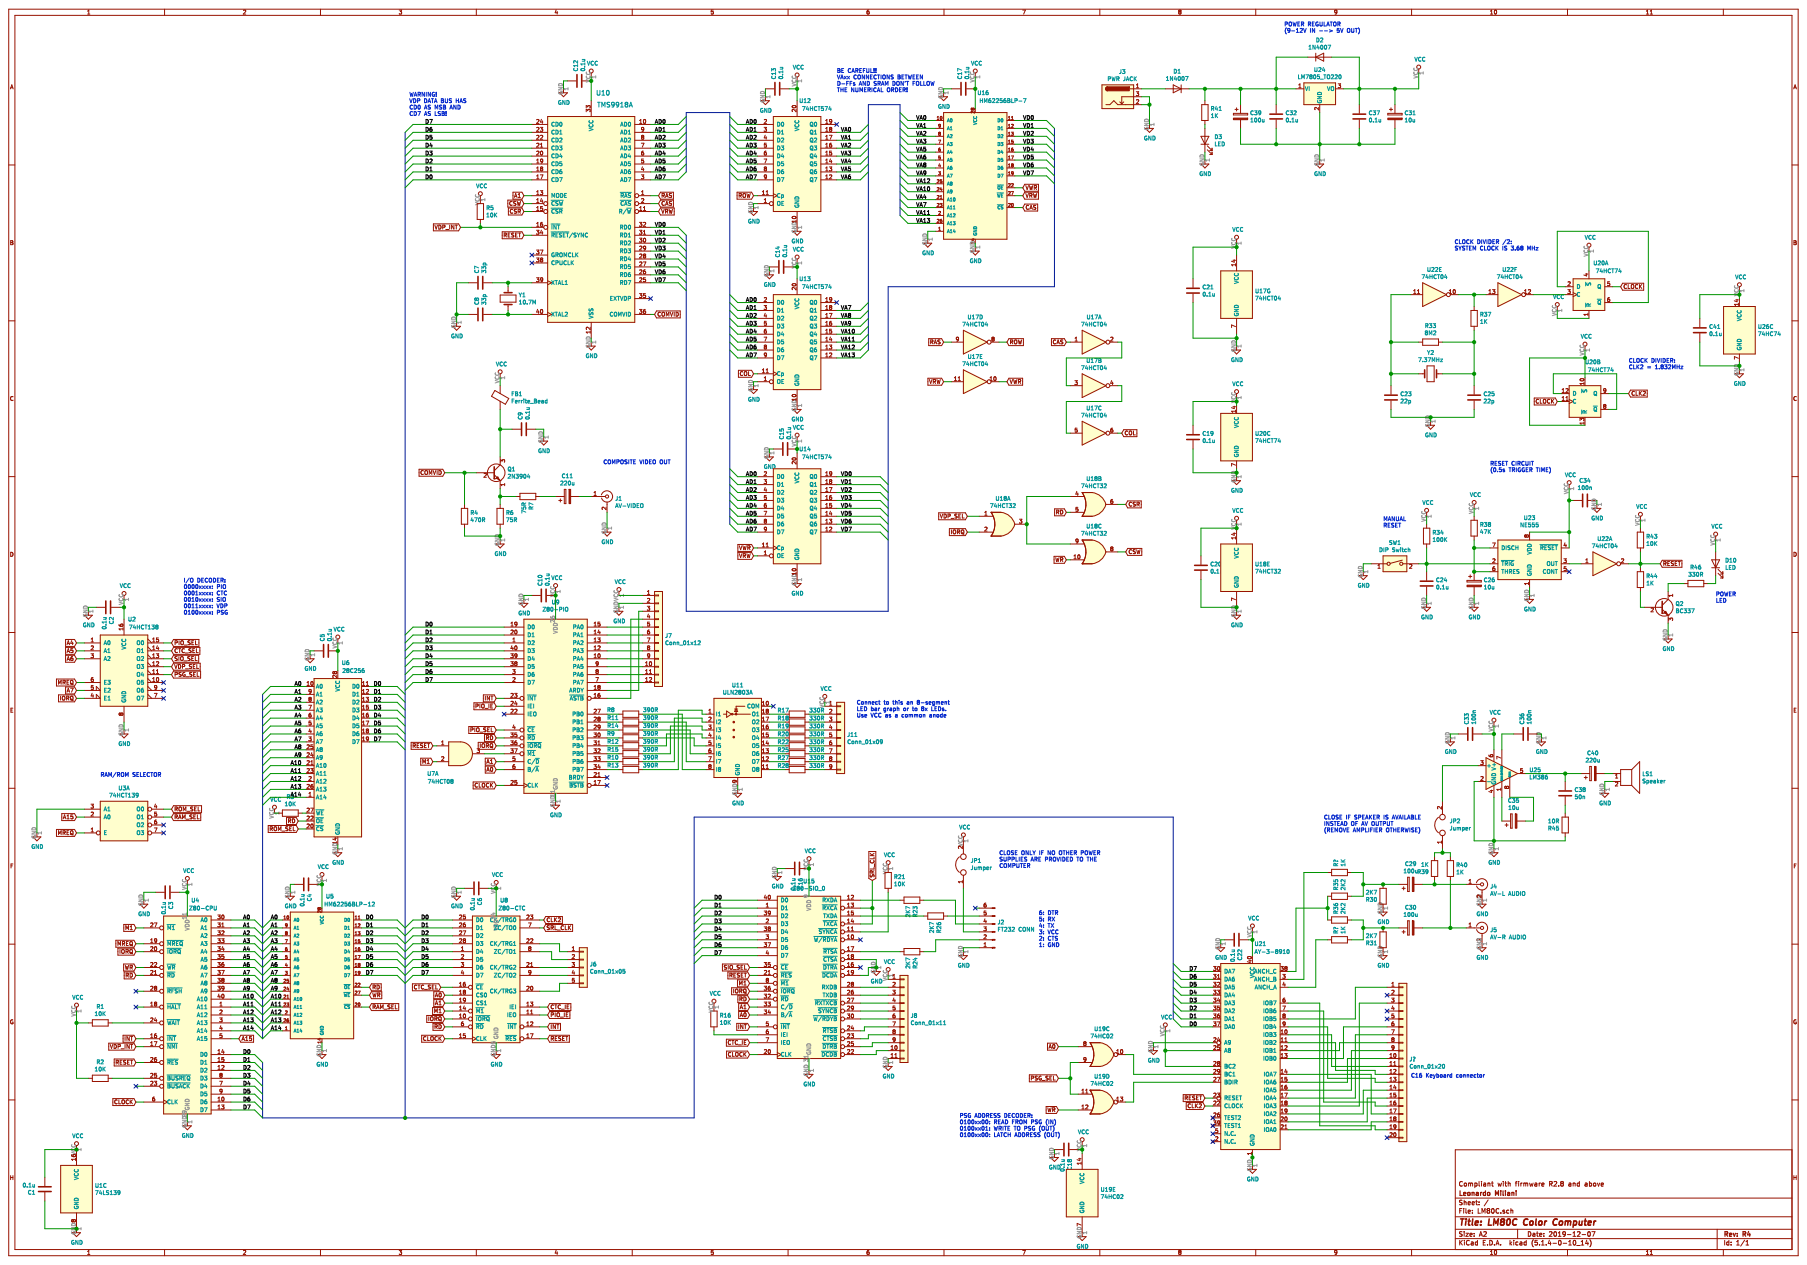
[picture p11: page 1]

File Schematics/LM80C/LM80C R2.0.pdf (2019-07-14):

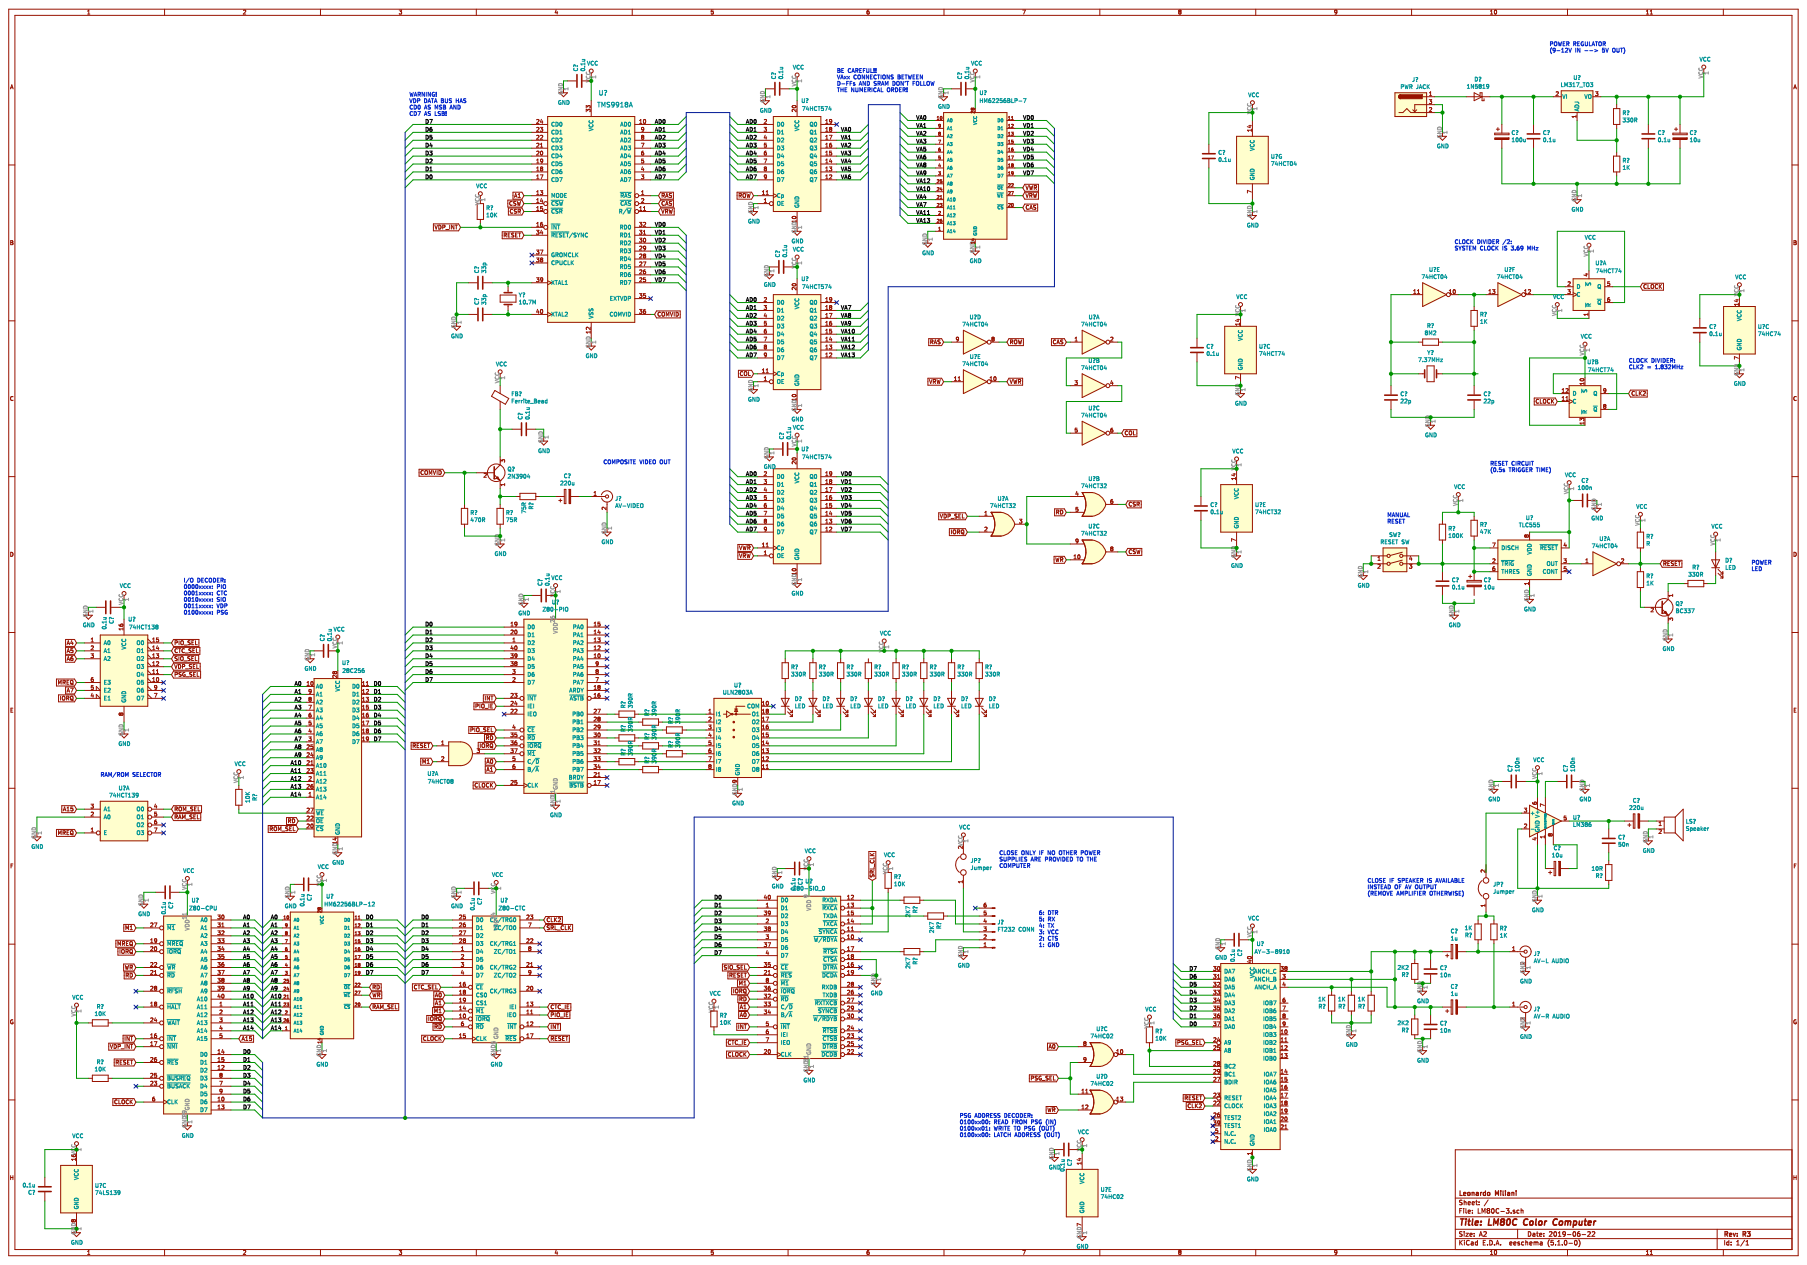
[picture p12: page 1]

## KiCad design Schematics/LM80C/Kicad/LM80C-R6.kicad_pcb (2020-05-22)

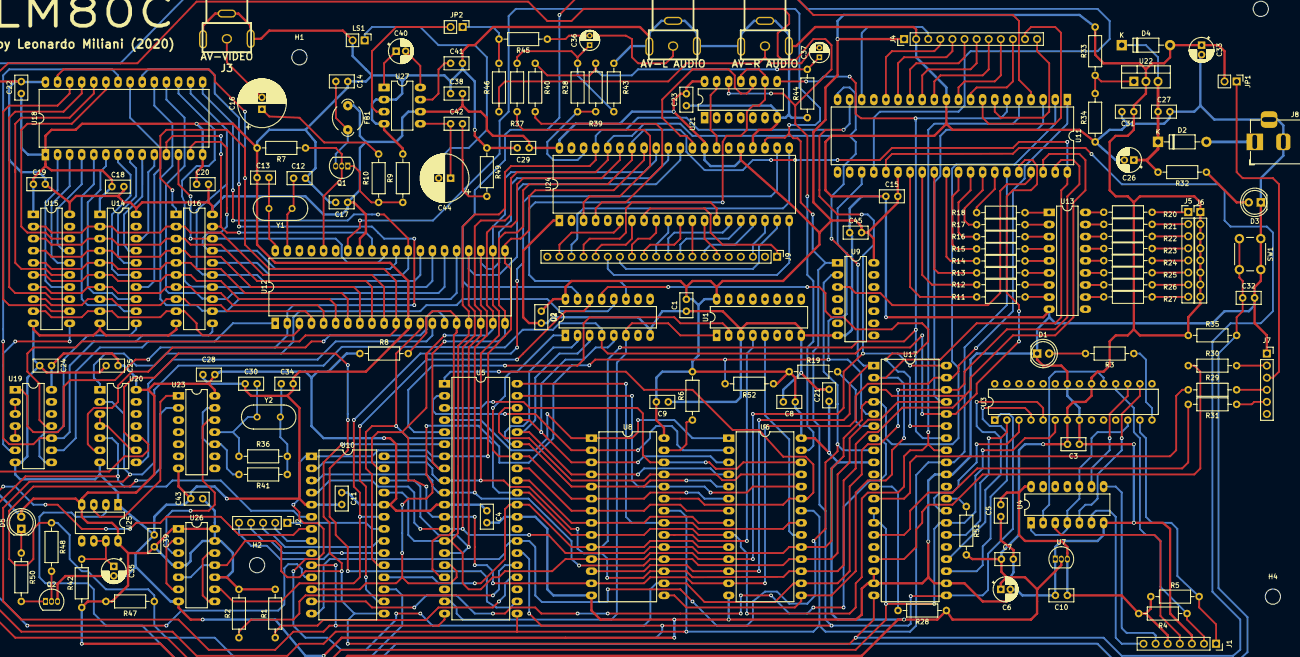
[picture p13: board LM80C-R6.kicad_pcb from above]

Board: 2 copper layers, 153 parts (0 on the bottom side), 220 nets.

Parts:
C1, C2, C3, C4, C5, C7, C8, C9, C10, C11, C14, C15, C17, C18, C19, C20, C21, C22, C23, C24, C25, C27, C28, C29, C31, C32, C43, C45: 0.1u; C_Disc_D5.0mm_W2.5mm_P2.50mm
C6: 1u; CP_Radial_D5.0mm_P2.00mm
C12, C13: 33p; C_Disc_D5.0mm_W2.5mm_P2.50mm
C16, C44: 220u; CP_Radial_D10.0mm_P2.50mm
C26: 100u; CP_Radial_D5.0mm_P2.00mm
C30, C34: 22p; C_Disc_D5.0mm_W2.5mm_P2.50mm
C33, C35, C40: 10u; CP_Radial_D5.0mm_P2.00mm
C36, C37: 100u; CP_Radial_D4.0mm_P2.00mm
C38, C39, C41: 100n; C_Disc_D5.0mm_W2.5mm_P2.50mm
C42: 50n; C_Disc_D5.0mm_W2.5mm_P2.50mm
D1, D3, D5: LED; LED_D5.0mm
D2, D4: 1N4007; D_DO-41_SOD81_P10.16mm_Horizontal
FB1: Ferrite_Bead; LairdTech_28C0236-0JW-10
H1, H2, H3, H4: MountingHole_Pad; MountingHole_3.2mm_M3
J1: Conn_01x07_Female; PinSocket_1x07_P2.54mm_Vertical
J2: Conn_01x05; PinHeader_1x05_P2.54mm_Vertical
J3: AV-VIDEO; RCAsimple
J4: Conn_01x12; PinHeader_1x12_P2.54mm_Vertical
J5, J6: Conn_01x08_Male; PinHeader_1x08_P2.54mm_Vertical
J7: FT232 CONN; PinSocket_1x06_P2.54mm_Vertical
J8: Barrel_Jack_Switch; BarrelJack_Horizontal
J9: Conn_01x20; PinHeader_1x20_P2.54mm_Vertical
J10: AV-L AUDIO; RCAsimple
J11: AV-R AUDIO; RCAsimple
JP1, JP2: Jumper; PinHeader_1x02_P2.54mm_Vertical
LS1: Speaker; PinHeader_1x02_P2.54mm_Vertical
Q1: 2N3904; TO-92_Inline
Q2: BC337; TO-92_Inline
R1, R2, R4, R5, R6, R8, R19, R28, R47, R51, R52: 10K; R_Axial_DIN0207_L6.3mm_D2.5mm_P10.16mm_Horizontal
R3: 680; R_Axial_DIN0207_L6.3mm_D2.5mm_P10.16mm_Horizontal
R7: 470R; R_Axial_DIN0207_L6.3mm_D2.5mm_P10.16mm_Horizontal
R9, R10: 75R; R_Axial_DIN0207_L6.3mm_D2.5mm_P10.16mm_Horizontal
R11, R12, R13, R14, R15, R16, R17, R18: 390R; R_Axial_DIN0207_L6.3mm_D2.5mm_P10.16mm_Horizontal
R20, R21, R22, R23, R24, R25, R26, R27, R50: 330R; R_Axial_DIN0207_L6.3mm_D2.5mm_P10.16mm_Horizontal
R29, R30, R31, R43, R44: 2K7; R_Axial_DIN0207_L6.3mm_D2.5mm_P10.16mm_Horizontal
R32, R34, R37, R40, R41, R45, R46, R48: 1K; R_Axial_DIN0207_L6.3mm_D2.5mm_P10.16mm_Horizontal
R33: 330; R_Axial_DIN0207_L6.3mm_D2.5mm_P10.16mm_Horizontal
R35: 100K; R_Axial_DIN0207_L6.3mm_D2.5mm_P10.16mm_Horizontal
R36: 8M2; R_Axial_DIN0207_L6.3mm_D2.5mm_P10.16mm_Horizontal
R38, R39: 2K2; R_Axial_DIN0207_L6.3mm_D2.5mm_P10.16mm_Horizontal
R42: 47K; R_Axial_DIN0207_L6.3mm_D2.5mm_P10.16mm_Horizontal
R49: 10R; R_Axial_DIN0207_L6.3mm_D2.5mm_P10.16mm_Horizontal
SW1: SW_DIP_x01; SW_PUSH_6mm_H4.3mm
U1: 74HCT139; DIP-16_W7.62mm_LongPads
U2: 74HCT138; DIP-16_W7.62mm_LongPads
U3: ATmega328P-PU; DIP-28_W7.62mm
U4: 74HCT125; DIP-14_W7.62mm_LongPads
U5: Z80-CPU; DIP-40_W15.24mm_LongPads
U6: HM62256BLP-12; DIP-28_W15.24mm_LongPads
U7: MCP1700-3302E_TO92; TO-92_Inline
U8: 28C256; DIP-28_W15.24mm_LongPads
U9: 74HCT08; DIP-14_W7.62mm_LongPads
U10: Z80-CTC; DIP-28_W15.24mm_LongPads
U11: Z80-PIO; DIP-40_W15.24mm_LongPads
U12: TMS9918A; DIP-40_W15.24mm_LongPads
U13: ULN2803A; DIP-18_W7.62mm_LongPads
U14, U15, U16: 74HCT574; DIP-20_W7.62mm_LongPads
U17: Z80-SIO_0; DIP-40_W15.24mm_LongPads
U18: HM62256BLP-7; DIP-28_W15.24mm_LongPads
U19, U23: 74HCT04; DIP-14_W7.62mm_LongPads
U20: 74HCT32; DIP-14_W7.62mm_LongPads
U21: 74HC02; DIP-14_W7.62mm_LongPads
U22: LM317_3PinPackage; TO-220-3_Vertical
U24: AY-3-8910; DIP-40_W15.24mm_LongPads
U25: NE555; DIP-8_W7.62mm_LongPads
U26: 74HCT74; DIP-14_W7.62mm_LongPads
U27: LM386; DIP-8_W7.62mm_LongPads
Y1: 10.738635MHz; Crystal_HC49-4H_Vertical
Y2: 7.372800MHz; Crystal_HC49-4H_Vertical

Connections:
+3V3: C5.1, C10.1, J1.5, R4.1, R5.1, U4.14, U7.3
+5V: C1.2, C2.1, C3.2, C4.1, C6.1, C7.1, C8.1, C9.2, C11.1, C15.2, C17.2, C18.2, C19.2, C20.2, C21.1, C22.2, C23.2, C24.1, C25.1, C28.1, C29.1, C31.1, C33.1, C38.2, C39.2, C43.1, C45.2, D4.2, D5.2, FB1.1, J4.1, J6.1, J6.2, J6.3, J6.4, J6.5, J6.6, J6.7, J6.8, JP1.2, R1.2, R2.2, R6.2, R8.1, R19.1, R28.1, R33.2, R35.1, R42.1, R47.1, R51.1, R52.1, U1.16, U2.16, U3.7, U3.20, U5.11, U6.28, U7.2, U8.28, U9.14, U10.24, U11.26, U12.33, U14.20, U15.20, U16.20, U17.9, U18.28, U19.14, U20.14, U21.14, U22.2, U23.14, U24.25, U24.28, U24.40, U25.4, U25.8, U26.1, U26.4, U26.10, U26.13, U26.14, U27.6
+9V: D2.2, J8.1
/A2: U5.32, U6.8, U8.8
/A3: U5.33, U6.7, U8.7
/A8: U5.38, U6.25, U8.25
/A9: U5.39, U6.24, U8.24
/A10: U5.40, U6.21, U8.21
/A11: U5.1, U6.23, U8.23
/A12: U5.2, U6.2, U8.2
/A13: U5.3, U6.26, U8.26
/A14: U5.4, U6.1, U8.1
/AD0: U12.10, U14.2, U15.2, U16.2
/AD1: U12.9, U14.3, U15.3, U16.3
/AD2: U12.8, U14.4, U15.4, U16.4
/AD3: U12.7, U14.5, U15.5, U16.5
/AD4: U12.6, U14.6, U15.6, U16.6
/AD5: U12.5, U14.7, U15.7, U16.7
/AD6: U12.4, U14.8, U15.8, U16.8
/AD7: U12.3, U14.9, U15.9, U16.9
/D0: U5.14, U6.11, U8.11, U10.25, U11.19, U12.17, U17.40, U24.37
/D1: U5.15, U6.12, U8.12, U10.26, U11.20, U12.18, U17.1, U24.36
/D2: U5.12, U6.13, U8.13, U10.27, U11.1, U12.19, U17.39, U24.35
/D3: U5.8, U6.15, U8.15, U10.28, U11.40, U12.20, U17.2, U24.34
/D4: U5.7, U6.16, U8.16, U10.1, U11.39, U12.21, U17.38, U24.33
/D5: U5.9, U6.17, U8.17, U10.2, U11.38, U12.22, U17.3, U24.32
/D6: U5.10, U6.18, U8.18, U10.3, U11.3, U12.23, U17.37, U24.31
/D7: U5.13, U6.19, U8.19, U10.4, U11.2, U12.24, U17.4, U24.30
/VA0: U14.18, U18.10
/VA1: U14.17, U18.9
/VA2: U14.16, U18.8
/VA3: U14.15, U18.7
/VA4: U14.14, U18.21
/VA5: U14.13, U18.6
/VA6: U14.12, U18.5
/VA7: U15.18, U18.23
/VA8: U15.17, U18.4
/VA9: U15.16, U18.3
/VA10: U15.15, U18.24
/VA11: U15.14, U18.2
/VA12: U15.13, U18.25
/VA13: U15.12, U18.26
/VD0: U12.32, U16.19, U18.11
/VD1: U12.31, U16.18, U18.12
/VD2: U12.30, U16.17, U18.13
/VD3: U12.29, U16.16, U18.15
/VD4: U12.28, U16.15, U18.16
/VD5: U12.27, U16.14, U18.17
/VD6: U12.26, U16.13, U18.18
/VD7: U12.25, U16.12, U18.19
A0: U5.30, U6.10, U8.10, U10.18, U11.6, U17.34, U21.8
A1: U5.31, U6.9, U8.9, U10.19, U11.5, U12.13, U17.33
A4: U2.1, U5.34, U6.6, U8.6
A5: U2.2, U5.35, U6.5, U8.5
A6: U2.3, U5.36, U6.4, U8.4
A7: U2.5, U5.37, U6.3, U8.3
A15: U1.2, U5.5
CAS: U12.2, U18.20, U19.1
CLK2: U10.23, U24.22, U26.9
CLOCK: U5.6, U10.15, U11.25, U17.20, U26.5, U26.11
COL: U15.11, U19.6
COMVID: Q1.2, R7.1, U12.36
CSR: U12.15, U20.6
CSW: U12.14, U20.8
CTC_IE: U10.13, U17.7
CTC_SEL: U2.14, U10.16
CTSB: U3.4, U17.23
GND: C1.1, C2.2, C3.1, C4.2, C5.2, C6.2, C7.2, C8.2, C9.1, C10.2, C11.2, C12.1, C13.1, C14.2, C15.1, C17.1, C18.1, C19.1, C20.1, C21.2, C22.1, C23.1, C24.2, C25.2, C26.2, C27.2, C28.2, C29.2, C30.2, C31.2, C32.2, C33.2, C34.2, C35.2, C38.1, C39.1, C41.2, C43.2, C45.1, D1.1, D3.1, J1.3, J3.2, J4.2, J7.1, J8.2, J8.3, J10.2, J11.2, LS1.2, Q2.3, R7.2, R9.2, R34.1, R43.1, R44.1, R49.1, SW1.1, U1.3, U1.8, U2.8, U3.8, U3.22, U4.7, U5.29, U6.14, U7.1, U8.14, U9.7, U10.5, U11.11, U12.12, U13.9, U14.1, U14.10, U15.1, U15.10, U16.10, U17.18, U17.19, U17.22, U17.31, U18.1, U18.14, U19.7, U20.7, U21.7, U23.7, U24.1, U24.24, U25.1, U26.7, U27.2, U27.4
INT: R52.2, U5.16, U10.12, U11.23, U17.5
IORQ: U2.4, U5.20, U10.10, U11.36, U17.36, U20.2
M1: U5.27, U9.2, U10.14, U17.8
MISO: J1.2, R4.2, U3.18
MOSI: U3.17, U4.9
MREQ: U1.1, U2.6, U5.19
unnamed: C12.2, U12.39, Y1.1
unnamed: C13.2, U12.40, Y1.2
unnamed: C14.1, FB1.2, Q1.3
unnamed: C16.1, R10.1
unnamed: C16.2, J3.1
unnamed: C26.1, C27.1, D2.1, D4.1, R32.2, U22.3
unnamed: C30.1, R36.2, U23.11, Y2.1
unnamed: C32.1, R35.2, SW1.2, U25.2
unnamed: C34.1, R36.1, R41.1, Y2.2
unnamed: C35.1, R42.2, U25.6, U25.7
unnamed: C36.1, R37.2, R38.2, R43.2
unnamed: C36.2, J10.1, R45.1
unnamed: C37.1, R39.2, R40.2, R44.2
unnamed: C37.2, J11.1, R46.2
unnamed: C40.1, U27.1
unnamed: C40.2, U27.8
unnamed: C41.1, U27.7
unnamed: C42.1, C44.1, U27.5
unnamed: C42.2, R49.2
unnamed: C44.2, LS1.1
unnamed: D1.2, R3.2
unnamed: D3.2, R32.1
unnamed: D5.1, R50.1
unnamed: J1.4, U4.3
unnamed: J1.6, U4.8
unnamed: J1.7, U4.6
unnamed: J2.1, U10.22
unnamed: J2.2, U10.8
unnamed: J2.3, U10.21
unnamed: J2.4, U10.9
unnamed: J2.5, U10.20
unnamed: J4.3, U11.18
unnamed: J4.4, U11.16
unnamed: J4.5, U11.15
unnamed: J4.6, U11.14
unnamed: J4.7, U11.13
unnamed: J4.8, U11.12
unnamed: J4.9, U11.10
unnamed: J4.10, U11.9
unnamed: J4.11, U11.8
unnamed: J4.12, U11.7
unnamed: J5.1, R20.1
unnamed: J5.2, R21.1
unnamed: J5.3, R22.1
unnamed: J5.4, R23.1
unnamed: J5.5, R24.1
unnamed: J5.6, R25.1
unnamed: J5.7, R26.1
unnamed: J5.8, R27.1
unnamed: J7.2, R30.1
unnamed: J7.3, JP1.1
unnamed: J7.4, R29.1
unnamed: J7.5, R31.1
unnamed: J9.1, U24.8
unnamed: J9.3, U24.18
unnamed: J9.6, U24.13
unnamed: J9.7, U24.17
unnamed: J9.8, U24.12
unnamed: J9.9, U24.16
unnamed: J9.10, U24.15
unnamed: J9.11, U24.10
unnamed: J9.12, U24.11
unnamed: J9.13, U24.9
unnamed: J9.14, U24.19
unnamed: J9.15, U24.20
unnamed: J9.16, U24.7
unnamed: J9.17, U24.14
unnamed: J9.18, U24.21
unnamed: J9.19, U24.6
unnamed: JP2.1, R45.2, R46.1
unnamed: JP2.2, U27.3
unnamed: Q1.1, R9.1, R10.2
unnamed: Q2.1, R50.2
unnamed: Q2.2, R48.2
unnamed: R1.1, U5.24
unnamed: R2.1, U5.25
unnamed: R3.1, U3.14
unnamed: R6.1, U8.27
unnamed: R11.1, U11.27
unnamed: R11.2, U13.8
unnamed: R12.1, U11.28
unnamed: R12.2, U13.7
unnamed: R13.1, U11.29
unnamed: R13.2, U13.6
unnamed: R14.1, U11.30
unnamed: R14.2, U13.5
unnamed: R15.1, U11.31
unnamed: R15.2, U13.4
unnamed: R16.1, U11.32
unnamed: R16.2, U13.3
unnamed: R17.1, U11.33
unnamed: R17.2, U13.2
unnamed: R18.1, U11.34
unnamed: R18.2, U13.1
unnamed: R19.2, U17.6
unnamed: R20.2, U13.18
unnamed: R21.2, U13.17
unnamed: R22.2, U13.16
unnamed: R23.2, U13.15
unnamed: R24.2, U13.14
unnamed: R25.2, U13.13
unnamed: R26.2, U13.12
unnamed: R27.2, U13.11
unnamed: R28.2, U17.11
unnamed: R29.2, U17.12
unnamed: R30.2, U17.17
unnamed: R31.2, U17.15
unnamed: R33.1, R34.2, U22.1
unnamed: R37.1, U24.3
unnamed: R38.1, R39.1, U24.38
unnamed: R40.1, U24.4
unnamed: R41.2, U23.10, U23.13
unnamed: R51.2, U17.29
unnamed: U9.3, U11.37
unnamed: U19.2, U19.3
unnamed: U19.4, U19.5
unnamed: U20.3, U20.4, U20.9
unnamed: U21.10, U24.29
unnamed: U21.13, U24.27
unnamed: U23.1, U25.3
unnamed: U23.12, U26.3
unnamed: U26.2, U26.6
unnamed: U26.8, U26.12
PIO_IE: U10.11, U11.24
PIO_SEL: U2.15, U11.4
PSG_SEL: U2.11, U21.9, U21.11
RAM_SEL: U1.5, U6.20
RAS: U12.1, U19.9
RD: U5.21, U6.22, U8.22, U10.6, U11.35, U17.32, U20.5
RESET: R47.2, R48.1, U3.1, U5.26, U9.1, U10.17, U12.34, U17.21, U23.2, U24.23
ROM_SEL: U1.4, U8.20
ROW: U14.11, U19.8
RTSB: U3.5, U17.24
RXB: U3.3, U17.28
SCK: U3.19, U4.2
SD_DET: J1.1, R5.2, U3.13
SD_OE: U3.12, U4.1, U4.4, U4.10
SD_SS: U3.16, U4.5
SIO_SEL: U2.13, U17.35
SRL_CLK: U3.6, U10.7, U17.13, U17.14, U17.27
TXB: U3.2, U17.26
VDP_INT: R8.2, U5.17, U12.16
VDP_SEL: U2.12, U20.1
VRW: U12.11, U16.1, U18.27, U19.11
VWR: U16.11, U18.22, U19.10
WR: U5.22, U6.27, U20.10, U21.12

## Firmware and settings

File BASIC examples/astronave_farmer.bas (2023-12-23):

2 REM "ASTRONAVE FARMER (C) 1983 MARIO PETTENGHI & MCOMPUTER"
4 REM "CONVERTITO PER LM80C BASIC DA LEONARDO MILIANI"
6 CO=8:VE=11:SO=20:OG=10
8 DIM CO$(8),VE$(11),SO$(20),OG(10),OG$(10),FL(9)
10 DX$=CHR$(13):SCREEN 0:COLOR 11,1:VOLUME 0,15:GOTO 500
20 INPUT "Cosa devo fare";FR$:X=0:Y=0
22 TT$="":FOR J=1TOLEN(FR$):TC$=MID$(FR$,J,1)
24 IF TC$>="a" AND TC$<="z" THEN TT$=TT$+CHR$(ASC(TC$)-32):GOTO28
26 TT$=TT$+TC$
28 NEXT:FR$=TT$
30 FOR J=1 TO CO:IF INSTR(FR$,CO$(J))<>0 THEN X=J
40 NEXT:ON X GOSUB 100,100,100,100,8000,9000,9500,9700
45 PAUSE 200:IF X THEN RETURN
50 FOR J=1 TO VE:IF INSTR(FR$,VE$(J))<>0 THEN X=J
60 NEXT:FOR J=1 TO SO:IF INSTR(FR$,SO$(J))<>0 THEN Y=J
70 NEXT:ON X GOSUB 1000,1100,1200,1300,1400,1500,1600,1700,1800,1900,1920
75 GOSUB 7000:PAUSE 200:IF X THEN RETURN
80 SOUND 3,4000,5:PRINT DX$;"..saro' stupido ma non ti capisco!";DX$:GOTO 20
82 N=0:E=0:S=0:O=0:SOUND 3,4000,5
84 CLS:IF LO>20 THEN ON LO-20 GOSUB 2210,2220,2230,2240,2250,2260:GOTO 94
86 IF LO>10 THEN 90
88 ON LO GOSUB 2000,2010,2020,2030,2040,2050,2060,2070,2080,2090,2100:GOTO 94
90 LO=LO-10:ON LO GOSUB 2110,2120,2130,2140,2150,2160,2170,2180,2190,2200
94 PRINT:PRINT "Direzioni: ";:IF N THEN PRINT "NORD ";
96 IF E THEN PRINT "EST ";
97 IF S THEN PRINT "SUD ";
98 IF O THEN PRINT "OVEST ";
99 RETURN
100 IF LO=2 AND X=3 AND FL(1)=0 THEN PRINT"La porta di sicurezza e' bloccata!":RETURN
101 IF LO=10 AND X=2 AND OG(3) THEN PRINT"Solo gli ufficiali possono entrare!":RETURN
102 IF LO=17 AND FL(6)=0 AND X=4 THEN PRINT "Il portellone non si apre!!!":RETURN
103 IF LO=17 AND X=4 AND FL(4)=0 THEN 106
104 GOTO 108
106 PRINT "Vuoi uscire dalla nave mentre e' in":PRINT"volo? Idiota.":RETURN
108 ON X GOTO 110,120,130,140
110 IF N=0 THEN 150
111 LO=N:RETURN
120 IF E=0 THEN 150
121 LO=E:RETURN
130 IF S=0 THEN 150
131 LO=S:RETURN
140 IF O=0 THEN 150
141 LO=O:RETURN
150 PRINT "Non puoi andare in quella direzione...":PRINT:RETURN
200 PRINT "Oggetti visibili: ";
210 FL=0:FOR J=1 TO OG:IF OG(J)=LO THEN PRINT TAB(19);OG$(J):FL=1
220 NEXT:IF FL=0 THEN PRINT TAB(19);"NESSUNO"
230 IF LO=8 AND FL(2)=0 THEN GOTO 9100
300 PRINT "--------------------------------------":RETURN
500 FOR J=1 TO CO:READ CO$(J):NEXT
540 FOR J=1 TO VE:READ VE$(J):NEXT
550 FOR J=1 TO SO:READ SO$(J):NEXT
560 FOR J=1 TO OG:READ OG(J),OG$(J):NEXT
590 LO=1:CLS
600 PRINT "--------------------------------------":GOSUB 82
610 PRINT:GOSUB 200
620 PRINT:GOSUB 20
630 GOTO 600
1000 IF Y=0 THEN PRINT "Non ci trovi nulla di":PRINT"interessante!":RETURN
1010 IF LO=2 AND Y=10 THEN 1014
1012 GOTO 1020
1014 PRINT "E' una porta di sicurezza. Puoi":PRINT"aprirla con la sua scheda di"
1016 PRINT "riconoscimento.":RETURN
1020 IF LO=4 AND Y=11 THEN 1024
1022 GOTO 1030
1024 PRINT:PRINT "E' di metallo, ma lo sportello non":PRINT "ha serrature.":RETURN
1030 IF LO=6 AND Y=13 AND OG(3)=69 THEN 1034
1032 GOTO 1040
1034 PRINT "Era il comandante C.P.Ustinov.":PRINT "Grand'uomo. Non ha soldi ";
1036 PRINT "in tasca,":PRINT"ma ha una tessera con foto sul petto"
1038 PRINT "e una brutta cera.":OG(3)=6:RETURN
1040 IF LO=18 AND Y=16 AND FL(3)=0 THEN 1044
1042 GOTO 1050
1044 PRINT"C'e' scritto qualcosa in un vecchio":PRINT"linguaggio. Un appassionato di"
1046 PRINT "computer saprebbe certo decifrarlo...":RETURN
1050 IF LO=18 AND Y=16 AND FL(3) THEN 1054
1052 GOTO 1060
1054 PRINT"Le tue conoscenze di computer ti":PRINT"consentono di leggere il codice di"
1056 PRINT "uscita":FL(6)=1 :RETURN
1060 IF LO=21 AND Y=18 AND OG(8)<>0 THEN 1064
1062 GOTO 1090
1064 PRINT "E' di ottone. C'e' una torcia su di":PRINT"esso!":OG(8)=21:RETURN
1090 PRINT "Mi bruciano gli occhi dallo sforzo.":RETURN
1100 FL=0:IF Y=0 THEN  1115
1102 IF LO=6 AND Y=13 THEN PRINT "No. amico, chiedilo a Frankenstein!":RETURN
1103 IF LO=4 AND Y=2 THEN 1105
1104 GOTO 1106
1105 PRINT "No, non vale la pena, non e' nemmemo":PRINT"digitale.":RETURN
1106 IF LO=5 AND Y=3 THEN PRINT "E' bloccato con una catenella!":RETURN
1109 FOR J=1 TO OG:IF INSTR(OG$(J),SO$(Y))<>0 THEN FL=J
1110 NEXT
1115 IF FL=0 OR LO<>OG(FL) THEN PRINT "Andiamo, cerca di essere serio!!":RETURN
1120 OG(FL)=0:PRINT "OK, eseguito.":RETURN
1200 FOR J=1 TO OG:IF SO$(Y)=OG$(J) THEN FL=J
1210 NEXT
1220 IF FL=0 OR OG(FL)<>0 THEN 1224
1222 GOTO 1230
1224 PRINT "Come posso lasciare quello che non ho,":PRINT"totano!":RETURN
1230 OG(FL)=LO:PRINT "OK... come vuoi tu!":RETURN
1300 IF Y=0 THEN 1390
1310 IF LO=4 AND Y=2 THEN PRINT "E' spento...":RETURN
1320 IF LO=11 AND Y=7 AND FL(5) AND OG(7)=0 THEN 1324
1322 GOTO 1330
1324 LO=14:PRINT "OK, funziona, ma non c'e' piu' energia"
1326 PRINT "per un secondo utilizzo":RETURN
1330 IF LO=11 AND Y=7 AND FL(5)=0 THEN 1334
1332 GOTO 1340
1334 PRINT "Per farlo devi attivare prima il motore.";:RETURN
1340 IF LO=11 AND Y=7 AND OG(7) THEN 1344
1342 GOTO 1390
1344 PRINT "E' necessaria la chiave del quadro":PRINT "comandi!":RETURN
1390 PRINT "Prova a usare il cervello, se non e'":PRINT "un optional!":RETURN
1400 IF Y=17 AND OG(8)=0 THEN OG(8)=-1:PRINT "OK....":RETURN
1408 IF Y<>2 THEN PRINT "Accenditi la barba, ippogrifo!":RETURN
1410 IF LO=4 AND OG(6) THEN 1414
1412 GOTO 1420
1414 PRINT "Dovrei avere anche una cassetta per":PRINT"farlo!":RETURN
1420 IF LO<>4 THEN PRINT "Dove lo trovo? Su Audio Review?":RETURN
1440 PRINT "OK.. C'e' un messaggio:"
1441 PRINT "SEI STATO RISVEGLIATO DALL'IBERNAZIONE"
1442 PRINT "PER UNA MISSIONE DI EMERGENZA!"
1443 PRINT "L'ASTRONAVE 'FARMER' HA AVUTO UN'AVARIA."
1444 PRINT "DEVI RIPROGRAMMARE IL COMPUTER DI BORDO"
1445 PRINT "PER UN ATTERRAGGIO DI FORTUNA. PER FARLO";
1446 PRINT "TI SERVE UN FLOPPY DISC CHE CONTIENE I "
1447 PRINT "DATI NECESSARI. TROVALO E INSERISCILO "
1448 PRINT "NEL LETTORE DEL COMPUTER DI BORDO."
1449 PRINT "E' IN GIOCO ANCHE LA TUA VITA. AUGURI."
1471 RETURN
1500 IF LO=13 AND Y=15 THEN 1520
1510 GOTO 1590
1520 PRINT "Le luci vacillano per un istante.":PRINT"Tutto OK.":FL(5)=1:RETURN
1590 PRINT "Forse una petunia ha un Q.I.":PRINT"superiore al tuo...":RETURN
1600 IF Y=0 THEN 1604
1602 GOTO 1610
1604 PRINT "Ora ti apriro' il cranio se continui":PRINT"a dire scemate!":RETURN
1610 IF LO=2 AND OG(1)=0 AND Y=10 THEN 1614
1612 GOTO 1620
1614 PRINT "La porta si apre lentamente...":FL(1)=1:RETURN
1620 IF LO=4 AND Y=11 THEN PRINT "C'e' una cassetta qui dentro!":OG(6)=4:RETURN
1690 PRINT "Non ci riesco!!!":RETURN
1700 IF LO=5 AND Y=3 THEN FL(3)=1: PRINT "Ora sai tutto di computer!":RETURN
1710 PRINT "E' meglio un buon libro di":PRINT"fantascienza":RETURN
1800 IF Y<>6 THEN 1830
1810 IF OG(5)<>0 THEN PRINT "Non mi sembra di averne una...":RETURN
1820 FL(2)=1:PRINT "Non e' proprio la tua taglia, ma":PRINT"puo' andare!":RETURN
1830 PRINT "L'unica cosa che potrei mettere e'"
1835 PRINT "la tua testa in un tritatutto!":RETURN
1900 CLS:RETURN
1920 IF LO<>16 OR Y<>5 THEN 1970
1930 IF OG(4)<>0THENPRINT "Buona idea! Peccato che non ne abbia":PRINT"uno...":RETURN
1940 PRINT "Complimenti! Il calcolatore e'":PRINT"riprogrammato. Stiamo atterrando!"
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

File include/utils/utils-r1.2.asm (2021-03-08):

; ------------------------------------------------------------------------------
; LM80C - UTILITY ROUTINES - R1.2
; ------------------------------------------------------------------------------
; The following code is intended to be used with LM80C Z80-based computer
; designed by Leonardo Miliani. More info at
; www DOT leonardomiliani DOT com
;
; *ALS are routines from "Z80 Assembly Language Subroutines" by Lance
; A. Leventhal and Winthrop Saville - Ed. Osborne/McGraw-Hill (1983)
;
; * WKT are routines from WikiTI:
; http://wikiti.brandonw.net/index.php?title=WikiTI_Home
;
; * LAC are routines from Learn@Cemetch
; https://learn.cemetech.net/index.php/Main_Page
;
; ------------------------------------------------------------------------------
; Code Revision:
; R1.0 - 20200110 - First release: 16-bit comparision/multiplication/negation
; R1.1 - 20200413 - Second release: added ABS(HL)
; R1.2 - 20200131 - Added 32/16 bit multiplication/division and converter to
;                   transform a 32-bit value into ASCII representation
;
; ------------------------------------------------------------------------------

; compare two 16-bit registers, HL (minuend) and DE (subtrahend)
; values can be both signed or unsigned words
; inputs: HL, DE
; destroys: A,F,HL
;
; returns: Z=1 if HL = DE
; for UNSIGNED: C=1 if HL<DE  //  C=0 if HL>DE
; for SIGNED:   S=1 (M) if HL<DE  //  S=0 (P) if HL>DE
; if HL=DE: Z,P,NC  - Z=1, S=0; C=0
; if HL>DE: NZ,P,NC - Z=0, S=0; C=0
; if HL<DE: NZ,M,C  - Z=0, S=1; C=1
; Source: ALS

CMP16:  or      A           ; clear CARRY
        sbc     HL,DE       ; subtract DE from HL
        ret     PO          ; return if no overflow
        ld      A,H         ; overflow - invert SIGN flag
        rra                 ; save CARRY flag in bit 7
        xor     %01000000   ; complement bit 6 (SIGN bit)
        scf                 ; ensure a Non-Zero result
        adc     A,A         ; restore CARRY, complemented SIGN
                            ; ZERO flag = 0 for sure
        ret                 ; return

; ----------------------------------------------------------------------

; multiply 2 signed/unsigned 16-bit words and return a 16-bit
; signed/unsigned product
; inputs: HL (multiplicand); DE (multiplier)
; destroys: A,F
; returns: HL (product)
; Source: ALS

; initialize partial product, bit count
MUL16:  push    BC
        ld      C,L         ; BC = multiplier
        ld      B,H
        ld      HL,0        ; product = 0
        ld      A,$0F       ; count = bit lenght - 1 (16-1)
        ; shift-and-add algorithm
        ; if MSB of multiplier is 1, add multiplicand to partial product
        ; shift partial product, multiplier left 1 bit
MLP:    sla     E           ; shift multiplier left 1 bit
        rl      D
        jr      NC,MLP1     ; jump if MSB of multiplier = 0
        add     HL,BC       ; add multiplicand to partial product
MLP1:   add     HL,HL       ; shift partial product left
        dec     A
        jr      NZ,MLP      ; continue until count = 0
        ; add multiplicand one last time if MSB of multiplier is 1
        or      D           ; sign flag = MSB of multiplier
        jp      P,EXMUL16   ; exit if MSB of multiplier is 0
        add     HL,BC       ; add multiplicand to product
EXMUL16:pop     BC
        ret


; ----------------------------------------------------------------------

; multiply 2 unsigned 16-bit words and return a 32-bit unsigned product
; inputs: BC (multiplicand); DE (multiplier)
; destroys: A,F
; operation: BC * DE
; returns: DEHL (product)
; Source: WKT

MUL_U32:ld      HL,$0000        ; reset HL
        sla     E		; optimised 1st iteration
        rl      D
        jr      NC,MU32_1       ; if no Carry then jump over
        ld      H,B
        ld      L,C
MU32_1: ld      A,$0F
MUL_32L:add     HL,HL           ; main loop
        rl      E
        rl      D
        jr      NC,MU32_2
        add     HL,BC
        jr      NC,MU32_2
        inc     DE
MU32_2: dec     A
        jr      NZ,MUL_32L
        ret

; ----------------------------------------------------------------------
; absolute value of HL (same applies to other 16-bit register pairs)
; also, invert value of HL (or any other 16-bit register, just adjust the code)
;
; inputs: HL
; destroys: A
; operation: ABS(HL)
; returns: HL with no sign or negated
; Source: WKT

absHL:  bit     7,H
        ret     Z
negHL:  xor     A
        sub     L
        ld      L,A
        sbc     A,A
        sub     H
        ld      H,A
        ret

; ------------------------------------------------------------------------------

; 8/8 division
; INPUT: D (dividend), E (divisor)
; OPERATION: D/E
; OUTPUT: D (quotient), A (remainder)
DIV_8_8:    xor     A
            push    BC
            ld      B,08h
DIV_8_8LOOP:sla     D
            rla
            cp      E
            jr      C,$+4
            sub     E
            inc     D
            djnz    DIV_8_8LOOP
            pop     BC
            ret

; ----------------------------------------------------------------------
; divide a 16-bit number by an 8-bit number
; (16/8 division)
;
; inputs: HL (Dividend), C (divisor)
; destroys: A, B
; OPERATION: HL/C
; returns: HL (quotient), A (remainder)
; source: WKT

DIV_16_8:   xor     A
            ld      B,16
DIV_16_8LP: add     HL,HL
            rla
            jr      C,$+5
            cp      C
            jr      C,$+4
            sub     C
            inc     L
            djnz    DIV_16_8LP
            ret
        
; ----------------------------------------------------------------------
; divide a 16-bit number by a 16-bit number
; (16/16 division)
;
; inputs: AC (Dividend), DE (divisor)
; destroys: HL,A,C
; OPERATION: AC/DE
; returns: AC (quotient), HL (remainder)
; source: WKT
DIV_16_16:  ld      HL, 0
            ld      B, 16
DV16_16_LP: sla     C
            set     0,C         ; this simulates the SLL undocumented instruction
            rla
            adc     HL,HL
            sbc     HL,DE
            jr      NC, $+4
            add     HL,DE
            dec     C
            djnz    DV16_16_LP
            ret


; ----------------------------------------------------------------------
; divide a 32-bit number by a 16 bit-number
; (32/16 division)
;
; inputs: ACIX (Dividend), DE (divisor)
; destroys: HL,IX,BC
; OPERATION: ACIX/DE
; returns: ACIX (quotient), HL (remainder)
; source: WKT

DIV_32_16:  ld      HL,0
            ld      B,32
DIV_32_16LP:add     IX,IX
            rl      C
            rla
            adc     HL,HL
            jr      C,DIV_32_16OF
            sbc     HL,DE
            jr      NC,DIV_32_16SB
            add     HL,DE
            djnz    DIV_32_16LP
            ret
DIV_32_16OF:or      A                   ; overflow
            sbc     HL,DE
DIV_32_16SB:inc     IX                  ; set bit
            djnz    DIV_32_16LP
            ret
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

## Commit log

2019-02-07 First upload
    First upload of schematics, code and other stuff
2019-02-21 CTC interrupt test: code revision; added schematic and picture.
2019-02-21 EEPROM programmer: schematic update; added picture.
2019-02-21 Changed name for Serial comm test folder; added picture of serial circuit
2019-03-08 Release 1.0 - Unified firmware with counter for 100ths of a second, and function to print the timer contents
2019-04-07 Fixed pin change error on I/O selector's inputs
2019-06-01 Added picture of Z80 test circuit
2019-09-18 Added manuals for main devices (CPU, PIO, SIO, CTC, PSG, VDP)
2019-10-13 New release R2.4: added new semi-graphic & graphic fonts for Screen 1 mode (8x8 bits), and reorganized current charset
2019-10-27 Added Reversi (aka Othello) game to play a board game against CPU
2019-11-08 Slowed down the INKEY sniffing code to be able to read a key pressure
2019-12-07 New schematic that fixes a bug into the PSG management that lead to wrong dialogs with the chip
2019-12-23 Added keyboard matrix schematic to show contacts in case a C16 keyboard isn't available
2020-01-24 Revision of a couple of BASIC games
2020-01-27 New firmware release R2.13: complete support for ALT and CTRL keys to print graphics chars
2020-04-08 Fixed a couple of typo
2020-05-14 Fixed a little design bug into a couple of 8x8 graphic chars
2020-05-17 Fix bug into schematic (missing resistor)
2020-05-22 Added KiCad schematics & libs
    [LM80C-R6.kicad_pcb, LM80C-R6.sch]
2020-05-23 New firmware release R3.12 - compliant with schematics v. R6
2020-09-28 "Piano.bas" example set to upper case
2020-12-29 Typo fixing and code cleaning
    [astronave_farmer.bas]
2020-12-29 Schematics folder re-organization
    [LM80C-R6.kicad_pcb, LM80C-R6.sch]
2021-01-03 Development stage
2021-01-04 New firmware releases 3.17 (LM80C) and 1.03 (LM80C 64K)
    [LM80C 64K.kicad_pcb, LM80C 64K.sch]
2021-03-08 New firmware releases 3.20 & 1.10 with LM80C DOS support
    [LM80C 64K.sch]
2021-03-28 Fixed a const name into the source code that interfered with the assembler and lead to an error into the binary
2021-11-08 Changed Kicad link
2022-03-20 Added Zilog libs for KiCAD schematics
